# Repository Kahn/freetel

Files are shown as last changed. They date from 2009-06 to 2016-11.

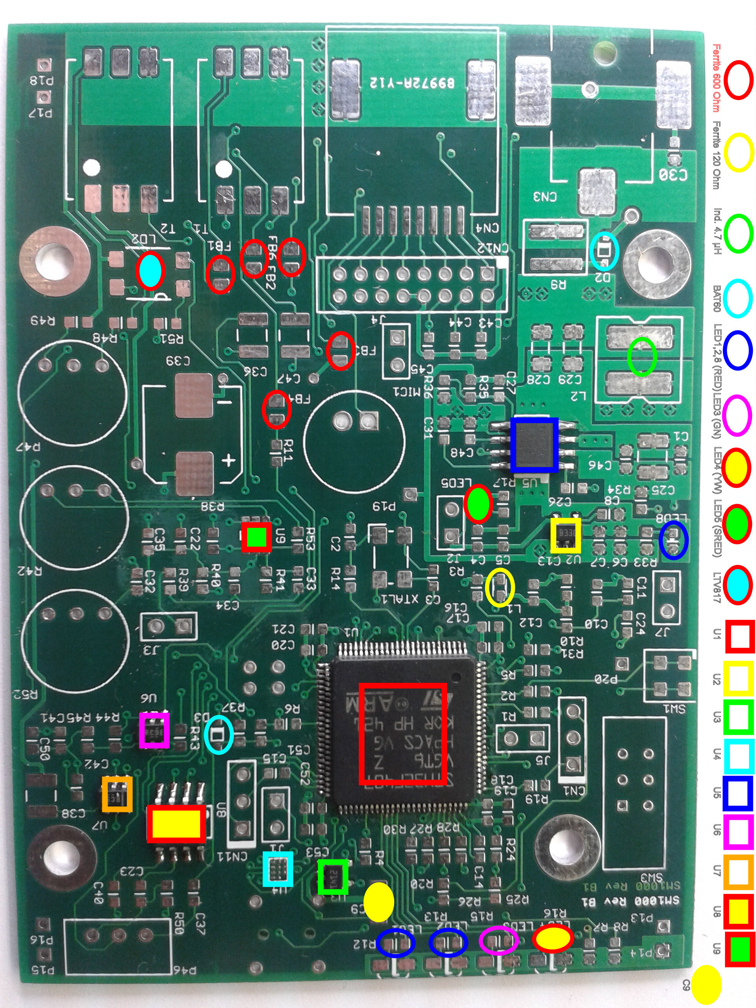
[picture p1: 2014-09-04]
smartmic/doc/other_Parts.jpg

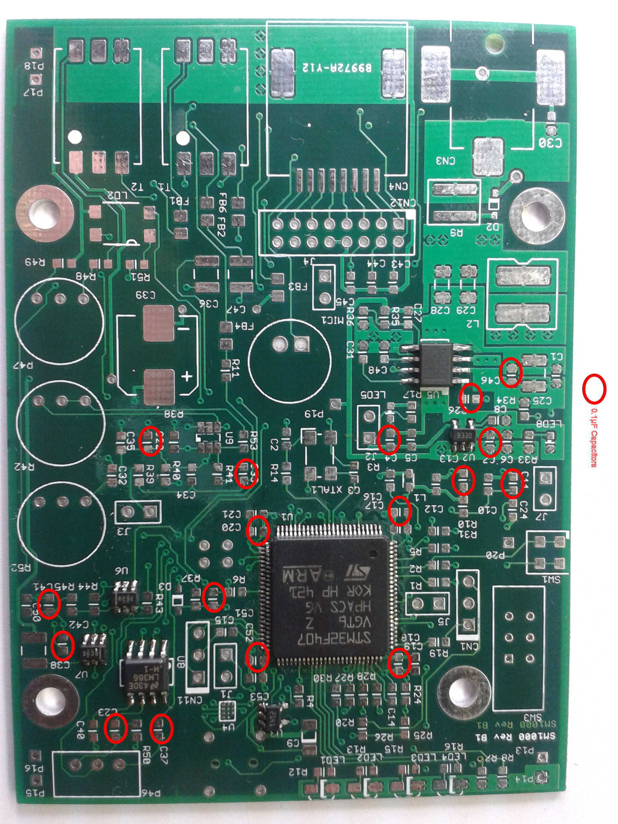
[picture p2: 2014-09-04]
sm2000/doc/Assembly_100nF.jpg

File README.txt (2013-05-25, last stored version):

README.txt for foxy
David Rowe
May 25 2013

Introduction
------------

Simple Google Maps application to plot Fox Hunt bearings.

* Screen shot: foxy_screenshot.png

* Based on Google maps V3 API.

* Light weight: On the server we have just a few CGIs and a text file
  database.  A browser cookie is used for storing configuration
  information.  The CGIs are a few lines of shell script, so can run
  on any machine.  Installation involves copying a few files and
  setting a few permissions.

Using Foxy
----------

1/ Point your browser at http://yourserver/foxy.html

2/ Enter the bearing in the text box and left click to add a bearing.

3/ Left click on a bearing to get information.  Right click to delete
a bearing.

Implementation Notes
--------------------

Foxy is implemented in Javascript (foxy.html).  A simple text database
file /var/www/foxy/bearings.txt is used to store bearing
information. Very simple 1 page CGIs written in shell script are used
to access the bearing database.

A browser cookie is used to store config information like the current
map centre.

All the CGI scripts assume a hard coded path of /var/www/bearings for
the bearings.txt database.

Files
-----

  foxy.html        - Javascript code for Foxy
  foxy.css         - style sheet

"cgi-bin" directory:

  addbearing.cgi   - adds a bearing to bearings.txt
  delbearing.cgi   - deletes a bearing from bearings.txt
  getbearings.cgi   - reads bearings.txt database
  cleardb.cgi      - clears database, removing all bearings

Software
--------

You need:

1/ A web server. Apache is assumed in the /usr/lib/cgi-bin path below.
   The paths may be different for other web servers.  Note the path
   to /var/www/foxy is hard coded in the CGI scripts so it's
   best not to change that.

Installation
------------

1/ Server PC

  $ svn co https://freetel.svn.sourceforge.net/svnroot/freetel/foxy
  $ cd foxy
  $ sudo mkdir /var/www/foxy
  $ sudo chmod 777 /var/www/foxy
  $ cp foxy.css foxy.html /var/www/foxy
  $ sudo cp cgi-bin/* /usr/lib/cgi-bin

Tests
-----

1/ Test reading and writing bearings.txt database with your browser:

   http://localhost/cgi-bin/addbearing.cgi?lat=123&lng=456&bearing=90

   $ cat /var/www/foxy/bearings.txt
   123,456,90

   http://localhost/cgi-bin/delbearing.cgi?lat=123&lng=456

   $ cat /var/www/foxy/bearings.txt
   (empty file)

Debugging
---------

1/ Monitor Apache log:

  $ tail -f /var/log/apache2/access.log

2/ Use Firebug on Firefox to single step, set breakpoints etc.

3/ Check bearings.txt database, each line is (lat, lng, IP):

  # cat /var/www/foxy/bearings.txt 

  -34.88548650005714,138.55225324630737,90
  -34.88006501016277,138.55394840240479,180
  -34.87893842193011,138.55278968811035,265
  -34.882511765792316,138.55210304260254,10

4/ The "foxy001" cookie stores our state. On Firefox 3.5 you
   can remove the foxy cookie using Edit-Preferences-Privacy, then
   click on "remove individual cookies".

5/ To manually reset to defaults:
   
   * move to another page (cookie is saved when we exit page)
   * rm -f /var/www/foxy/bearings.txt
   * Delete cookie using step (4) above

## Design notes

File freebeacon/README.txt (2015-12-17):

README.txt for FreeDV Beacon (FreeBeacon)
David Rowe, John Nunan, Richard Shaw
Dec 2015

Introduction
------------

FreeDV 1600 beacon.  Listens for FreeDV signals, then transmits a
reply. Places the received signal files on a web server. Requires a
Linux machine with a sound card and RS232-PTT interface to your radio.
Just one sound card is required.  Can run on machines as small as a
Raspberry Pi.

When a "trigger" string is detected in the rx FreeDV text message
(e.g. "hello beacon", or the beacon callsign), the beacon will
transmit a signal report back to you.

It requires a "txfilename" wave file to transmit, e.g. some one saying
"Hi, I am a FreeDV beacon blah blah".  The signal report is encoded
into the transmit text message.  Make the wave file long enough so
that the the signal report is repeated a few times, say 30
seconds. Transmit will stop when the "txfilename" wave file is played
once.

Freebeacon saves the received audio from the radio AND the decoded
audio as wavefiles.  Use "wavefilewritepath" to specify where they are
written.  The file name is a date and time stamp. The length is
limited to 60 seconds. If you set "wavefilewritepath" to a listable
webserver directory the files will be available for download on the
Web.  To avoid filling your file system write a cron job to clean
these files up once a day.

If your input audio device is stereo note we only listen to the left
channel.

If you have a RS232 serial port (specified with "-c") RTS and DTR is
raised on transmit to key your transmitter, and lowered for receive.

If you are using Raspberry Pi you can use one of the GPIOs for PTT
control of your transmitter using the "--rpigpio" option.  You need to
use the BCM GPIO number so "--rpigpio 11" uses pin 23 of the GPIO
connector.

A whole lot of code was lifted from freedv-dev for this program.

TODO
----

  [X] 48 to 8 kHz sample rate conversion
  [X] Port Audio list devices
  [X] command line processing framework
  [X] beacon state machine
  [X] install codec2
  [X] attempt debug sound dongle
      [X] modify for half duplex
      [X] sample rate option
      [X] prog sound dongle debug
  [X] RS232 PTT code
  [X] writing to wave files
  [X] test mode to tx straight away then end, to check levels, debug RS232
  [ ] FreeDV 700 support
  [ ] daemonise
      + change all fprintfs to use log file in daemon mode
  [X] test on laptop
  [X] test on RPi
  [ ] writing text string to a web page (cat, create if doesn't exist)
  [ ] samples from stdin option to work from sdr
  [ ] monitor rx and tx audio on another sound device
  [ ] option to not tx, just log info, for rx only stations
  [ ] Hamlib support for keying different radios
  [ ] basic SM1000 version
      + add mode, state machine
      + has audio interfaces, PTT, so neat solution

Building and Installation
-------------------------

1. sudo apt-get install subversion cmake sox libsamplerate0-dev portaudio19-dev libsndfile1-dev

2. Build and Install codec2-dev:

    svn co http://svn.code.sf.net/p/freetel/code/codec2-dev
    cd codec2-dev
    mkdir build_linux
    cd build_linux
    cmake ../
    make
    sudo make install

    Note: On my Ubuntu 14 and RPi I had to add an extra search path to the
    ld.conf.d directory to match the path the codec2 .so was installed
    in.

    Check it has found libcodec2.so using:

    ldconfig -v | grep codec2

3. Build FreeBeacon:

    svn co http://svn.code.sf.net/p/freetel/code/freebeacon
    cd freebeacon
    mkdir build_linux
    cd build_linux
    cmake ../
    make

4. Testing:

    Plug in your USB sound card and USB RS232 devices.  Use alsamixer
    to adjust levels on your sound card. F6 lets you select sound cards

    Usage:
      ./freebeacon -h

    List sound devices
      ./freebeacon -l

    Example usage:
      ./freebeacon -c /dev/ttyUSB1 --txfilename ~/codec2-dev/wav/vk5qi.wav --dev 4 -v --trigger hello

    Testing your PTT by making it jump straght into tx mode:
      ./freebeacon -c /dev/ttyUSB1 --txfilename ~/codec2-dev/wav/vk5qi.wav --dev 4 -v --trigger hello -t

    Testing sound cards on RPi:

      $ arecord -l

        **** List of CAPTURE Hardware Devices ****
        card 1: Audio [RIGblaster Advantage Audio], device 0: USB Audio [USB Audio]
        Subdevices: 1/1
        Subdevice #0: subdevice #0

      $ arecord -D hw:1,0 -f S16_LE -r 48000 test.wav
      $ aplay test.wav

    Testing:

      As a first step try playing freebeacon_test.wav from another PC
      into the freebeacon machine input, this file has the trigger
      string "hello" in the txt msg.

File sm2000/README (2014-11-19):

README for SM1000 Project
Rick Barnich KA8BMA and David Rowe VK5DGR 
Created 14 August 2014

Introduction
------------

The SM1000 is an embedded hardware product that allows you to run
FreeDV without a PC. Just plug it into your SSB or FM radio, and you
now have Digital Voice (DV). It’s based on a STM32F4 micro-controller,
has a built in microphone, speaker amplifier, and transformer isolated
interfaces to your radio. It’s about the size of a smart phone, and
can be held in you hand and used like a regular PTT microphone, or sit
near your radio in a small box. SmartMic is slated for production
production in 2014 and will retail for US$195.

The SM1000 is open hardware (TAPR license) and runs open software
(LGPL license).

Notes
------

The original name for the project was SmartMic.  However as this name
is tradmarked in the USA we are now calling the project "the
SM1000".

The SM1000 schematic and PCB are design using Eagle.

The firmware lives in codec-dev/stm32.

Directories
-----------

doc         Documentation, use cases, block diagram, prototype assembly images
SM1000-A    First pass design that was never manufactured but used to collect
            review comment
SM1000-B    Prototype SM1000, small qty of PCBs made and hand loaded
SM1000-C    pre-Beta SM1000. Changes to B to reflect testing / debug process.
            Just 2 made to check changes before Qty 100 beta run.
SM1000-D    Beta SM1000

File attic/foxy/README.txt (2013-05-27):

README.txt for foxy
David Rowe
May 25 2013

Introduction
------------

Simple Google Maps application to plot Fox Hunt bearings.  When run on
a phone it automatically detects position and compass bearing. Placing
Bearings can be placed with a mouse click on non-mobile devices. The
bearings are stored in a text file database so can be shared by anyone
who can reach the server.

* Screen shot: foxy_screenshot.png

* Based on Google maps V3 API.

* Light weight: On the server we have just a few CGIs and a text file
  database.  A browser cookie is used for storing configuration
  information.  The CGIs are a few lines of shell script, so can run
  on any machine.  Installation involves copying a few files and
  setting a few permissions.

* Foxy will stand alone without the server & CGIs, but bearing storage
  won't be persistent and bearings can't be shared.  Good for demos or
  when you can't reach the Internet.

BUGS
----

On mobile devices:
+ Click to add bearings places the bearing at a location offset from the tap location
+ Double click doesn't remove bearings on mobile devices.

Using Foxy
----------

1/ Point your browser at http://yourserver/foxy.html

2/ If running on your phone your bearing will be updated
automatically.  Click on add bearing to add a bearing from your
current position to the map.

3/ The "where Am I" button re-centers the map on your current
position.  This is useful when scroll and zooming moves your position.

4/ The "Click to Add Bearing" check box allow manual placement of
bearings with a mouse click.  Useful for demo and development on
non-mobile devices such as desktops and laptops. This should be
unchecked on mobile devices as pinching/scrolling often generates
spurious "click" events leading to unwanted bearings.

5/ Double click on a bearing to delete it.

Implementation Notes
--------------------

Foxy is implemented in Javascript (foxy.html).  A simple text database
file /var/www/foxy/bearings.txt is used to store bearing
information. Very simple 1 page CGIs written in shell script are used
to access the bearing database.

A browser cookie is used to store config information like the current
map centre.

All the CGI scripts assume a hard coded to a path of
/var/www/foxy/bearings.txt for the bearings.txt database.

Files
-----

  foxy.html        - Javascript & HTML code for Foxy
  foxy.css         - style sheet

"cgi-bin" directory:

  addbearing.cgi   - adds a bearing to bearings.txt
  delbearing.cgi   - deletes a bearing from bearings.txt
  getbearings.cgi  - reads bearings.txt database
  cleardb.cgi      - clears database, removing all bearings

Software
--------

You need:

1/ A web server. Apache is assumed in the /usr/lib/cgi-bin path below.
   The paths may be different for other web servers.  Note the path
   to /var/www/foxy is hard coded in the CGI scripts so it's
   best not to change that.

Installation
------------

1/ Server PC

  $ svn co https://freetel.svn.sourceforge.net/svnroot/freetel/foxy
  $ cd foxy
  $ sudo mkdir /var/www/foxy
  $ sudo chmod 777 /var/www/foxy
  $ cp foxy.css foxy.html /var/www/foxy
  $ sudo cp cgi-bin/* /usr/lib/cgi-bin

Tests
-----

1/ Test reading and writing bearings.txt database with your browser:

   http://localhost/cgi-bin/addbearing.cgi?lat=123&lng=456&bearing=90

   $ cat /var/www/foxy/bearings.txt
   123,456,90

   http://localhost/cgi-bin/delbearing.cgi?lat=123&lng=456

   $ cat /var/www/foxy/bearings.txt
   (empty file)

Debugging
---------

1/ Monitor Apache log:

  $ tail -f /var/log/apache2/access.log

2/ Use Firebug on Firefox to single step, set breakpoints etc.

3/ Check bearings.txt database, each line is (lat, lng, IP):

  # cat /var/www/foxy/bearings.txt 

  -34.88548650005714,138.55225324630737,90
  -34.88006501016277,138.55394840240479,180
  -34.87893842193011,138.55278968811035,265
  -34.882511765792316,138.55210304260254,10

4/ The "foxy001" cookie stores our state. On Firefox 3.5 you
   can remove the foxy cookie using Edit-Preferences-Privacy, then
   click on "remove individual cookies".

5/ To manually reset to defaults:
   
   * move to another page (cookie is saved when we exit page)
   * rm -f /var/www/foxy/bearings.txt
   * Delete cookie using step (4) above

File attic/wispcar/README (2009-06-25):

wispcar README
--------------

David Rowe 22 June 2009

stty is a WRT54GL OpenWRT  binary utility some one had compiled on the web, used
for setting serial port speeds

wispcar.asm is the original code as per the blog post: http://www.rowetel.com/blog/?p=68

wispcarb.asm has a mod to the watchdog timer to stay off, used for battery testing

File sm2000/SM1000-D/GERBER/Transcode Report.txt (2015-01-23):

   ---- Transcoding 'C:\Users\rbarnich\smartmic\SM1000-D\GERBER\SM1000-D.ast' ----   Fri Jan 23 12:14:49 2015

D10   --> D100
D11   --> D101
D12   --> D102
D13   --> D103
D14   --> D104
D15   --> D105
-----------------------------------------------------------------

   ---- Transcoding 'C:\Users\rbarnich\smartmic\SM1000-D\GERBER\SM1000-D.bps' ----   Fri Jan 23 12:14:49 2015

D10   --> D106
D11   --> D107
D12   --> D108
D13   --> D109
-----------------------------------------------------------------

   ---- Transcoding 'C:\Users\rbarnich\smartmic\SM1000-D\GERBER\SM1000-D.drt' ----   Fri Jan 23 12:14:56 2015

D10   --> D110
D11   --> D111
D12   --> D112
D13   --> D113
-----------------------------------------------------------------

   ---- Transcoding 'C:\Users\rbarnich\smartmic\SM1000-D\GERBER\SM1000-D.L1' ----   Fri Jan 23 12:14:56 2015

D10   --> D114
D11   --> D115
D12   --> D116
D13   --> D117
D14   --> D118
D15   --> D119
D16   --> D120
D17   --> D121
D18   --> D122
D19   --> D123
D20   --> D124
D21   --> D125
D22   --> D126
D23   --> D127
D24   --> D128
D25   --> D129
D26   --> D130
D27   --> D131
D28   --> D132
-----------------------------------------------------------------

   ---- Transcoding 'C:\Users\rbarnich\smartmic\SM1000-D\GERBER\SM1000-D.L2' ----   Fri Jan 23 12:14:56 2015

D10   --> D133
D11   --> D134
D12   --> D135
D13   --> D136
D14   --> D137
D15   --> D138
D16   --> D139
D17   --> D140
D18   --> D141
D19   --> D142
D20   --> D143
D21   --> D144
D22   --> D145
D23   --> D146
-----------------------------------------------------------------

   ---- Transcoding 'C:\Users\rbarnich\smartmic\SM1000-D\GERBER\SM1000-D.L3' ----   Fri Jan 23 12:14:56 2015

D10   --> D147
D11   --> D148
D12   --> D149
D13   --> D150
D14   --> D151
D15   --> D152
D16   --> D153
D17   --> D154
D18   --> D155
D19   --> D156
D20   --> D157
D21   --> D158
D22   --> D159
D23   --> D160
D24   --> D161
D25   --> D162
-----------------------------------------------------------------

   ---- Transcoding 'C:\Users\rbarnich\smartmic\SM1000-D\GERBER\SM1000-D.L4' ----   Fri Jan 23 12:14:56 2015

D10   --> D163
D11   --> D164
D12   --> D165
D13   --> D166
D14   --> D167
D15   --> D168
D16   --> D169
D17   --> D170
D18   --> D171
D19   --> D172
D20   --> D173
D21   --> D174
D22   --> D175
D23   --> D176
D24   --> D177
D25   --> D178
D26   --> D179
D27   --> D180
D28   --> D181
D29   --> D182
D30   --> D183
D31   --> D184
D32   --> D185
D33   --> D186
D34   --> D187
D35   --> D188
-----------------------------------------------------------------

   ---- Transcoding 'C:\Users\rbarnich\smartmic\SM1000-D\GERBER\SM1000-D.oln' ----   Fri Jan 23 12:14:56 2015

D10   --> D189
-----------------------------------------------------------------

   ---- Transcoding 'C:\Users\rbarnich\smartmic\SM1000-D\GERBER\SM1000-D.slk' ----   Fri Jan 23 12:14:56 2015

D10   --> D190
D11   --> D191
D12   --> D192
D13   --> D193
D14   --> D194
D15   --> D195
-----------------------------------------------------------------

   ---- Transcoding 'C:\Users\rbarnich\smartmic\SM1000-D\GERBER\SM1000-D.smb' ----   Fri Jan 23 12:14:56 2015

D10   --> D196
D11   --> D197
D12   --> D198
D13   --> D199
D14   --> D200
D15   --> D201
D16   --> D202
D17   --> D203
D18   --> D204
D19   --> D205
D20   --> D206
D21   --> D207
D22   --> D208
D23   --> D209
D24   --> D210
D25   --> D211
D26   --> D212
D27   --> D213
D28   --> D214
D29   --> D215
-----------------------------------------------------------------

   ---- Transcoding 'C:\Users\rbarnich\smartmic\SM1000-D\GERBER\SM1000-D.smt' ----   Fri Jan 23 12:14:56 2015

D10   --> D216
D11   --> D217
D12   --> D218
D13   --> D219
D14   --> D220
D15   --> D221
D16   --> D222
D17   --> D223
D18   --> D224
D19   --> D225
D20   --> D226
D21   --> D227
D22   --> D228
D23   --> D229
D24   --> D230
D25   --> D231
D26   --> D232
D27   --> D233
D28   --> D234
D29   --> D235
D30   --> D236
D31   --> D237
D32   --> D238
D33   --> D239
D34   --> D240
D35   --> D241
D36   --> D242
D37   --> D243
D38   --> D244
D39   --> D245
D40   --> D246
D41   --> D247
D42   --> D248
D43   --> D249
D44   --> D250
D45   --> D251
D46   --> D252
D47   --> D253
-----------------------------------------------------------------

   ---- Transcoding 'C:\Users\rbarnich\smartmic\SM1000-D\GERBER\SM1000-D.tps' ----   Fri Jan 23 12:14:56 2015

D10   --> D254
D11   --> D255
D12   --> D256
D13   --> D257
D14   --> D258
D15   --> D259
D16   --> D260
D17   --> D261
D18   --> D262
D19   --> D263
D20   --> D264
D21   --> D265
D22   --> D266
D23   --> D267
D24   --> D268
D25   --> D269
D26   --> D270
D27   --> D271
D28   --> D272
D29   --> D273
D30   --> D274
-----------------------------------------------------------------

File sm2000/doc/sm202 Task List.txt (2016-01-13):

Goals
=====

To demonstrate advanced VHF/UHF Digital Voice features on an open software and hardware platform.

[ ] feasibility of "$100" TDMA repeater
    + show our radio working as a TDMA repeater without a diplexor
    + temporary mount on hill top, city wide coverage
    + no split so saves spectrum, potentially low cost (to fill coverage gaps easily)
[ ] 10dB weak signal performance gain over analog FM and 1st gen DV
    + "smackdown" video of current state of the art against our solution
[ ] diversity to handle multipath
    + TDMA diversity, switch rx LO quickly
    + demo overcoming large fades
[ ] wideband audio
    + for example use 10dB gain to send 10 kbit/s Skype type audio over channel
[ ] high bit rate data
    + 10 - 100 kbit/s
[ ] low cost
    + several hundred $ sales price
    + approx $100 BOM

Project Workflow
================

Manhatten Prototype -> Sch Entry -> PCB Design -> Load and Test -> Demos
       /\                                               /\
       ||                                               ||
 Proto Modem SW                                      Modem SW
                                                     UI SW
                                                     Driver SW

Themes
======

+ Full SDR so we can define waveform
+ SSB up and down converters to allow full waveform control
+ no SoCs
+ Demos of advanced DV features is "enough".  We don't need
  sparkling performance in other areas such as all RF specs.

Task List
=========

[ ] Documentation
  [X] Block diagram
  [X] Uses cases in paragraph form
  [X] RF design spreadsheet
      [X] cascaded Gain 
      [X] cascaded NF
      [ ] cascaded IP3
  [ ] Power budget spreadsheet
      [ ] Current per active device
      [ ] Power dissipation per active device
      [ ] Resistor power dissiapation
          + RF bias currents can be high
          + don't want to smoke and SM parts
      [ ] Summary for each rail
  [ ] Specs
      + We don't care too much about IP3, Blocking, ACS, tx phase noise,
        power consumption, they can be modest, equivalent to middle of 
        range VHF radios.
      + We do care about the following.  Check off when demonstrated on
        prototype of Rev A
      [X] 12VDC operation
      [X] NF < 2dB
      [X] MDS (1200 bit/s 2FSK at BER < 0.03) of < -133dBm   
      [ ] MDS (1200 bit/s 2FSK at BER < 0.03) of < -130dBm  (3dB de-sensitisation)
          with -20dBm blocking signal outside of 144 - 148 MHz
          [ ] spot check at 88, 108, 150, 200 MHz
      [ ] 1W tx power with spurious emissions -45dBC

[ ] UI ideas:
    [ ] ESP8266 boards: $7 Wifi interface
        + Or Edwin's boards
    [ ] Twitter's open source 'Bootstrap'
    [ ] BTLE module from Adafruit
    [ ] Websocket
        + what does server look like?
    [ ] Hamlib back end?

[ ] Remaining Manhatten Prototype Tasks
    + Manhatten Style prototype used to build and test as much as possible
    [X] 1W PA
    [X] PIN diode TR switch
    [X] PA filter
    [X] Input (1st) BPF
    [ ] TDMA switching
        [ ] how to switch PS rails
        [ ] tx and rx meet specs

[ ] Parts Selection
    + cross off below when part selected and tested in prototype
    [ ] New audio amp chip
        + bit better, higher power than LM386
    [X] General purpose VHF transistors
    [X] General purpose IF transistors
    [X] 1st mixer: ADE-1 
    [X] RF switches
        + Brady has suggest AS17992LF
    [X] 1W PA transistor
    [ ] LCD
        + Could use cheap Nokia 5110, at least in first rev. Well documented and libraried.
    [ ] encoder
    [X] first LO: Si5351
        + also 2nd LO
        [X] optional Si570
            + low phase noise soldered in option, provide footprint
            + Si5351 still used as 2nd LO
    [X] Prototype parts list to Edwin for review
        + just major parts, semiconductors
        + make sure they are obtainable
        + look for low cost equivalents

[ ] Use Cases
    + need software/test procedure to support the following use cases
    [ ] test modes
        + useful for devevelopment and debugging
        [ ] rx BER
            + prints BER on LCD when continuous 2FSK/4FSK test frames sent
        [ ] tx BER
            + sends continuous test frames using 2FSK/4FSK
    [ ] VHF FM radio
    [ ] Open Source PTT VHF FreeDV radio
        + continuous or TDMA?  Can they be the same?
    [ ] TDMA Repeater
    [ ] Diversity rx
        + use 2nd output from 5351
    [ ] Setting frequency and mode
        + how to select frequency?  What combinations of buttons
          and encoder.
        + do we need a full 0-9 keyboard?
        + should we use a PC or remote device as primary input device
        + does position of buttons/encoders/style of buttons make it easy 
          to use, e.g. set a frequency
    [ ] Changing waveform

[ ] Software Modules
    + see sm201 Block Diagram page 2
    [ ] VHF Modem
        + cont mode first, we can adpat to burst/TDMA mode next
        [ ] ideal non-coherent 2FSK/4FSK BER versus Eb/No perf
        [ ] tracks +/- 500ppm sample clock offsets with no impl loss
        [ ] +/- 5kHz frequency offset acquisition in 1000ms on continuous signal
        [ ] C/Octave versions
        [ ] user defined symbol rate (nominal 1200, 2400), carrier freq, sample rate
            [ ] can it cope with say 3000 symb/s to allow time for TDMA guard times and sync?
                + e.g. a gd fit with integerat Fs/Rs ratios
                + might need TDMA design at same time to answer this question
        [ ] variable nin style demod C function call, approx 20ms packets
            [ ] DR to review function headers
        [ ] automated test script to copare C and Octave units results
            + to ensure identical implementation 
        [ ] command line ./mfsk_tx and ./mfsk_rx 
        [ ] demo OTA (1200/2400/2FSK/4FSK) using SSB radios or SDR
    [ ] VHF protocol
        + do we need two modes, cont & TDMA?
        + or is there a way to combine?  So one rx does both?  Autobaud?
        + can we optionally use FM friendly machester encoded waveform?
    [ ] TDMA framework around modem, burst modem
    [ ] rx TDMA diversity
    [ ] test frame tx/rx modes
    [ ] New Drivers
        [ ] LCD
        [ ] Encoder
        [ ] Si570
            [ ] TDMA clock switching
        [ ] Si5351
            [ ] TDMA clock switching              
    [ ] UI for setting a frequency
    [ ] USB console
    [ ] USB tx/rx signal streaming
    [ ] Code to support running Modes
        [ ] Analog FM
        [ ] TDMA repeater
        [ ] Diversity RX
        [ ] FreeDV PTT TDMA radio

[ ] Risks
    + check off when risk has been nailed, e.g. by experiment/test
    [X] Can we use ADE-1 bir-directional?
        + yes, use TIA and PIN diode switching
    [X] coupled res in shielded box or cots part?
        + make little shields out of blacnk PCB
        + just make box, doesnt need lids
    [X] how to switch mixer/xtal filter
        + tx modulator transistor is part of rx load
        + alo use of TIA
    [X] Is NE602/612 still easy to get?
    [X] ADC perf
        + SFDR etc, which is why we run it as 100kHz
        + if not good enough we'll need an external ADC
        + test against two tone, MDS and ACR
        + Result: met 135dBm spec on prototype so OK
    [X] Power dissipation of active devices and resistors
        + easy to exceed limits in SM resistors and transistors
        + RF drivers draw lots of current
        + mitigation: power spereadhseet in doc section
        + looks good, see also email to Rick 28/12/15 sub: "sm205 powr budget"
    [X] IF termination of 1st mixer
        + how to test if this is OK -> Sweep with R/L bridge
    [X] do we need a way to bypass the LNA?
        + or is it OK even with strong signals
        + mitigation: cascaded IP3 calculations in doc section
                      if this compares to current middle range radios then OK
        + decided to keep in cct, pending strong sig tests
    [ ] xtal filter power
        + what is the limit, how many dBm are we using at the moment?
    [X] prototype RX works 
        + 1200 bit/s 2FSK at < -133dBm with BER < 0.03
        + theory with NFis -134dBm at 0.02
    [ ] prototype TX works
        + 1200 bit/s 2FSK at 1W spurious -45dBC
        + demod by SDR at high SNR with 0 BER
    [ ] TDMA switching
        + demonstrate design supports tx/rx switching fast enough for TDMA
        [ ] tx/rx power supply rail swicthing
    [X] RF detector
        + pwr calibration, shutdown with no load
    [X] PA
        [X] 1W for 5 minutes
        [X] adjust PA from uC via Vgg
            + not tested from uC yet
    [ ] Dual freq TDMA
        + tx and rx?  We need a way to tx on two different freqs
        + use same clock for tx and rx?
    [X] 2ND LO dist and swicthing
        + 150pF to NE602?
        + attenuator?
        + selecting LOs?
    [ ] Spreadsheet with Z matches
    [ ] check power consumption on each rail matches regulator limits

[ ] Sch Entry
    [X] linear reg option for vadc ADC and vref
        + jumper select to test
    [ ] put extra 0805 or 1206 components in parallel for Z matching and DNL
        + e.g. on collectors and emitters of RF amps
        + between building blocks
    [ ] inductors
        [X] coil winding details if air core
        [X] tolerance
        [X] statement on Q so we know if we can subs SM or need Hi-Q air-core
        [X] alignment of coils WRT each other to prevent coupling
        [ ] location of shields if rqd
        [ ] how to adjust/if adjustment rqd
            + e.g. adjust filter by variation in coild spacing against filter spec
    [X] 4 by 0.1 inch pin headers in a square pattern to disconnect building blocks    
    [X] select Si570 with a jumper
    [ ] review of foot prints for discretes
        + ease of debug, e.g. if we need to add a LC filter
        + power handling
    [X] check package of each L
        + make sure enough room for hand wound air core versions
    [X] specify locations of 4 pin 50 ohm breaks
        + 0805 0 ohm, or break for isolation and testing
    [X] PS filter for PA
    [X] research TXCO for si5351 clock input
        + perhaps include as option
        + does it have to be 25MHz?
        + decided not to run with TXCO for prototype, as freq stab not critical
    [ ] how to connect SCA/SCL on clock chips to uC?
        + is there a separate enable?
    [ ] LEDs for control signals/rails
    [X] Add a Av=2 op-amp to take 3v3 DAC max from uC to 5V
        max for Vgg driving PA final Q14.  Will need to be powered by 5V rail.
        This is a preacuation in case we need > 3V for some FETs
    [ ] Vgg PWM filtering
        + we use PWM to genrate a bias for VGG
        + this needs to be filtered so we don't modulate the PA output
        + but we also need a faily fast respomse time, e.g. 1ms from
          0V to Vgg set point to modulate PA power for TDMA.
    [ ] consider shared clock for Si5351 and uC
   
[ ] Rev A PCB Layout
    [ ] footprints for all devices
    [ ] will air core inductors be thru hole parts?
        + nice big pads as some rework likely
    [ ] avoid vias for RF nets, all routing on top layer
        + gnd plane next layer down
    [ ] block diagram showing map of building blocks
        + separate analog and digital        
    [ ] shields
        [ ] where do we put sheilds
        [ ] how to fabricate?
            + try small pieces of black PCB
        [ ] foot prints
    [ ] probe points
        + VHF freindly with nearby grounds
        + something I can sit a CRO probe in, with short ground, like 2 thru hole donuts
        + 1k series resistor to 50 ohm points so we can probe with 50 ohm spec-an or scope
        + can we get a 50-ohm probe for cro or spec-an?  
          So mechanically it can sit on board?
    [ ] 50 ohm points for spec an?
    [ ] 4 pin 0.1 inch headers to disconnect building blocks so we can insert 
        tracking gen and spec an

[ ] Manufacture
    [ ] is it feasible to have 6 turn coils with one turn taps in production?
        + what are the alternatives
    [ ] can people wind toroids?
    [ ] How will we test and align?

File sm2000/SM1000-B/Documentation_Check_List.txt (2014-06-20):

PCB Documentation Check List

PCB:  ____________________     ASM: ____________________     VARIANT: ____________________

DATE: ____________________     By:  ____________________     Form: 06/20/14

1.  [ ]	Run ERC on schematic & fix any errors.
2.  [ ]	Run DRC on pcb & fix any errors.
3.  [ ]	Update revision level and  titles on schematic and PCB.
4.	[ ] Run BOM-AM-19 on schematic and check for undefined parts. 	
5.	[ ]	Generate BOM.csv  file. Use parts data base & update/add new parts.
6.  [ ]	Generate BOM.xls and BOM.pdf files and move to MFG folder.
7.	[ ]	Generate LOC.csv file.
8.  [ ]	Generate LOC.xls and LOC.pdf files and move to MFG folder
9.	[ ]	Generate  Schematic PDF file and move to MFG folder.
10.	[ ]	Run drillcfg (inches)
11.	[ ]	Run drilllegend.ulp and generate drill table(drill legend) on PCB.
12. [ ]	Generate DRL-TBL.pdf (DRILL TABLE) and copy to MGF folder.
13.	[ ]	Run CAM   job 4LPlus-Sunstone.cam on board.
14. [ ] Run CAM job Exellon.cam on board.
15.	[ ]	Move Gerber files to GERBER folder
16.	[ ]	Use Viewmate to check layout & produce .PDF file of all Gerber layers. Move pdf to MFG folder
17.	[ ]	Generate & move .PDF of BOM & LOC files to MFG folder
18. [ ]	Generate assembly drawing for top & bot layers. Move .pdf to MFG folder.
19.	[ ]	Update readme files(see other cards) for Gerber & MFG folders.
20. [ ]	Add dimensions to .brd. Generate .pdf file and move to MFG folder
21.	[ ]	Generate  .zip files on files in GERBER and MFG folders respectively.
22. [ ]	Move .sch, .brd, .lbr, MFG.zip & GERBER.zip to RELEASE Folder.

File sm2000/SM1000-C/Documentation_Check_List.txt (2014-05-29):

PCB Documentation Check List

PCB:  ____________________     ASM: ____________________     VARIANT: ____________________

DATE: ____________________     By:  ____________________

1.  [ ]	Run ERC on schematic & fix any errors.
2.  [ ]	Run DRC on pcb & fix any errors.
3.  [ ]	Update revision level and  titles on schematic and PCB.
4.	[ ] Run BOM-AM-19 on schematic and check for undefined parts. 	
5.	[ ]	Generate BOM.csv  file. Use parts data base & update/add new parts.
6.  [ ]	Generate BOM.xls and BOM.pdf files and move to MFG folder.
7.	[ ]	Generate LOC.csv file.
8.  [ ]	Generate LOC.xls and LOC.pdf files and move to MFG folder
9.	[ ]	Generate  Schematic PDF file and move to MFG folder.
10.	[ ]	Run drillcfg (inches)
11.	[ ]	Run drilllegend.ulp and generate drill table(drill legend) on PCB.
12. [ ]	Generate DRL-TBL.pdf (DRILL TABLE) and copy to MGF folder.
13.	[ ]	Run CAM  (board & excelon) jobs on board.
14.	[ ]	Move Gerber files to GERBER folder
15.	[ ]	Use Viewmate to check layout & produce .PDF file of all Gerber layers. Move pdf to MFG folder
16.	[ ]	Generate & move .PDF of BOM & LOC files to MFG folder
17. [ ]	Generate assembly drawing for top & bot layers. Move .pdf to MFG folder.
18.	[ ]	Update readme files(see other cards) for Gerber & MFG folders.
19. [ ]	Add dimensions to .brd. Generate .pdf file and move to MFG folder
20.	[ ]	Generate  .zip files on files in GERBER and MFG folders respectively.
21. [ ]	Move .sch, .brd, .lbr, MFG.zip & GERBER.zip to RELEASE Folder.

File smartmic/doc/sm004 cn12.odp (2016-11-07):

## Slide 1

PATCH PANEL

CN12

8

RJ45

8

CN4

SPKR GND

9

MIC GND

10

7

7

11

12

6

5

RIG SPKR

6

5

PTT GND

13

4

4

PTT

14

3

RIG PTT

RIG GND

3

MIC

15

2

2

SPKR

16

1

RIG MIC

RIG MIC

1

1

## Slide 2

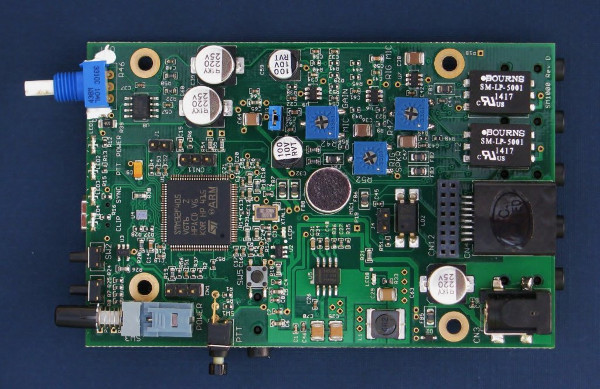
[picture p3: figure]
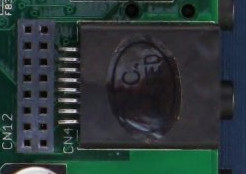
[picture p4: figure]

9

8

1

116

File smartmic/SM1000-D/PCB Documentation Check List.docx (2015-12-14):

PCB Documentation Check List

PCB: SM1000-D __________ ASM: ____________________

VARIANT: None________________

DATE: 01/23/15___________ By: RGB____________________

1. [ ] Update revision levels and titles on schematic and PCB.
2. [ ] Run ERC on schematic & fix any errors.
3. [ ] Run DRC on pcb & fix any errors.
4. [ ] Run drillcfg. Generates filename.drl
5. [ ] Run Tools/drill legend from menu and generate drill table(drill legend) on PCB.
6. [ ] Run BOM-AM-19 on schematic and check for undefined parts.
7. [ ] Generate BOM-filename.csv & BOM-filename.xls files. Use parts data base & update/add new parts.
8. [ ] Generate BOM-filename.pdf file and move to MFG folder.
9. [ ] Generate LOC-filename.csv & LOC-filename.xls files.
10. [ ] Generate LOC-filename.pdf file and move to MFG folder
11. [ ] From Print menu, generate Schematic SCH-filename.PDF file and move to MFG folder.
12. [ ] Generate DRT-filename.pdf (DRILL TABLE) and copy to MGF folder.
13. [ ] Run CAM (Exelon & board) jobs on board.
14. [ ] Move Gerber files to GERBER folder
15. [ ] Use Viewmate to check layout & produce GBR-filename.PDF file of all Gerber layers & move to MFG folder.
16. [ ] Generate assembly AST-filename.pdf and ASB-filename.pdf drawings and move to MFG folder.
17. [ ] Update readme.txt files(gerber & manufacturing) (see other cards) for Gerber & MFG folders.
18. [ ] Add dimensions to PCB, save as DIM-filename.pdf file and move to MFG folder
19. [ ] Generate GERBER-filename.zip and MFG-filename.zip in GERBER & MFG folders respectively.
20. [ ] Move .sch, .brd, .lbr, MFG.zip & GERBER.zip to RELEASE Folder.

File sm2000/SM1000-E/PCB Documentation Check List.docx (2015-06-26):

PCB Documentation Check List

PCB: SM1000-E __________ ASM: ____________________

VARIANT: None________________

DATE: 6/26/15___________ By: RGB___rgb_________________

1. [ X] Update revision levels and titles on schematic and PCB.
2. [ X] Run ERC on schematic & fix any errors.
3. [ X] Run DRC on pcb & fix any errors.
4. [ X] Run drillcfg. Generates filename.drl
5. [ X] Run Tools/drill legend from menu and generate drill table(drill legend) on PCB.
6. [ X] Run BOM-AM-19 on schematic and check for undefined parts.
7. [ X] Generate BOM-filename.csv & BOM-filename.xls files. Use parts data base & update/add new parts.
8. [ X] Generate BOM-filename.pdf file and move to MFG folder.
9. [ X] Generate LOC-filename.csv & LOC-filename.xls files.
10. [ X] Generate LOC-filename.pdf file and move to MFG folder
11. [ X] From Print menu, generate Schematic SCH-filename.PDF file and move to MFG folder.
12. [ X] Generate DRT-filename.pdf (DRILL TABLE) and copy to MGF folder.
13. [ X] Run CAM (Exelon & board) jobs on board.
14. [ X] Move Gerber files to GERBER folder
15. [ X] Use Viewmate to check layout & produce GBR-filename.PDF file of all Gerber layers & move to MFG folder.
16. [ X] Generate assembly AST-filename.pdf and ASB-filename.pdf drawings and move to MFG folder.
17. [ X] Update readme.txt files(gerber & manufacturing) (see other cards) for Gerber & MFG folders.
18. [ X] Add dimensions to PCB, save as DIM-filename.pdf file and move to MFG folder
19. [ X] Generate GERBER-filename.zip and MFG-filename.zip in GERBER & MFG folders respectively.
20. [ X] Move .sch, .brd, .lbr, MFG.zip & GERBER.zip to RELEASE Folder.

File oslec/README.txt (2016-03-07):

Open Source Line Echo Canceller (OSLEC)
=======================================

[[introduction]]
Introduction
------------

Oslec is an open source high performance line echo canceller.  When
used with Asterisk it works well on lines where the built-in Zaptel
echo canceller fails.  No tweaks like rxgain/txgain or fxotrain are
required.  Oslec is supplied as GPL licensed C source code and is free
as in speech.

Oslec partially complies with the G168 standard and runs in real time
on x86 and Blackfin platforms.  Patches exist to allow any Zaptel
compatible hardware to use Oslec.  It has been successfully tested on
hardware ranging from single port X100P FXO cards to dual E1 systems.
Hardware tested includes TDM400, X100P, Sangoma A104, Rhino E1 etc.
It also works well on the link:ip04.html[IP04 embedded Asterisk
platform].

There is also a project underway to use
http://peter.schlaile.de/mISDN/[OSLEC with mISDN].

Oslec is included in many distributions, including Debian, Gentoo,
Trixbox, Elastix, and Callweaver.

[[testimonials]]
Testimonials
------------

So how good is Oslec?  

+ The http://www.trixbox[Trixbox] community have been testing
Oslec, here is a
http://www.trixbox.org/forums/trixbox-forums/open-discussion/need-people-echo-problems[Trixbox
forum thread] that has feedback from many people.  Start about half
way down the page, or search on the string "night and day" :-)

+ The http://callweaver.org/wiki/Zaptel[CallWeaver] project use and recommend Oslec.

+ Here is some feedback from Oslec users:

[Gordon Henderson, posted in the  Asterisk-user mailing list July 21 2008]

________________________________________________________________________
I switched to OSLEC after testing HPEC on TDM400 boards, and found that it 
worked much better and wasn't limited to the restricted mechanism Digium 
uses for licensing (unlikely as it sounds, I have some clients who do not 
have a connection to the public Internet, and never will for their phone 
system)

It also passes the wife test which HPEC didn't.

It's also free (OS as in Open Source), which HPEC isn't, although that 
wasn't my primary reason for using it - ease of use and "workability" was.
_____________________________________________________________________

[Michael Gernoth, Author of the Zaptel MG2 echo canceller]

________________________________________________________________________
Thanks for OSLEC, it's so much better than my hacked KB1 which is called
MG2 :-)
_____________________________________________________________________

[David Gottschalk]

________________________________________________________________________
Once I managed to get OSLEC installed (it was a big job for me, because I was
missing many of the dependancies and knowledge), it immediately fixed the echo
problems I had been unable to get rid of to date despite lots and lots of
tweeks, tests and fiddling.  Even more suprisingly, it appears to converge
almost immediately from my initial test.

This code is the best since thing since, well, Asterisk !!!
_____________________________________________________________________

[Nic Bellamy, Head Of Engineering; Vadacom Ltd]

________________________________________________________________________
Short version: KB1 < MG2 < OSLEC < HPEC

In the open source line echo canceller category, OSLEC is so far the 
best I've seen.

It converges reasonably fast, and thanks to it's dual-path approach, 
will converge, albeit a bit slowly, on nasty echo paths where cancellers 
like KB1 and MG2 will fail entirely.

The nonlinear processor and comfort noise generator provide for a far 
more pleasant listening experience than KB1/MG2.

It's not quite up to the grade of ADT's G.168 canceller used in Digiums 
HPEC product in terms of convergence speed or tail coverage.
_____________________________________________________________________

[Pawel Pastuszak, Astfin.org]

________________________________________________________________________
Since I installed the first version of OSLEC I was hooked.... It's
been several months now since the alpha version was released; after
using OSLEC Mark and I agreed that we had to have OSLEC as the main
echo cancellation in the Astfin distribution.
________________________________________________________________________
                                                                             
[Pavel Selivano, Parabel Ltd]

________________________________________________________________________
I've been working with Oslec since March of 2007.  Oslec has had some
problems, but, thanks to David, they are solved.  Now, I can say Oslec
is time-tested.  The best, I can note - it is still under development
(with feed-back).  Thank you David for your good deed.

BTW: comparison to Intel IPP's echo canceler have shown, Oslec is very
good :-)
________________________________________________________________________

[[news]]
Oslec News
----------

+ Saturday, June 7, 2008: We have worked out how to use <<rhino,Oslec with
Rhino>> PRI cards.  Thanks Juan Manuel Coronado!

+ Friday, May 16, 2008: Oslec Road Map.  I have kicked off a
discussion of the
http://sourceforge.net/mailarchive/forum.php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[development
roadmap] for Oslec.  Is hardware echo cancellation headed for
extinction?

+ Friday, May 16, 2008: Oslec chosen as the **default**
http://sourceforge.net/mailarchive/forum.php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[echo
canceler for Debian].  Thanks Tzafrir for your work on packaging Oslec
for Debian!

+ Tuesday, May 13, 2008: link:/blog/?p=64[Oslec versus the SPA 3000]
ATA.  A blog post comparing the SPA 3000 echo cancellation to Oslec on
a problem FXO line.

+ Wednesday, February 11, 2008: Oslec mailing list created.  Due to
popular demand (well, Tzafrir mainly!) there is now an
https://lists.sourceforge.net/lists/listinfo/freetel-oslec[Oslec
mailing list].

+ Sunday, February 10, 2008: Zaptel 1.4.8 patch checked into SVN,
thanks Tzafrir.

[[install]]
Installing  OSLEC with Asterisk/Zaptel
--------------------------------------

Notes:

+ This process also installs a system for sampling echo signals that
  is helpful for developing oslec.

+ I assume Asterisk is already installed and tested.

+ I assume you are running Linux 2.6 and Zaptel 1.2.13 or a later
  1.2/1.4 version of Zaptel.

+ I assume you are using a Digium TDM400 line interface card.  Change
  the "insmod wctdm.ko" line below to match your line interface
  hardware (e.g. wcfxo for a X100P).

+ For Zaptel 1.4.x replace the 1.2.13 text below 1.4.x (tar ball and
  patch file).

+ For Linux 2.4 replace the "insmod moduleXYZ.ko" lines below with
  "insmod moduleXYZ.o".

1/ Download, build and install oslec:

  $ cd ~
  $ wget http://www.rowetel.com/ucasterisk/downloads/oslec-0.1.tar.gz
  $ tar xvzf oslec-0.1.tar.gz
  $ cd oslec-0.1
  $ make
  $ insmod kernel/oslec.ko 

Optional: If you want the latest and greatest, replace the "wget" step
with:

  $ svn co http://svn.astfin.org/software/oslec/trunk/ oslec

NOTE: There are patches for Zaptel 1.2.13, 1.2.18, 1.2.24, 1.4.1,
1.4.3, 1.4.4, 1.4.7.1, 1.4.8, 1.4.9.2 and 1.4.11.  It's quite easy to
port to other versions, please feel free to send me a new patch should
you get Oslec working with another Zaptel version.  If you can't see a
patch for your Zaptel version try
http://svn.astfin.org/software/oslec/trunk/kernel[Oslec SVN] for the
latest patches.

2/ Build, patch and install Zaptel.  First obtain zaptel-1.2.13.tar.gz and:

  $ tar xvzf zaptel-1.2.13.tar.gz
  $ cd zaptel-1.2.13
  $ ./configure
  $ patch < ../oslec-0.1/kernel/zaptel-1.2.13.patch    (see note 1 below)
  $ cp ../oslec-0.1/kernel/dir/Module.symvers .        (see note 2 below)
  $ make
  $ insmod zaptel.ko
  $ insmod wctdm.ko 
  $ ./ztcfg
  $ asterisk

NOTE: 1: Use -p1 option for zaptel-1.4.9.2 and above

NOTE: 2: The "cp Module.symvers" step above is optional on many systems;
it stops warnings like WARNING: "oslec_echo_can_create" [zaptel.ko]
undefined!". However on some Linux machines zaptel will not compile
without this step.

3/ These options in zapata.conf are important:

---------------------------------------------------------------------
    echocancel=yes
    echocancelwhenbridged=no
    ;echotraining=400
---------------------------------------------------------------------

The *echocancelwhenbridged=no* allows faxes to pass from FXS to FXO
ports without interference from the echo canceller.  This option is
important for fax signals.

Make sure *echotraining* is disabled when using Oslec - this is not
supported and if enabled will cause the channel to be silent (i.e. no
audio will pass through).

4/ The settings above have been shown to reliably cancel echo in 95%
of cases.  If you can still hear echo you may have one of the rare
cases where your echo is longer than 16ms.  To configure Oslec with a
32ms tail:

---------------------------------------------------------------------
    echocancel=256
    echocancelwhenbridged=no
    ;echotraining=400
---------------------------------------------------------------------

Then restart Asterisk.

[[pbxinaflash]]
PBX in a Flash Install
----------------------

Here are the
http://pbxinaflash.com/forum/showthread.php?t=100&page=3[Oslec install
procedure] for PBX in a Flash. Check the 7-24-08 post in this thread
by Alex728 for Zaptel-1.4.11 instructions.  Thanks JD Austin and Alex.

Matt Keys has suggested that the PBX in a Flash install procedure also
worked well for Ubuntu server.
 
[[rhino]]
Rhino PRI cards
---------------

The rhino-2.2.6 driver for Rhino PRI cards has software echo
cancellation disabled by default.  This means there is no echo
cancellation unless you opt for the Rhino hardware echo cancellation
module.  However the driver is easy to hack to enable software echo
cancellation, and hence Oslec.

In the rhino-2.2.6 driver, file r1t1_base.c, r1t1_receiveprep
function, around line 800:

---------------------------------------------------------------------
static void r1t1_receiveprep(struct r1t1 *rh, int nextbuf)
{
/*
    int x;

    for (x=0;x<rh->span.channels;x++) {
        zt_ec_chunk(&rh->chans[x], rh->chans[x].readchunk, rh->ec_chunk2[x]);
        memcpy(rh->ec_chunk2[x],rh->ec_chunk1[x],ZT_CHUNKSIZE);
        memcpy(rh->ec_chunk1[x],rh->chans[x].writechunk,ZT_CHUNKSIZE);
    }
*/
    zt_receive(&rh->span);
}
---------------------------------------------------------------------

**Solution 1:** Simply un-comment the code and rebuild the driver:

---------------------------------------------------------------------
static void r1t1_receiveprep(struct r1t1 *rh, int nextbuf)
{

    int x;

    for (x=0;x<rh->span.channels;x++) {
        zt_ec_chunk(&rh->chans[x], rh->chans[x].readchunk, rh->ec_chunk2[x]);
        memcpy(rh->ec_chunk2[x],rh->ec_chunk1[x],ZT_CHUNKSIZE);
        memcpy(rh->ec_chunk1[x],rh->chans[x].writechunk,ZT_CHUNKSIZE);
    }

    zt_receive(&rh->span);
}
---------------------------------------------------------------------

**Solution 2:** Bob Conklin from Rhino has suggested this fix that
they have in SVN trunk:

---------------------------------------------------------------------
static void r1t1_receiveprep(struct r1t1 *rh, int nextbuf)
{
    if (!rh->dsp_up)
        zt_ec_span(&rh->span);
    zt_receive(&rh->span);
}
---------------------------------------------------------------------

This version automatically falls back to software echo cancellation if
the DSP-based hardware echo cancellation is not present.  Thanks
Bob!

[[status]]
Status
------

Current status is considered *Stable*.  As of 3 January 2008:

+ Thousands of people (estimated) using Oslec on x86 platforms now.
Oslec is stable and works well.  Oslec has been included in many
distributions, including Debian, Gentoo, Trixbox, Elastix, and
Callweaver.

+ Oslec works well on many different types of hardware, from single
port $10 X100P cards to dual E1s.

+ Oslec has been partially optimised for the embedded Blackfin
DSP/RISC CPU and now runs in real time on the link:ip04.html[IP04 Open
Hardware IP-PBX].  Running on several hundred IP04s now.

+ Real time runs well on FXO/FXS lines where the other Zaptel echo
cancellers (including the latest MG2) struggle.  No tweaks like
levels, fxotrain, or even opermode required so far.  Hardware used for
tests was a TDM400 and X100P card.

+ The simulation code passes many but not all of the G168 tests.
Some problems with high level signals near 0dBm0 and some of the G168
echo models.  Passes maybe 90% of the tests attempted so far, however
not all of the tests and/or range of test conditions have been
attempted yet.  The fails are close calls (like a few dB off), not
complete breakdowns of the algorithm.

+ Oslec has been specifically developed to work with low cost line
interface hardware like the X100P.  The X100P has problems with 60Hz
hum and DC offset in the rx signal, which interfere with the echo
canceller algorithm.  However with the addition of some high pass
filters good results with X100P cards have been obtained using Oslec.
Line interfaces based on chips such as those from Silicon Labs
(e.g. the TDM400) have no DC offset or hum which is one reason they
tend to perform better.

+ Oslec has been optimised to deal with specific problems encountered
with soft phone clients.  Due to the high quality microphones and
sound blaster hardware used on PCs, more low frequency energy is
present compared to normal telephone signals.  When this low frequency
energy is sent to a hybrid it can force the hybrid into a non linear
mode.  Echo cancellers assume a linear hybrid so any non-linearities
make the echo canceller fall over.  The solution is to high pass
filter energy sent to the hybrid to ensure excessive low frequency
energy is removed.  This means inserting a HP filter in the tx path.

[[directories]]
Directories
-----------

The http://svn.astfin.org/software/oslec/trunk/[Oslec SVN repository]
combines several projects (mainly spandsp) used to develop, test, and
run oslec.

spandsp : A subset of spandsp to support testing and development of
	  Oslec.  The echo canceller and G168 test suite source code
	  live in here.

user....: User mode apps, e.g. sampling of echo signals and a unit
          test for measuring the execution speed of Oslec.

kernel..: Builds Oslec into a kernel module.  Also contains patches for
	  Zaptel to allow the use of Oslec.

[[diagnostics]]
Run Time Information
--------------------

Set up a call that uses an analog port, then check out /proc/oslec for
real-time stats:

  [root@homework kernel]# cat /proc/oslec/info
  channels....: 1
  mode........: [13] |ADAPTION|NLP|CNG|
  Ltx.........: 0
  Lrx.........: 211
  Lclean......: 211
  Lclean_bg...: 211
  shift.......: 0
  Double Talk.: 1
  MIPs (last)....: 1
  MIPs (worst)...: 7
  MIPs (avergage): 1

You can turn the various mode switches off and on, for example:

   echo 9 > /proc/oslec/mode

turns off comfort noise, but keeps ADAPT and NLP on.  The mode
switches are listed in the
http://svn.astfin.org/software/oslec/trunk/spandsp-0.0.3/src/spandsp/echo.h[echo.h]
header file (#define ECHO_CAN_USE_*).  The /proc interface only
monitors the first Zaptel call you bring up, see
http://svn.astfin.org/software/oslec/trunk/kernel/oslec_wrap.c[oslec_wrap.c]
for more information.
   
There is a GUI for run-time control of Oslec, called the Oslec Control
Panel.  For example you can Enable and Disable the echo canceller in
real time, as you are speaking.  If you Reset the echo canceller you
can hear how long it takes to converge again.

NOTE: The command line tool *dialog* must be installed on your system
to use the Oslec Control Panel.

  $ cd kernel
  $ ./oslec-ctrl-panel.sh 

image::/images/echo/oslec_control_panel.png[Oslec Control Panel]

[[speed]]
Execution Speed and Optimisation
--------------------------------

In the user directory there is a
http://svn.astfin.org/software/oslec/trunk/user/speedtest.c[speedtest.c]
program that measures how many MIPs the echo canceller consumes and
estimates how many cancellers can run in real time.  The current x86
code is vanilla C and could be greatly improved with MMX or SSE
optimisations, some of which are already coded in spandsp.  There is
also much that can be done to improve execution speed on the Blackfin.

Steve's spandsp code includes some support for MMX and SSE2
optimisation.  Define USE_MMX or USE_SSE2 in the Makefile to use this
option.  At this stage only the fir.h filter code is optimised, oslec
would run much faster if lms_adapt_bg() in echo.c was also ported to
MMX/SSE2.  With USE_MMX defined, the speedtest.c program dropped from
33 MIPs to 20 MIPs per channel for 256 taps/32ms.  If using MMX in the
kernel (e.g. with zaptel) make sure you compile zaptel with
CONFIG_ZAPTEL_MMX to ensure the FPU state is saved in the right
places.  

To enable MMX/SSE modify this line of oslec/kernel/Makefile:

----------------------------------------------

all::
        $(MAKE) -C $(KDIR) EXTRA_CFLAGS='$(KINCLUDE) \
        -DUSE_MMX -DUSE_SSE2 -DEXPORT_SYMTAB -O6' \
        SUBDIRS=$(PWD) modules

----------------------------------------------

Thanks Nic Bellamy for help in testing MMX and Ming-Ching Tiew for
providing the correct command line for compiling with MMX/SSE.

Some notes on further optimisation:

1/ How do lots of MIPs in ISR affect total system performance?  For
example if we are using 25% of MIP in ISR does * still run OK?  Find the
CPU load knee different for user versus kernel mode cycles
consumption.

2/ Estimated Oslec MIPs are 5(N)(Fs), N is the filter size (number of
taps), Fs=8000 is the sampling rate.  Factor of 5 is comprised of 1
for each FIR filter (forgeround and background), 2 for LMS, 1 for overhead.
This suggests that when optimised around 10 MIPs for a 32ms tail.

3/ There are some more notes on optimisation for the Blackfin in
http://svn.astfin.org/software/oslec/trunk/spandsp-0.0.3/src/echo.c[echo.c].

[[credits]]
Background and Credits
----------------------

Oslec started life as a prototype echo canceller and G168 test
framework from Steve Underwood's http://www.soft-switch.org/[Spandsp]
library.  Steve wrote much of the DSP code used in Asterisk, and the
Zaptel echo cancellation code is heavily based on his work.

Using the Spandsp G168 test framework, a high performance echo
canceller has been developed and carefully tested.  Working together
with alpha testers the performance was brought to a beta state in June
2005.  <<links,More>>.  Since then many thousands of people have
installed Oslec.

Thanks to Steve Underwood, Jean-Marc Valin, and Ramakrishnan
Muthukrishnan for their suggestions and email discussions.  Thanks
also to those people who collected echo samples for me such as Mark,
Pawel, and Pavel.  Thanks Nic Bellamy for help with testing,
explanation of long path issues, and MMX support.  Thanks Tzafrir for
testing and patches/enhancements and Dmitry for help with
multithreaded and locking issues.

Thanks Vieri for finding a circuit with a tail > 32ms, and Patrick for
submitting a Zaptel 1.2.18 patch.  Thanks Dave Fullerton and Carlton
O'Riley for Zaptel 1.4.3/1.4.4 patches.  Thanks Bill Salibrici for
finding a memory leak. Thanks Michael E. Kromer for submitting a
Zaptel 1.4.7.1 patch, and Tzafrir for the Zaptel 1.4.8 patch.  Thanks
Russ Price for the Zaptel 1.2.24 patch.  Thanks Chris Notley for the
1.4.11 patch.

Thanks to Peter Schlaile for porting Oslec to mISDN.  Thanks also to
Kristijan Vrban for sending me some ISDN hardware so I can help with
the ISDN/Oslec testing!

Thanks to Tzafrir and Faidon for helping debug the muted audio
problems on 64 bit systems.

Thanks Rudolf E. Steiner for testing Oslec on SMP and multiple E1
systems.

[[sample]]
Sampling Zaptel Echo
--------------------

Introduction
~~~~~~~~~~~~

I have developed a system for sampling echo on running Zaptel/Asterisk
systems.  If you do experience any echo with Oslec, please use this
system to sample the echo, then email the sample files to me.  

See the http://www.rowetel.com/blog/?p=18[Part 1 blog post] for more
information on sampling echo.

The nice thing about is that it doesn't interfere with your running
Asterisk system.  If you hear echo at any time you can fire up a
console and run "sample" to capture real-time data from the Zaptel
port.

There are other ways to capture audio from a running Asterisk system,
for example using the built in Asterisk play and record applications.
However this system is designed to capture *exactly* the signals being
fed to & from the echo canceller - preserving the exact timing of the
signals and with no intermediate buffering.  This is very important
for echo cancellation work - the algorithms depend on an exact timing
relationship between the transmit and receive signals.

The system simultaneously captures the receive signal both before
*and* after the echo canceller - something that is difficult to do
with the built in Asterisk functions due to the location of the echo
canceller deep in the Zaptel driver.

If you would like to help further develop Oslec, please
mailto:david_at_rowetel_dot_com[send me] your echo samples! I would
welcome any samples of your echo signals, for example where the echo
canceller isn't working well, and also cases where it does work
well. By comparing the two cases we can learn a lot about the
strengths and weaknesses of the algorithm.

Installing
~~~~~~~~~~

1/ Install Oslec ("HowTo - Run OSLEC with Asterisk/Zaptel" section above).

2/ If you would like to use zaptap without oslec change the selected
   echo canceller in zconfig.c and rebuild/install zaptel.

3/ Compile sample.c:

     # cd user
     # make

4/ Create a device node.  I used major number 33 as it was
   free on my PC:

     # mknod -m 666 /dev/sample c 33 0

   If 33 is not free choose a free major number and change the
   #define SAMPLE_MAJOR in zaptel.c and recompile.

Note it is important to "insmod zaptel.o" from inside the zaptel
directory and don't forget the ".o" (.ko for Linux 2.6).  Otherwise
insmod will use the previously installed version of zaptel and
"sample" won't work.

5/ Make the call to the Zaptel port you wish to sample.  Run
   sample while talking:

     # ./sample test 1 5

this will create test_tx.raw, test_rx.raw & test_ec.raw. There
will be a few messages on the console as the driver does it's
thing, you can check these with dmesg.

6/ You can check your samples by playing them back through your
   sound card, for example:

     # play -f s -r 8000 -s w test_ec.raw

7/ To convert the raw files to wave files (this is more convenient for playing
   and processing with the Oslec simulation):

     # sox -t raw -r 8000 -s -w -c 1 test_ec.raw test_ec.wav
     # play test_ec.wav

8/ There is an Octave script pl.m to help plot the samples:
    
     # cp /your/test/samples ~/oslec/user
     # cd ~/oslec/user
     # octave
     octave:1> pl("test")

Configuration
~~~~~~~~~~~~~

+ Zaptel/Asterisk 1.2.13, 1.4.0 or 1.4.1.  However other versions should work
  OK.
+ Linux 2.4 or 2.6 Kernel
+ Digium TDM400 hardware
+ My zapata.conf for the FXO port under test is something like:

---------------------------------------------------------------------
    signalling=fxs_ks
    echocancel=yes
    ;echocancelwhenbridged=yes
    ;echotraining=400
    group=2;
    conext=incoming
    channel =>4
---------------------------------------------------------------------
 
Note echo training is switched off, although this didn't make much
difference to the FXO Port when using the built-in Zaptel echo
cancellers. (helped the the FXS port though).  Oslec does not support
echo training.

[[support]]
Support
-------

https://lists.sourceforge.net/lists/listinfo/freetel-oslec[Oslec
mailing list].

[[further]]
Further Work
------------

Here are some ideas for further work.

1/ Make info screen on control panel update each second automatically.

2/ When e/c is reset during a call it converges faster than at start of
   calls.  This suggests e/c is wandering off into dumb states before
   the call is connected.  Perhaps disabling adaption until the call
   is connected would help with faster convergence

3/ Preserving the state of the e/c between calls is also a very good
   idea, current zaptel design destroys the e/c at the end of a call.

4/ Switch on and test SSE and MMX filter code for x86.  Code LMS
   update for x86 in SSE or MMX.
   
5/ Add a feature to /proc/oslec to extract the current estimated
   impulse response.  Use gnuplot or Octave to plot it in real time.

6/ Attempt to speed convergence.

7/ Set up test scripts for greater coverage of G168 tests.

8/ If necessary develop a sparse approach to handle 128ms tails.

[[Simulation]]
HowTo - OSLEC G168 Simulation
-----------------------------

The simulation form of Oslec is useful for Oslec development.  It is
much easier to develop using a non-real time, user mode program than
saying 'Hello,...1,...2,....3" down a telephone line.  The simulation
dumps internal states while it is running, which can be plotted and
analysed using Octave.

1. Read spandsp-0.0.3/README and make sure you have installed the
dependencies like libtiff-devel, libaudiofile-devel, fftw-devel.

2. Make, build, run a test:

  $ cd spandsp-0.0.3; 
  $ ./configure --enable-tests
  $ make
  $ cd tests
  $ ./echo_tests 2a

3. You can change the echo path model with -m [1..7] (default 1)

4. You can change the ERL with -erl [0..whatever] (default 10.0)

5. You can plot the internal states using Octave:

  $ cd spandsp-0.0.3/echo_tests
  $ octave
  octave:1> echo_dump

  The st= and en= statements at the top of echo_dump.m control which
  part of the waveform is plotted.

6. There are some sequences of tests set up in the script files:

  $ ./g168_quick.sh (useful for a quick sanity test)
  $ ./g168_tests.sh (more comprehensive set of tests)

7. For more options:

  $ ./echo_tests -h

8. Counting passes (say if u want to see how many tests pass after making
   a change):

  $ ./g168_tests.sh > lms16bit.txt
  $ cat lms16bit.txt | grep PASS | wc -l

[[links]]
Further Reading
---------------

+ http://svn.astfin.org/software/oslec/trunk/spandsp-0.0.3/src/echo.c[echo.c]
is the heart of the Oslec echo canceller.

There are several blog posts documenting the development of Oslec:

+ http://www.rowetel.com/blog/?p=18[Part 1 - Introduction] discusses the myth
of hardware echo cancellation and the concept of an echo canceller
developed using echo samples collected by a community.

+ http://www.rowetel.com/blog/?p=21[Part 2 - How Echo Cancellers Work]
is an easy to read introduction to echo cancellation for C programmers.

+ http://www.rowetel.com/blog/?p=22[Part 3 - Two Prototypes] discusses
two algorithms that were developed as candidates for Oslec.  This is a
fairly "hard core" DSP post - some familiarity with echo cancellers is
assumed.

+ http://www.rowetel.com/blog/?p=23[Part 4 - First Phone calls] talks
about the very first real-world phone calls made using Oslec.

+ http://www.rowetel.com/blog/?p=33[Part 5 - Ready for Beta Testing].
Walks through some of the alpha testing bugs and how they were fixed,
discusses open development methods and the need for 128ms tails.

Some useful links:

+ Ochiai, Areseki, and Ogihara, "Echo Canceller with Two Echo Path
Models", IEEE Transactions on communications, COM-25, No. 6, June 1977. 
http://www.rowetel.com/images/echo/dual_path_paper.pdf[download].

+ The classic, very useful paper that tells you how to actually build
a real world echo canceller: Messerschmitt, Hedberg, Cole, Haoui,
Winship, "Digital Voice Echo Canceller with a
TMS320020. http://www.rowetel.com/images/echo/spra129.pdf[download].

+ A nice
http://en.wikipedia.org/wiki/Least_mean_squares_filter[introduction to
LMS filters].

+ Good introduction to http://www.cisco.com/univercd/cc/td/doc/cisintwk/intsolns/voipsol/ea_isd.htm[echo on VOIP calls] from Cisco.

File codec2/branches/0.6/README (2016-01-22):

Codec 2 README
--------------

Codec 2 is an open source (LGPL licensed) speech codec for 3200 bit/s
and below.  For more information please see:

    http://rowetel.com/codec2.html

Also included is a FDMDV modem (README_fdmdv.txt), a coherent PSK
modem and an API for embedding FreeDV in other programs (see example
below).  For more information on building Codec 2 see README.cmake

SVN Repository
--------------

Check out the latest (development branch) code using:

  $ svn co https://svn.code.sf.net/p/freetel/code/codec2-dev codec2-dev

There are 3rd party GIT mirrors of Codec2 and FreeDV. Use Git at your
own risk.

  GIT IS NOT SUPPORTED!!!

All patches, support questions etc, need to be against the SVN
repository above.

Please do not email me (David), or the codec2-dev mailing list
suggesting we change to Git.  I get these emails every week.  Really,
I understand the arguments, but am content with SVN for now.

Quickstart
----------

Refer to INSTALL for more general building and installing instructions.

NOTE: You may not have the necessary speex libraries installed. Some
      distributions may have packages available 
      i.e. sudo apt-get install speex-*
      alternatively, visit http://www.speex.org and follow the instructions

1/ Listen to Codec 2:

   $ cd codec2-dev
   $ mkdir build_linux
   $ cd build_linux
   $ cmake ..
   $ make
   $ ./src/c2demo ../raw/hts1a.raw hts1a_c2.raw
   $ play -t raw -r 8000 -e signed-integer -b 16 ../raw/hts1a.raw
   $ play -t raw -r 8000 -e signed-integer -b 16 ./hts1a_c2.raw

2/ Compress, Decompress and then play a file:

   using 2400 bps bit rate encoding

   $ ./src/c2enc 2400 ../raw/hts1a.raw hts1a_c2.bit
   $ ./src/c2dec 2400 hts1a_c2.bit hts1a_c2_2400.raw 

   which can be played with

   $ play -t raw -r 8000 -e signed-integer -b 16 ./hts1a_c2_2400.raw

   using 700 bps bit rate encoding

   $ ./src/c2enc 700 ../raw/hts1a.raw hts1a_c2.bit
   $ ./src/c2dec 700 hts1a_c2.bit hts1a_c2_700.raw

   which can be played with

   $ play -t raw -r 8000 -e signed-integer -b 16 ./hts1a_c2_700.raw

3/ Same thing with pipes:

   $ ./src/c2enc 1300 ../raw/hts1a.raw - | ./src/c2dec 1300 - - | play -t raw -r 8000 -s -2 -

Embedded FreeDV API
-------------------

See freedv_api.h and freedv_api.c, and the demo programs freedv_tx &
freedv_rx.  Quickstart:

  $ ./freedv_tx 1600 ../../raw/hts1.raw - | ./freedv_rx 1600 - - | play -t raw -r 8000 -s -2 -q -
  $ cat freedv_rx_log.txt

Programs
--------
 
1/ c2demo encodes a file of speech samples, then decodes them and
saves the result.

2/ c2enc encodes a file of speech samples to a compressed file of
encoded bits.

3/ c2dec decodes a compressed file of bits to a file of speech
samples.

4/ c2sim is a simulation/development version of Codec 2.  It allows
selective use of the various Codec 2 algorithms.  For example
switching phase modelling or LSP quantisation on and off.

Debugging
---------

1/ To compile with debug symbols for using gdb:

  $ cd ~/codec2
  $ rm -Rf build_linux && mkdir build_linux
  $ cd build_linux
  $ CFLAGS=-g cmake ..
  $ make

2/ For dump file support:

  $ cd ~/codec2
  $ rm -Rf build_linux && mkdir build_linux
  $ cd build_linux
  $ CFLAGS=-DDUMP cmake ..
  $ make

Building Unit Tests
-------------------

The unittests are no longer built by default.  To build them:

  $ cd ~/codec2
  $ rm -Rf build_linux && mkdir build_linux
  $ cd build_linux
  $ cmake -DCMAKE_BUILD_TYPE=Debug ..
  $ make

Directories
-----------

  asterisk &  - unmaintained Asterisk support
  asterisk-11 
  cmake       - cmake support files
  octave      - Octave scripts used to support development
  script      - shell scripts for playing and converting raw files
  src         - C source code for Codec 2, FDMDV modem, COHPSK modem, FreeDV API
  raw         - speech files in raw format (16 bits signed linear 8 kHz)
  stm32       - Support for the STM32F4 microcontroller and SM1000 FreeDV Adaptor
  unittest    - unit test source code
  wav         - speech files in wave file format

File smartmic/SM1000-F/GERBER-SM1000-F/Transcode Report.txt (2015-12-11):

   ---- Transcoding 'C:\Users\rbarnich\smartmic\SM1000-F\GERBER-SM1000-F\SM1000-F.ast' ----   Fri Dec 11 11:02:59 2015

D10   --> D100
D11   --> D101
D12   --> D102
D13   --> D103
D15   --> D104
D16   --> D105
D17   --> D106
-----------------------------------------------------------------

   ---- Transcoding 'C:\Users\rbarnich\smartmic\SM1000-F\GERBER-SM1000-F\SM1000-F.bps' ----   Fri Dec 11 11:02:59 2015

D10   --> D107
D11   --> D108
D12   --> D109
D13   --> D110
D14   --> D111
D15   --> D112
D16   --> D113
-----------------------------------------------------------------

   ---- Transcoding 'C:\Users\rbarnich\smartmic\SM1000-F\GERBER-SM1000-F\SM1000-F.drt' ----   Fri Dec 11 11:02:59 2015

D10   --> D114
D11   --> D115
D12   --> D116
D13   --> D117
D14   --> D118
-----------------------------------------------------------------

   ---- Transcoding 'C:\Users\rbarnich\smartmic\SM1000-F\GERBER-SM1000-F\SM1000-F.L1' ----   Fri Dec 11 11:02:59 2015

D10   --> D119
D11   --> D120
D12   --> D121
D13   --> D122
D14   --> D123
D15   --> D124
D16   --> D125
D17   --> D126
D18   --> D127
D19   --> D128
D20   --> D129
D21   --> D130
D22   --> D131
D23   --> D132
D24   --> D133
D25   --> D134
D26   --> D135
D27   --> D136
D28   --> D137
-----------------------------------------------------------------

   ---- Transcoding 'C:\Users\rbarnich\smartmic\SM1000-F\GERBER-SM1000-F\SM1000-F.L2' ----   Fri Dec 11 11:02:59 2015

D10   --> D138
D11   --> D139
D12   --> D140
D13   --> D141
D14   --> D142
D15   --> D143
D16   --> D144
D17   --> D145
D18   --> D146
D19   --> D147
D20   --> D148
D21   --> D149
D22   --> D150
D23   --> D151
-----------------------------------------------------------------

   ---- Transcoding 'C:\Users\rbarnich\smartmic\SM1000-F\GERBER-SM1000-F\SM1000-F.L3' ----   Fri Dec 11 11:02:59 2015

D10   --> D152
D11   --> D153
D12   --> D154
D13   --> D155
D14   --> D156
D15   --> D157
D16   --> D158
D17   --> D159
D18   --> D160
D19   --> D161
D20   --> D162
D21   --> D163
D22   --> D164
D23   --> D165
D24   --> D166
D25   --> D167
D26   --> D168
D27   --> D169
-----------------------------------------------------------------

   ---- Transcoding 'C:\Users\rbarnich\smartmic\SM1000-F\GERBER-SM1000-F\SM1000-F.L4' ----   Fri Dec 11 11:02:59 2015

D10   --> D170
D11   --> D171
D12   --> D172
D13   --> D173
D14   --> D174
D15   --> D175
D16   --> D176
D17   --> D177
D18   --> D178
D19   --> D179
D20   --> D180
D21   --> D181
D22   --> D182
D23   --> D183
D24   --> D184
D25   --> D185
D26   --> D186
D27   --> D187
D29   --> D188
D30   --> D189
D31   --> D190
D32   --> D191
D33   --> D192
D34   --> D193
D35   --> D194
D36   --> D195
D37   --> D196
D38   --> D197
D39   --> D198
D40   --> D199
D41   --> D200
-----------------------------------------------------------------

   ---- Transcoding 'C:\Users\rbarnich\smartmic\SM1000-F\GERBER-SM1000-F\SM1000-F.oln' ----   Fri Dec 11 11:02:59 2015

D10   --> D201
D11   --> D202
-----------------------------------------------------------------

   ---- Transcoding 'C:\Users\rbarnich\smartmic\SM1000-F\GERBER-SM1000-F\SM1000-F.slk' ----   Fri Dec 11 11:02:59 2015

D10   --> D203
D11   --> D204
D12   --> D205
D13   --> D206
D15   --> D207
D16   --> D208
D17   --> D209
-----------------------------------------------------------------

   ---- Transcoding 'C:\Users\rbarnich\smartmic\SM1000-F\GERBER-SM1000-F\SM1000-F.smb' ----   Fri Dec 11 11:02:59 2015

D10   --> D210
D11   --> D211
D12   --> D212
D13   --> D213
D14   --> D214
D15   --> D215
D16   --> D216
D17   --> D217
D18   --> D218
D19   --> D219
D20   --> D220
D21   --> D221
D22   --> D222
D23   --> D223
D24   --> D224
D25   --> D225
D26   --> D226
D27   --> D227
D28   --> D228
D29   --> D229
D30   --> D230
D31   --> D231
D32   --> D232
D33   --> D233
-----------------------------------------------------------------

   ---- Transcoding 'C:\Users\rbarnich\smartmic\SM1000-F\GERBER-SM1000-F\SM1000-F.smt' ----   Fri Dec 11 11:02:59 2015

D10   --> D234
D11   --> D235
D12   --> D236
D13   --> D237
D14   --> D238
D15   --> D239
D16   --> D240
D17   --> D241
D18   --> D242
D19   --> D243
D20   --> D244
D21   --> D245
D22   --> D246
D23   --> D247
D24   --> D248
D25   --> D249
D26   --> D250
D27   --> D251
D28   --> D252
D29   --> D253
D30   --> D254
D31   --> D255
D32   --> D256
D33   --> D257
D34   --> D258
D35   --> D259
D36   --> D260
D37   --> D261
D38   --> D262
D39   --> D263
D40   --> D264
D41   --> D265
D42   --> D266
D43   --> D267
D44   --> D268
D45   --> D269
D46   --> D270
D47   --> D271
D48   --> D272
D49   --> D273
-----------------------------------------------------------------

   ---- Transcoding 'C:\Users\rbarnich\smartmic\SM1000-F\GERBER-SM1000-F\SM1000-F.tps' ----   Fri Dec 11 11:02:59 2015

D10   --> D274
D11   --> D275
D12   --> D276
D13   --> D277
D14   --> D278
D15   --> D279
D16   --> D280
D17   --> D281
D18   --> D282
D19   --> D283
D20   --> D284
D21   --> D285
D22   --> D286
D23   --> D287
D24   --> D288
D25   --> D289
D26   --> D290
D27   --> D291
D28   --> D292
D29   --> D293
D30   --> D294
D31   --> D295
-----------------------------------------------------------------

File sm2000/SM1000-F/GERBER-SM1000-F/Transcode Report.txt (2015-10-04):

   ---- Transcoding 'C:\Users\rbarnich\smartmic\SM1000-F\GERBER\SM1000-F.ast' ----   Sun Oct 04 14:20:22 2015

D10   --> D100
D11   --> D101
D12   --> D102
D13   --> D103
D15   --> D104
D16   --> D105
D17   --> D106
-----------------------------------------------------------------

   ---- Transcoding 'C:\Users\rbarnich\smartmic\SM1000-F\GERBER\SM1000-F.bps' ----   Sun Oct 04 14:20:22 2015

D10   --> D107
D11   --> D108
D12   --> D109
D13   --> D110
D14   --> D111
D15   --> D112
D16   --> D113
-----------------------------------------------------------------

   ---- Transcoding 'C:\Users\rbarnich\smartmic\SM1000-F\GERBER\SM1000-F.drt' ----   Sun Oct 04 14:20:25 2015

D10   --> D114
D11   --> D115
D12   --> D116
D14   --> D117
-----------------------------------------------------------------

   ---- Transcoding 'C:\Users\rbarnich\smartmic\SM1000-F\GERBER\SM1000-F.L1' ----   Sun Oct 04 14:20:25 2015

D10   --> D118
D11   --> D119
D12   --> D120
D13   --> D121
D14   --> D122
D15   --> D123
D16   --> D124
D17   --> D125
D18   --> D126
D19   --> D127
D20   --> D128
D21   --> D129
D22   --> D130
D23   --> D131
D24   --> D132
D25   --> D133
D26   --> D134
D27   --> D135
D28   --> D136
-----------------------------------------------------------------

   ---- Transcoding 'C:\Users\rbarnich\smartmic\SM1000-F\GERBER\SM1000-F.L2' ----   Sun Oct 04 14:20:25 2015

D10   --> D137
D11   --> D138
D12   --> D139
D13   --> D140
D14   --> D141
D15   --> D142
D16   --> D143
D17   --> D144
D18   --> D145
D19   --> D146
D20   --> D147
D21   --> D148
D22   --> D149
D23   --> D150
-----------------------------------------------------------------

   ---- Transcoding 'C:\Users\rbarnich\smartmic\SM1000-F\GERBER\SM1000-F.L3' ----   Sun Oct 04 14:20:25 2015

D10   --> D151
D11   --> D152
D12   --> D153
D13   --> D154
D14   --> D155
D15   --> D156
D16   --> D157
D17   --> D158
D18   --> D159
D19   --> D160
D20   --> D161
D21   --> D162
D22   --> D163
D23   --> D164
D24   --> D165
D25   --> D166
D26   --> D167
D27   --> D168
-----------------------------------------------------------------

   ---- Transcoding 'C:\Users\rbarnich\smartmic\SM1000-F\GERBER\SM1000-F.L4' ----   Sun Oct 04 14:20:25 2015

D10   --> D169
D11   --> D170
D12   --> D171
D13   --> D172
D14   --> D173
D15   --> D174
D16   --> D175
D17   --> D176
D18   --> D177
D19   --> D178
D20   --> D179
D21   --> D180
D22   --> D181
D23   --> D182
D24   --> D183
D25   --> D184
D26   --> D185
D27   --> D186
D29   --> D187
D30   --> D188
D31   --> D189
D32   --> D190
D33   --> D191
D34   --> D192
D35   --> D193
D36   --> D194
D37   --> D195
D38   --> D196
D39   --> D197
D40   --> D198
D41   --> D199
-----------------------------------------------------------------

   ---- Transcoding 'C:\Users\rbarnich\smartmic\SM1000-F\GERBER\SM1000-F.oln' ----   Sun Oct 04 14:20:25 2015

D10   --> D200
D11   --> D201
-----------------------------------------------------------------

   ---- Transcoding 'C:\Users\rbarnich\smartmic\SM1000-F\GERBER\SM1000-F.slk' ----   Sun Oct 04 14:20:25 2015

D10   --> D202
D11   --> D203
D12   --> D204
D13   --> D205
D15   --> D206
D16   --> D207
D17   --> D208
-----------------------------------------------------------------

   ---- Transcoding 'C:\Users\rbarnich\smartmic\SM1000-F\GERBER\SM1000-F.smb' ----   Sun Oct 04 14:20:25 2015

D10   --> D209
D11   --> D210
D12   --> D211
D13   --> D212
D14   --> D213
D15   --> D214
D16   --> D215
D17   --> D216
D18   --> D217
D19   --> D218
D20   --> D219
D21   --> D220
D22   --> D221
D23   --> D222
D24   --> D223
D25   --> D224
D26   --> D225
D27   --> D226
D28   --> D227
D29   --> D228
D30   --> D229
D31   --> D230
D32   --> D231
D33   --> D232
-----------------------------------------------------------------

   ---- Transcoding 'C:\Users\rbarnich\smartmic\SM1000-F\GERBER\SM1000-F.smt' ----   Sun Oct 04 14:20:25 2015

D10   --> D233
D11   --> D234
D12   --> D235
D13   --> D236
D14   --> D237
D15   --> D238
D16   --> D239
D17   --> D240
D18   --> D241
D19   --> D242
D20   --> D243
D21   --> D244
D22   --> D245
D23   --> D246
D24   --> D247
D25   --> D248
D26   --> D249
D27   --> D250
D28   --> D251
D29   --> D252
D30   --> D253
D31   --> D254
D32   --> D255
D33   --> D256
D34   --> D257
D35   --> D258
D36   --> D259
D37   --> D260
D38   --> D261
D39   --> D262
D40   --> D263
D41   --> D264
D42   --> D265
D43   --> D266
D44   --> D267
D45   --> D268
D46   --> D269
D47   --> D270
D48   --> D271
D49   --> D272
-----------------------------------------------------------------

   ---- Transcoding 'C:\Users\rbarnich\smartmic\SM1000-F\GERBER\SM1000-F.tps' ----   Sun Oct 04 14:20:25 2015

D10   --> D273
D11   --> D274
D12   --> D275
D13   --> D276
D14   --> D277
D15   --> D278
D16   --> D279
D17   --> D280
D18   --> D281
D19   --> D282
D20   --> D283
D21   --> D284
D22   --> D285
D23   --> D286
D24   --> D287
D25   --> D288
D26   --> D289
D27   --> D290
D28   --> D291
D29   --> D292
D30   --> D293
D31   --> D294
-----------------------------------------------------------------

   ---- Transcoding 'C:\Users\rbarnich\smartmic\SM1000-F\GERBER\SM1000-F.ast' ----   Sun Oct 04 14:22:42 2015

D10   --> D100
D11   --> D101
D12   --> D102
D13   --> D103
D15   --> D104
D16   --> D105
D17   --> D106
-----------------------------------------------------------------

   ---- Transcoding 'C:\Users\rbarnich\smartmic\SM1000-F\GERBER\SM1000-F.bps' ----   Sun Oct 04 14:22:42 2015

D10   --> D107
D11   --> D108
D12   --> D109
D13   --> D110
D14   --> D111
D15   --> D112
D16   --> D113
-----------------------------------------------------------------

   ---- Transcoding 'C:\Users\rbarnich\smartmic\SM1000-F\GERBER\SM1000-F.drt' ----   Sun Oct 04 14:22:45 2015

D10   --> D114
D11   --> D115
D12   --> D116
D14   --> D117
-----------------------------------------------------------------

   ---- Transcoding 'C:\Users\rbarnich\smartmic\SM1000-F\GERBER\SM1000-F.L1' ----   Sun Oct 04 14:22:45 2015

D10   --> D118
D11   --> D119
D12   --> D120
D13   --> D121
D14   --> D122
D15   --> D123
D16   --> D124
D17   --> D125
D18   --> D126
D19   --> D127
D20   --> D128
D21   --> D129
D22   --> D130
D23   --> D131
D24   --> D132
D25   --> D133
D26   --> D134
D27   --> D135
D28   --> D136
-----------------------------------------------------------------

   ---- Transcoding 'C:\Users\rbarnich\smartmic\SM1000-F\GERBER\SM1000-F.L2' ----   Sun Oct 04 14:22:45 2015

D10   --> D137
D11   --> D138
D12   --> D139
D13   --> D140
D14   --> D141
D15   --> D142
D16   --> D143
D17   --> D144
D18   --> D145
D19   --> D146
D20   --> D147
D21   --> D148
D22   --> D149
D23   --> D150
-----------------------------------------------------------------

   ---- Transcoding 'C:\Users\rbarnich\smartmic\SM1000-F\GERBER\SM1000-F.L3' ----   Sun Oct 04 14:22:45 2015

D10   --> D151
D11   --> D152
D12   --> D153
D13   --> D154
D14   --> D155
D15   --> D156
D16   --> D157
D17   --> D158
D18   --> D159
D19   --> D160
D20   --> D161
D21   --> D162
D22   --> D163
D23   --> D164
D24   --> D165
D25   --> D166
D26   --> D167
D27   --> D168
-----------------------------------------------------------------

   ---- Transcoding 'C:\Users\rbarnich\smartmic\SM1000-F\GERBER\SM1000-F.L4' ----   Sun Oct 04 14:22:45 2015

D10   --> D169
D11   --> D170
D12   --> D171
D13   --> D172
D14   --> D173
D15   --> D174
D16   --> D175
D17   --> D176
D18   --> D177
D19   --> D178
D20   --> D179
D21   --> D180
D22   --> D181
D23   --> D182
D24   --> D183
D25   --> D184
D26   --> D185
D27   --> D186
D29   --> D187
D30   --> D188
D31   --> D189
D32   --> D190
D33   --> D191
D34   --> D192
D35   --> D193
D36   --> D194
D37   --> D195
D38   --> D196
D39   --> D197
D40   --> D198
D41   --> D199
-----------------------------------------------------------------

   ---- Transcoding 'C:\Users\rbarnich\smartmic\SM1000-F\GERBER\SM1000-F.oln' ----   Sun Oct 04 14:22:45 2015

D10   --> D200
D11   --> D201
-----------------------------------------------------------------

   ---- Transcoding 'C:\Users\rbarnich\smartmic\SM1000-F\GERBER\SM1000-F.slk' ----   Sun Oct 04 14:22:45 2015

D10   --> D202
D11   --> D203
D12   --> D204
D13   --> D205
D15   --> D206
D16   --> D207
D17   --> D208
-----------------------------------------------------------------

   ---- Transcoding 'C:\Users\rbarnich\smartmic\SM1000-F\GERBER\SM1000-F.smb' ----   Sun Oct 04 14:22:45 2015

D10   --> D209
D11   --> D210
D12   --> D211
D13   --> D212
D14   --> D213
D15   --> D214
D16   --> D215
D17   --> D216
D18   --> D217
D19   --> D218
D20   --> D219
D21   --> D220
D22   --> D221
D23   --> D222
D24   --> D223
D25   --> D224
D26   --> D225
D27   --> D226
D28   --> D227
D29   --> D228
D30   --> D229
D31   --> D230
D32   --> D231
D33   --> D232
-----------------------------------------------------------------

   ---- Transcoding 'C:\Users\rbarnich\smartmic\SM1000-F\GERBER\SM1000-F.smt' ----   Sun Oct 04 14:22:45 2015

D10   --> D233
D11   --> D234
D12   --> D235
D13   --> D236
D14   --> D237
D15   --> D238
D16   --> D239
D17   --> D240
D18   --> D241
D19   --> D242
D20   --> D243
D21   --> D244
D22   --> D245
D23   --> D246
D24   --> D247
D25   --> D248
D26   --> D249
D27   --> D250
D28   --> D251
D29   --> D252
D30   --> D253
D31   --> D254
D32   --> D255
D33   --> D256
D34   --> D257
D35   --> D258
D36   --> D259
D37   --> D260
D38   --> D261
D39   --> D262
D40   --> D263
D41   --> D264
D42   --> D265
D43   --> D266
D44   --> D267
D45   --> D268
D46   --> D269
D47   --> D270
D48   --> D271
D49   --> D272
-----------------------------------------------------------------

   ---- Transcoding 'C:\Users\rbarnich\smartmic\SM1000-F\GERBER\SM1000-F.tps' ----   Sun Oct 04 14:22:45 2015

D10   --> D273
D11   --> D274
D12   --> D275
D13   --> D276
D14   --> D277
D15   --> D278
D16   --> D279
D17   --> D280
D18   --> D281
D19   --> D282
D20   --> D283
D21   --> D284
D22   --> D285
D23   --> D286
D24   --> D287
D25   --> D288
D26   --> D289
D27   --> D290
D28   --> D291
D29   --> D292
D30   --> D293
D31   --> D294
-----------------------------------------------------------------

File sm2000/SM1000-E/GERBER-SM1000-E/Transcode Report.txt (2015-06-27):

   ---- Transcoding 'C:\Users\rbarnich\smartmic\SM1000-E\GERBER-SM1000-E\SM1000-E.ast' ----   Sat Jun 27 14:32:16 2015

D10   --> D100
D11   --> D101
D12   --> D102
D13   --> D103
D14   --> D104
D15   --> D105
D16   --> D106
-----------------------------------------------------------------

   ---- Transcoding 'C:\Users\rbarnich\smartmic\SM1000-E\GERBER-SM1000-E\SM1000-E.bps' ----   Sat Jun 27 14:32:16 2015

D10   --> D107
D11   --> D108
D12   --> D109
D13   --> D110
D14   --> D111
-----------------------------------------------------------------

   ---- Transcoding 'C:\Users\rbarnich\smartmic\SM1000-E\GERBER-SM1000-E\SM1000-E.drt' ----   Sat Jun 27 14:32:20 2015

D10   --> D112
D11   --> D113
D12   --> D114
D13   --> D115
-----------------------------------------------------------------

   ---- Transcoding 'C:\Users\rbarnich\smartmic\SM1000-E\GERBER-SM1000-E\SM1000-E.L1' ----   Sat Jun 27 14:32:20 2015

D10   --> D116
D11   --> D117
D12   --> D118
D13   --> D119
D14   --> D120
D15   --> D121
D16   --> D122
D18   --> D123
D19   --> D124
D20   --> D125
D21   --> D126
D22   --> D127
D23   --> D128
D24   --> D129
D25   --> D130
D26   --> D131
D27   --> D132
D28   --> D133
D29   --> D134
-----------------------------------------------------------------

   ---- Transcoding 'C:\Users\rbarnich\smartmic\SM1000-E\GERBER-SM1000-E\SM1000-E.L2' ----   Sat Jun 27 14:32:20 2015

D10   --> D135
D11   --> D136
D12   --> D137
D13   --> D138
D14   --> D139
D15   --> D140
D16   --> D141
D17   --> D142
D18   --> D143
D19   --> D144
D20   --> D145
D21   --> D146
D22   --> D147
D23   --> D148
D24   --> D149
-----------------------------------------------------------------

   ---- Transcoding 'C:\Users\rbarnich\smartmic\SM1000-E\GERBER-SM1000-E\SM1000-E.L3' ----   Sat Jun 27 14:32:20 2015

D10   --> D150
D11   --> D151
D12   --> D152
D13   --> D153
D14   --> D154
D15   --> D155
D16   --> D156
D17   --> D157
D18   --> D158
D19   --> D159
D20   --> D160
D21   --> D161
D22   --> D162
D23   --> D163
D24   --> D164
D25   --> D165
D26   --> D166
D27   --> D167
-----------------------------------------------------------------

   ---- Transcoding 'C:\Users\rbarnich\smartmic\SM1000-E\GERBER-SM1000-E\SM1000-E.L4' ----   Sat Jun 27 14:32:20 2015

D10   --> D168
D11   --> D169
D12   --> D170
D13   --> D171
D14   --> D172
D15   --> D173
D16   --> D174
D17   --> D175
D18   --> D176
D19   --> D177
D20   --> D178
D21   --> D179
D22   --> D180
D23   --> D181
D24   --> D182
D25   --> D183
D26   --> D184
D27   --> D185
D28   --> D186
D30   --> D187
D31   --> D188
D32   --> D189
D33   --> D190
D34   --> D191
D36   --> D192
D37   --> D193
D38   --> D194
D39   --> D195
D40   --> D196
D41   --> D197
D42   --> D198
D43   --> D199
-----------------------------------------------------------------

   ---- Transcoding 'C:\Users\rbarnich\smartmic\SM1000-E\GERBER-SM1000-E\SM1000-E.oln' ----   Sat Jun 27 14:32:20 2015

D10   --> D200
-----------------------------------------------------------------

   ---- Transcoding 'C:\Users\rbarnich\smartmic\SM1000-E\GERBER-SM1000-E\SM1000-E.slk' ----   Sat Jun 27 14:32:20 2015

D10   --> D201
D11   --> D202
D12   --> D203
D13   --> D204
D14   --> D205
D15   --> D206
D16   --> D207
-----------------------------------------------------------------

   ---- Transcoding 'C:\Users\rbarnich\smartmic\SM1000-E\GERBER-SM1000-E\SM1000-E.smb' ----   Sat Jun 27 14:32:20 2015

D10   --> D208
D11   --> D209
D12   --> D210
D13   --> D211
D14   --> D212
D15   --> D213
D16   --> D214
D17   --> D215
D18   --> D216
D19   --> D217
D20   --> D218
D21   --> D219
D22   --> D220
D23   --> D221
D24   --> D222
D25   --> D223
D26   --> D224
D27   --> D225
D28   --> D226
D29   --> D227
D30   --> D228
D31   --> D229
D32   --> D230
D33   --> D231
-----------------------------------------------------------------

   ---- Transcoding 'C:\Users\rbarnich\smartmic\SM1000-E\GERBER-SM1000-E\SM1000-E.smt' ----   Sat Jun 27 14:32:20 2015

D10   --> D232
D11   --> D233
D12   --> D234
D13   --> D235
D14   --> D236
D15   --> D237
D16   --> D238
D17   --> D239
D18   --> D240
D19   --> D241
D20   --> D242
D21   --> D243
D22   --> D244
D23   --> D245
D24   --> D246
D25   --> D247
D26   --> D248
D27   --> D249
D28   --> D250
D29   --> D251
D30   --> D252
D31   --> D253
D32   --> D254
D33   --> D255
D34   --> D256
D35   --> D257
D36   --> D258
D37   --> D259
D38   --> D260
D39   --> D261
D40   --> D262
D41   --> D263
D42   --> D264
D43   --> D265
D44   --> D266
D45   --> D267
D46   --> D268
D47   --> D269
D48   --> D270
D49   --> D271
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
-----------------------------------------------------------------

   ---- Transcoding 'C:\Users\rbarnich\smartmic\SM1000-E\GERBER-SM1000-E\SM1000-E.tps' ----   Sat Jun 27 14:32:20 2015

D10   --> D273
D11   --> D274
D12   --> D275
D13   --> D276
D14   --> D277
D15   --> D278
D17   --> D279
D18   --> D280
D19   --> D281
D20   --> D282
D21   --> D283
D22   --> D284
D23   --> D285
D24   --> D286
D25   --> D287
D26   --> D288
D27   --> D289
D28   --> D290
D29   --> D291
D30   --> D292
-----------------------------------------------------------------

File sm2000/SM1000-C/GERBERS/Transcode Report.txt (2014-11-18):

   ---- Transcoding 'C:\Users\rbarnich\smartmic\SM1000-C\GERBERS\SM1000-C.ast' ----   Tue Nov 18 13:33:32 2014

D11   --> D100
D12   --> D101
D13   --> D102
D14   --> D103
D16   --> D104
-----------------------------------------------------------------

   ---- Transcoding 'C:\Users\rbarnich\smartmic\SM1000-C\GERBERS\SM1000-C.bps' ----   Tue Nov 18 13:33:32 2014

D10   --> D105
D11   --> D106
D12   --> D107
-----------------------------------------------------------------

   ---- Transcoding 'C:\Users\rbarnich\smartmic\SM1000-C\GERBERS\SM1000-C.bsk' ----   Tue Nov 18 13:33:32 2014

D10   --> D108
D11   --> D109
D12   --> D110
D13   --> D111
D14   --> D112
D15   --> D113
-----------------------------------------------------------------

   ---- Transcoding 'C:\Users\rbarnich\smartmic\SM1000-C\GERBERS\SM1000-C.drt' ----   Tue Nov 18 13:33:37 2014

D12   --> D114
D13   --> D115
-----------------------------------------------------------------

   ---- Transcoding 'C:\Users\rbarnich\smartmic\SM1000-C\GERBERS\SM1000-C.L1' ----   Tue Nov 18 13:33:37 2014

D10   --> D116
D11   --> D117
D12   --> D118
D13   --> D119
D14   --> D120
D15   --> D121
D16   --> D122
D17   --> D123
D18   --> D124
D20   --> D125
D21   --> D126
D22   --> D127
D23   --> D128
D24   --> D129
D25   --> D130
D26   --> D131
D27   --> D132
D28   --> D133
D29   --> D134
D30   --> D135
D31   --> D136
D32   --> D137
D33   --> D138
D34   --> D139
D35   --> D140
D36   --> D141
D37   --> D142
D38   --> D143
D39   --> D144
D40   --> D145
D41   --> D146
D42   --> D147
D43   --> D148
D44   --> D149
D45   --> D150
-----------------------------------------------------------------

   ---- Transcoding 'C:\Users\rbarnich\smartmic\SM1000-C\GERBERS\SM1000-C.L2' ----   Tue Nov 18 13:33:37 2014

D10   --> D151
D11   --> D152
D12   --> D153
D13   --> D154
D14   --> D155
D15   --> D156
D16   --> D157
D17   --> D158
D18   --> D159
D19   --> D160
D20   --> D161
D21   --> D162
-----------------------------------------------------------------

   ---- Transcoding 'C:\Users\rbarnich\smartmic\SM1000-C\GERBERS\SM1000-C.L3' ----   Tue Nov 18 13:33:37 2014

D10   --> D163
D11   --> D164
D12   --> D165
D13   --> D166
D14   --> D167
D15   --> D168
D16   --> D169
D17   --> D170
D18   --> D171
D19   --> D172
D20   --> D173
D21   --> D174
D22   --> D175
D23   --> D176
-----------------------------------------------------------------

   ---- Transcoding 'C:\Users\rbarnich\smartmic\SM1000-C\GERBERS\SM1000-C.L4' ----   Tue Nov 18 13:33:37 2014

D10   --> D177
D11   --> D178
D12   --> D179
D13   --> D180
D14   --> D181
D15   --> D182
D16   --> D183
D17   --> D184
D18   --> D185
D19   --> D186
D20   --> D187
D21   --> D188
D22   --> D189
D23   --> D190
D24   --> D191
D25   --> D192
D26   --> D193
D27   --> D194
D28   --> D195
D29   --> D196
D30   --> D197
D31   --> D198
D32   --> D199
D33   --> D200
D34   --> D201
-----------------------------------------------------------------

   ---- Transcoding 'C:\Users\rbarnich\smartmic\SM1000-C\GERBERS\SM1000-C.slk' ----   Tue Nov 18 13:33:37 2014

D10   --> D202
D11   --> D203
D12   --> D204
D13   --> D205
D14   --> D206
D15   --> D207
D16   --> D208
D17   --> D209
D18   --> D210
D19   --> D211
D20   --> D212
D21   --> D213
D22   --> D214
D23   --> D215
D24   --> D216
D25   --> D217
D26   --> D218
D27   --> D219
D28   --> D220
-----------------------------------------------------------------

   ---- Transcoding 'C:\Users\rbarnich\smartmic\SM1000-C\GERBERS\SM1000-C.smb' ----   Tue Nov 18 13:33:37 2014

D10   --> D221
D11   --> D222
D12   --> D223
D13   --> D224
D14   --> D225
D15   --> D226
D16   --> D227
D17   --> D228
D18   --> D229
D19   --> D230
D20   --> D231
D21   --> D232
D22   --> D233
D23   --> D234
D24   --> D235
D25   --> D236
D26   --> D237
D27   --> D238
D28   --> D239
-----------------------------------------------------------------

   ---- Transcoding 'C:\Users\rbarnich\smartmic\SM1000-C\GERBERS\SM1000-C.smt' ----   Tue Nov 18 13:33:37 2014

D10   --> D240
D11   --> D241
D12   --> D242
D13   --> D243
D14   --> D244
D15   --> D245
D16   --> D246
D17   --> D247
D18   --> D248
D19   --> D249
D20   --> D250
D21   --> D251
D22   --> D252
D23   --> D253
D24   --> D254
D25   --> D255
D26   --> D256
D27   --> D257
D28   --> D258
D29   --> D259
D30   --> D260
D31   --> D261
D32   --> D262
D33   --> D263
D34   --> D264
D35   --> D265
D36   --> D266
D37   --> D267
D38   --> D268
D39   --> D269
D40   --> D270
D41   --> D271
D42   --> D272
D43   --> D273
D44   --> D274
D45   --> D275
D46   --> D276
-----------------------------------------------------------------

   ---- Transcoding 'C:\Users\rbarnich\smartmic\SM1000-C\GERBERS\SM1000-C.tps' ----   Tue Nov 18 13:33:37 2014

D10   --> D277
D11   --> D278
D12   --> D279
D13   --> D280
D14   --> D281
D15   --> D282
D16   --> D283
D17   --> D284
D18   --> D285
D19   --> D286
D20   --> D287
D21   --> D288
D22   --> D289
D23   --> D290
D24   --> D291
D25   --> D292
D26   --> D293
D27   --> D294
D28   --> D295
D29   --> D296
D30   --> D297
-----------------------------------------------------------------

   ---- Transcoding 'C:\Users\rbarnich\smartmic\SM1000-C\GERBERS\SM1000-C.ast' ----   Tue Nov 18 13:40:52 2014

D11   --> D100
D12   --> D101
D13   --> D102
D14   --> D103
D16   --> D104
-----------------------------------------------------------------

   ---- Transcoding 'C:\Users\rbarnich\smartmic\SM1000-C\GERBERS\SM1000-C.bps' ----   Tue Nov 18 13:40:52 2014

D10   --> D105
D11   --> D106
D12   --> D107
-----------------------------------------------------------------

   ---- Transcoding 'C:\Users\rbarnich\smartmic\SM1000-C\GERBERS\SM1000-C.bsk' ----   Tue Nov 18 13:40:52 2014

D10   --> D108
D11   --> D109
D12   --> D110
D13   --> D111
D14   --> D112
D15   --> D113
-----------------------------------------------------------------

   ---- Transcoding 'C:\Users\rbarnich\smartmic\SM1000-C\GERBERS\SM1000-C.drt' ----   Tue Nov 18 13:40:55 2014

D12   --> D114
D13   --> D115
-----------------------------------------------------------------

   ---- Transcoding 'C:\Users\rbarnich\smartmic\SM1000-C\GERBERS\SM1000-C.L1' ----   Tue Nov 18 13:40:55 2014

D10   --> D116
D11   --> D117
D12   --> D118
D13   --> D119
D14   --> D120
D15   --> D121
D16   --> D122
D17   --> D123
D18   --> D124
D20   --> D125
D21   --> D126
D22   --> D127
D23   --> D128
D24   --> D129
D25   --> D130
D26   --> D131
D27   --> D132
D28   --> D133
D29   --> D134
D30   --> D135
D31   --> D136
D32   --> D137
D33   --> D138
D34   --> D139
D35   --> D140
D36   --> D141
D37   --> D142
D38   --> D143
D39   --> D144
D40   --> D145
D41   --> D146
D42   --> D147
D43   --> D148
D44   --> D149
D45   --> D150
-----------------------------------------------------------------

   ---- Transcoding 'C:\Users\rbarnich\smartmic\SM1000-C\GERBERS\SM1000-C.L2' ----   Tue Nov 18 13:40:55 2014

D10   --> D151
D11   --> D152
D12   --> D153
D13   --> D154
D14   --> D155
D15   --> D156
D16   --> D157
D17   --> D158
D18   --> D159
D19   --> D160
D20   --> D161
D21   --> D162
-----------------------------------------------------------------

   ---- Transcoding 'C:\Users\rbarnich\smartmic\SM1000-C\GERBERS\SM1000-C.L3' ----   Tue Nov 18 13:40:55 2014

D10   --> D163
D11   --> D164
D12   --> D165
D13   --> D166
D14   --> D167
D15   --> D168
D16   --> D169
D17   --> D170
D18   --> D171
D19   --> D172
D20   --> D173
D21   --> D174
D22   --> D175
D23   --> D176
-----------------------------------------------------------------

   ---- Transcoding 'C:\Users\rbarnich\smartmic\SM1000-C\GERBERS\SM1000-C.L4' ----   Tue Nov 18 13:40:55 2014

D10   --> D177
D11   --> D178
D12   --> D179
D13   --> D180
D14   --> D181
D15   --> D182
D16   --> D183
D17   --> D184
D18   --> D185
D19   --> D186
D20   --> D187
D21   --> D188
D22   --> D189
D23   --> D190
D24   --> D191
D25   --> D192
D26   --> D193
D27   --> D194
D28   --> D195
D29   --> D196
D30   --> D197
D31   --> D198
D32   --> D199
D33   --> D200
D34   --> D201
-----------------------------------------------------------------

   ---- Transcoding 'C:\Users\rbarnich\smartmic\SM1000-C\GERBERS\SM1000-C.slk' ----   Tue Nov 18 13:40:55 2014

D10   --> D202
D11   --> D203
D12   --> D204
D13   --> D205
D14   --> D206
D15   --> D207
D16   --> D208
D17   --> D209
D18   --> D210
D19   --> D211
D20   --> D212
D21   --> D213
D22   --> D214
D23   --> D215
D24   --> D216
D25   --> D217
D26   --> D218
D27   --> D219
D28   --> D220
-----------------------------------------------------------------

   ---- Transcoding 'C:\Users\rbarnich\smartmic\SM1000-C\GERBERS\SM1000-C.smb' ----   Tue Nov 18 13:40:55 2014

D10   --> D221
D11   --> D222
D12   --> D223
D13   --> D224
D14   --> D225
D15   --> D226
D16   --> D227
D17   --> D228
D18   --> D229
D19   --> D230
D20   --> D231
D21   --> D232
D22   --> D233
D23   --> D234
D24   --> D235
D25   --> D236
D26   --> D237
D27   --> D238
D28   --> D239
-----------------------------------------------------------------

   ---- Transcoding 'C:\Users\rbarnich\smartmic\SM1000-C\GERBERS\SM1000-C.smt' ----   Tue Nov 18 13:40:55 2014

D10   --> D240
D11   --> D241
D12   --> D242
D13   --> D243
D14   --> D244
D15   --> D245
D16   --> D246
D17   --> D247
D18   --> D248
D19   --> D249
D20   --> D250
D21   --> D251
D22   --> D252
D23   --> D253
D24   --> D254
D25   --> D255
D26   --> D256
D27   --> D257
D28   --> D258
D29   --> D259
D30   --> D260
D31   --> D261
D32   --> D262
D33   --> D263
D34   --> D264
D35   --> D265
D36   --> D266
D37   --> D267
D38   --> D268
D39   --> D269
D40   --> D270
D41   --> D271
D42   --> D272
D43   --> D273
D44   --> D274
D45   --> D275
D46   --> D276
-----------------------------------------------------------------

   ---- Transcoding 'C:\Users\rbarnich\smartmic\SM1000-C\GERBERS\SM1000-C.tps' ----   Tue Nov 18 13:40:55 2014

D10   --> D277
D11   --> D278
D12   --> D279
D13   --> D280
D14   --> D281
D15   --> D282
D16   --> D283
D17   --> D284
D18   --> D285
D19   --> D286
D20   --> D287
D21   --> D288
D22   --> D289
D23   --> D290
D24   --> D291
D25   --> D292
D26   --> D293
D27   --> D294
D28   --> D295
D29   --> D296
D30   --> D297
-----------------------------------------------------------------

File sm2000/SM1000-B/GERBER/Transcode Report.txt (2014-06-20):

   ---- Transcoding 'C:\Users\rbarnich\smartmic\SM1000-REV-B\GERBER\SM1000-REV-B1.ast' ----   Wed Jun 18 11:47:53 2014

D10   --> D100
D11   --> D101
D12   --> D102
D13   --> D103
D14   --> D104
D15   --> D105
D16   --> D106
-----------------------------------------------------------------

   ---- Transcoding 'C:\Users\rbarnich\smartmic\SM1000-REV-B\GERBER\SM1000-REV-B1.bps' ----   Wed Jun 18 11:47:53 2014

D10   --> D107
D11   --> D108
D12   --> D109
D13   --> D110
D14   --> D111
-----------------------------------------------------------------

   ---- Transcoding 'C:\Users\rbarnich\smartmic\SM1000-REV-B\GERBER\SM1000-REV-B1.drt' ----   Wed Jun 18 11:47:56 2014

D10   --> D112
D11   --> D113
D12   --> D114
D13   --> D115
-----------------------------------------------------------------

   ---- Transcoding 'C:\Users\rbarnich\smartmic\SM1000-REV-B\GERBER\SM1000-REV-B1.L1' ----   Wed Jun 18 11:47:58 2014

D10   --> D116
D11   --> D117
D12   --> D118
D13   --> D119
D14   --> D120
D15   --> D121
D16   --> D122
D17   --> D123
D18   --> D124
D19   --> D125
D20   --> D126
D21   --> D127
D22   --> D128
D23   --> D129
D24   --> D130
D25   --> D131
D26   --> D132
D27   --> D133
D28   --> D134
D29   --> D135
D30   --> D136
D31   --> D137
D32   --> D138
D33   --> D139
D34   --> D140
D35   --> D141
-----------------------------------------------------------------

   ---- Transcoding 'C:\Users\rbarnich\smartmic\SM1000-REV-B\GERBER\SM1000-REV-B1.L2' ----   Wed Jun 18 11:47:58 2014

D10   --> D142
D11   --> D143
D12   --> D144
D13   --> D145
D14   --> D146
D15   --> D147
D16   --> D148
D17   --> D149
D18   --> D150
D19   --> D151
-----------------------------------------------------------------

   ---- Transcoding 'C:\Users\rbarnich\smartmic\SM1000-REV-B\GERBER\SM1000-REV-B1.L3' ----   Wed Jun 18 11:47:58 2014

D10   --> D152
D11   --> D153
D12   --> D154
D13   --> D155
D14   --> D156
D15   --> D157
D16   --> D158
D17   --> D159
D18   --> D160
D19   --> D161
D20   --> D162
D21   --> D163
-----------------------------------------------------------------

   ---- Transcoding 'C:\Users\rbarnich\smartmic\SM1000-REV-B\GERBER\SM1000-REV-B1.L4' ----   Wed Jun 18 11:47:58 2014

D10   --> D164
D11   --> D165
D12   --> D166
D13   --> D167
D14   --> D168
D15   --> D169
D16   --> D170
D17   --> D171
D18   --> D172
D19   --> D173
D20   --> D174
D21   --> D175
D22   --> D176
D23   --> D177
D24   --> D178
D25   --> D179
D26   --> D180
D27   --> D181
D28   --> D182
D29   --> D183
D30   --> D184
D31   --> D185
D32   --> D186
D33   --> D187
D34   --> D188
-----------------------------------------------------------------

   ---- Transcoding 'C:\Users\rbarnich\smartmic\SM1000-REV-B\GERBER\SM1000-REV-B1.oln' ----   Wed Jun 18 11:47:58 2014

D10   --> D189
-----------------------------------------------------------------

   ---- Transcoding 'C:\Users\rbarnich\smartmic\SM1000-REV-B\GERBER\SM1000-REV-B1.slk' ----   Wed Jun 18 11:47:58 2014

D10   --> D190
D11   --> D191
D12   --> D192
D13   --> D193
D14   --> D194
D15   --> D195
D16   --> D196
D17   --> D197
D18   --> D198
D19   --> D199
D20   --> D200
D21   --> D201
D22   --> D202
D23   --> D203
D24   --> D204
D25   --> D205
D26   --> D206
-----------------------------------------------------------------
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

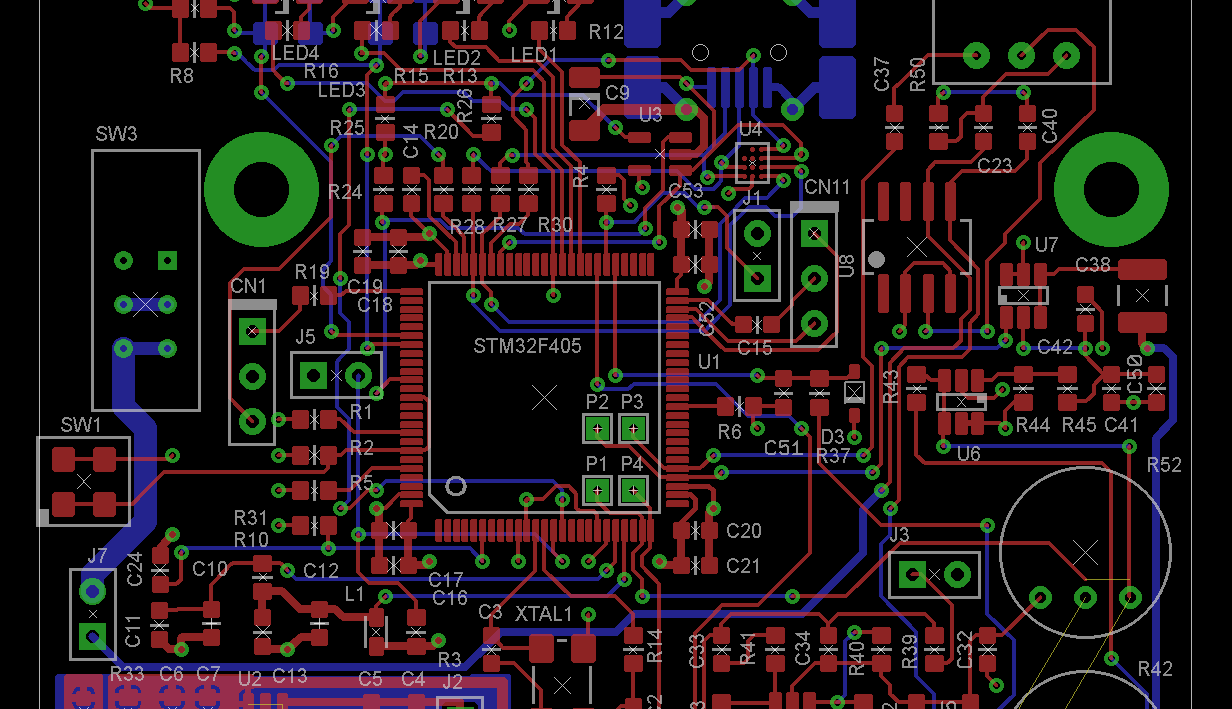
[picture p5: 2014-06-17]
sm2000/SM1000-B/IMAGES/TP-SM1000-REV-B.png

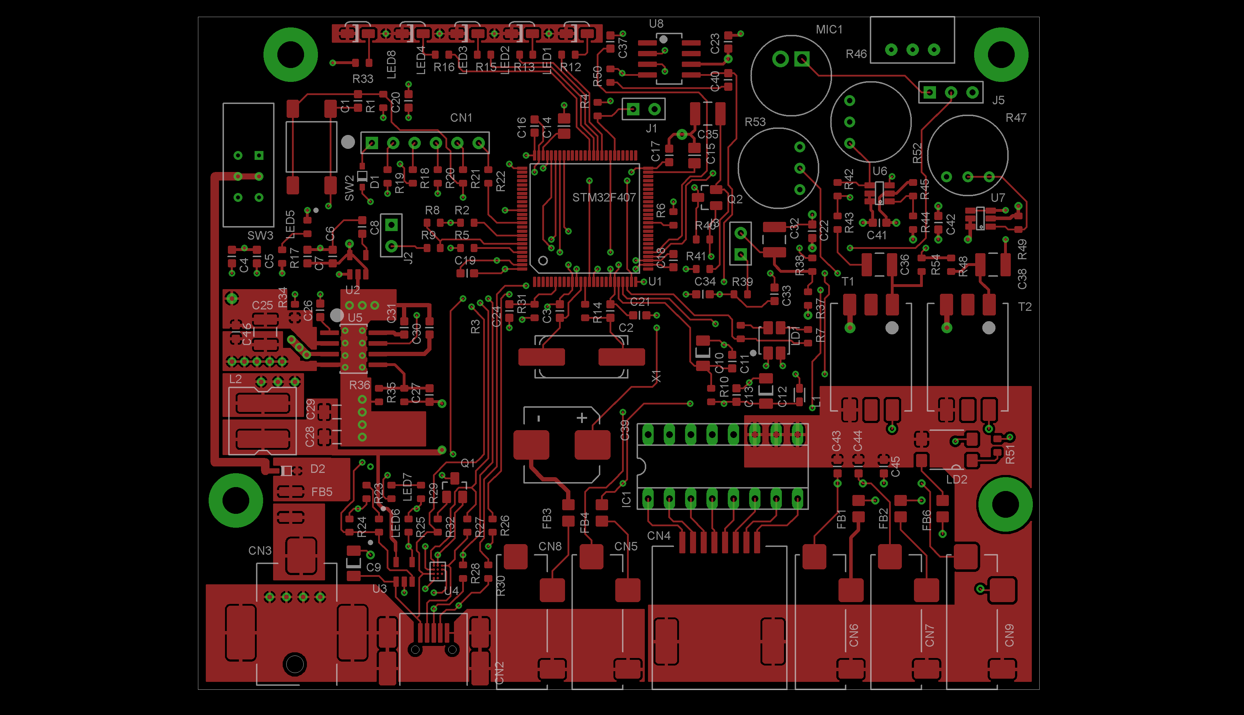
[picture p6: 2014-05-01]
sm2000/SM1000-A/Images/PCB-SM1000.png

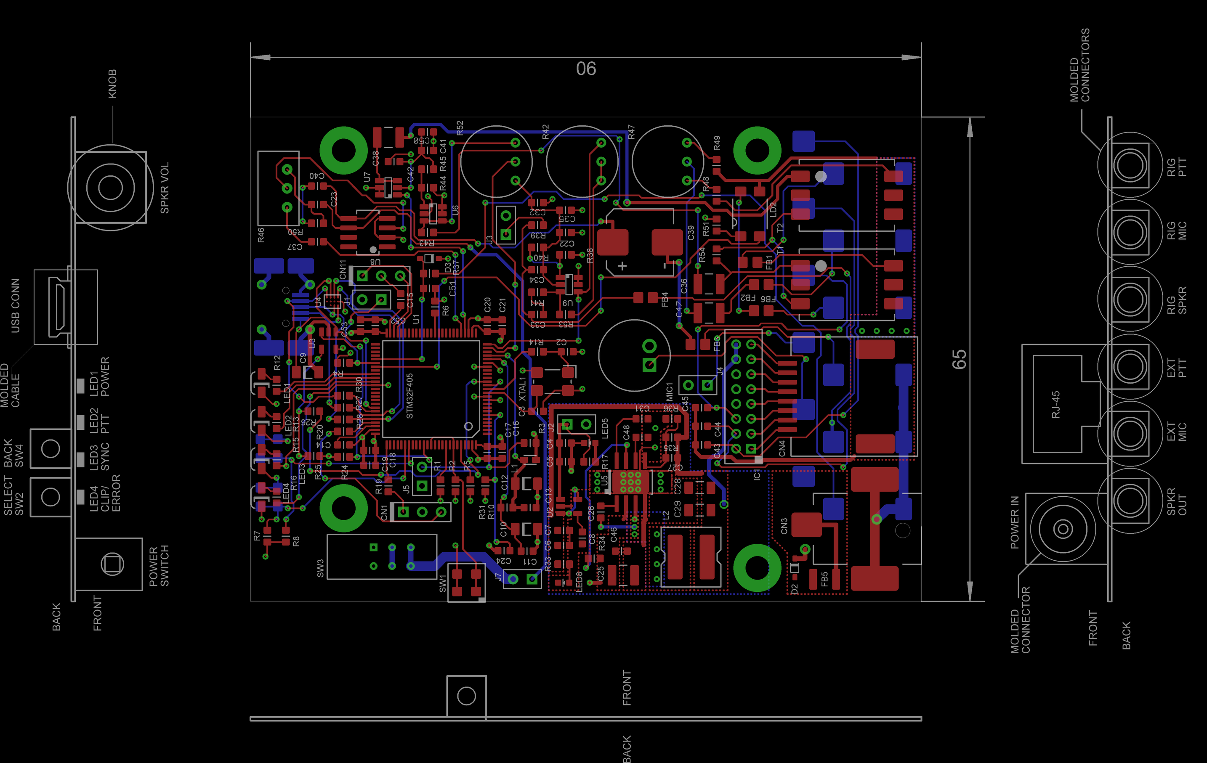
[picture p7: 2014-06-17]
smartmic/SM1000-B/IMAGES/rsz_1pkg-sm1000-rev-b.png

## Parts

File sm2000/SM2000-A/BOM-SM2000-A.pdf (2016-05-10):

Bill of Materials from SM2000-A.sch, 455 parts, grouped by values, as of 5/5/2016 9:42:22 AM

Part | Qty DEFINITION | MANUFACTURER | MFG_NUMBER | DISTRIBUTOR | DIST_NUMBER | GENERIC | ROHS | COST100 EXT COST
C1, C3, C4, C8, C11, C12, C14, C20, C24, C30, C33, C35, C37, C41, C45, C48, C49, C56, C57, C58, C59,
C60, C61, C63, C65, C68, C70, C71, C84, C90, C94, C104, C108, C111, C113, C114, C117, C118, C119,
C120, C121, C125, C127, C133, C134, C137, C138, C144 | 48 | CAP CER 0.1UF 25V X7R 0805 | MURATA | GRM21BR71E104KA01L | DIGIKEY | 490-1673-1-ND | Y | Y | 0.020 | 0.960
C2, C5, C9, C15, C25 | 5 | CAP CER 10000PF 25V X7R 0805 | MURATA | GRM216R71E103KA01D | DIGIKEY | 490-12748-1-ND | Y | Y | 0.032 | 0.160
C6, C7, C16, C77 | 4 | CAP CER 1UF 25V X7R 0805 | MURATA | GRM21BR71E105KA99K | DIGIKEY | 490-6483-1-ND | Y | Y | 0.053 | 0.213
C10, C27, C40, C72, C73, C74, C75, C76, C78, C81, C91, C96, C97, C98, C100, C102, C103, C106, C131,
C132, C135 | 21 | CAP CER 1000PF 25V X7R | MURATA | GRM216R71E102KA01D | DIGIKEY | 490-11555-1-ND | Y | Y | 0.029 | 0.609
C13, C139, C140, C141, C142, C143 | 6 | PART VALUE TO BE DETERMINED | | | | | Y | Y | 0.000 | 0.000
C17, C18, C38 | 3 | CAP CER 2.2UF 25V X7R 0805 | MURATA | GRM21BR71E225KA73L | DIGIKEY | 490-3331-1-ND | Y | Y | 0.265 | 0.795
C19, C21, C51 | 3 | CAP CER 20PF 50V NP0 0805 | MURATA | GQM2195C1H200JB01D | DIGIKEY | 490-3607-1-ND | Y | Y | 0.364 | 1.092
C22 | 1 | CAP CER 4.7UF 25V X7R 0805 | MURATA | GRM21BR71E475KA73L | DIGIKEY | 490-9962-1-ND | Y | Y | 0.210 | 0.210
C23 | 1 | CAP CER 0.33UF 25V X7R 0805 | MURATA | GRM21BR71E334KA01L | DIGIKEY | 490-1677-1-ND | Y | Y | 0.109 | 0.109
C26, C29, C36, C42, C43, C44, C54 | 7 | CAP CER 22UF 25V X7R 20% 1812 | TDK | C4532X7R1E226M | DIGIKEY | 445-1607-1-ND | YES | YES | 1.950 | 13.650
C28 | 1 | CAP CER 0.22UF 25V X7R 0805 | MURATA | GRM219R71E224KA01D | DIGIKEY | 490-1675-1-ND | Y | Y | 0.084 | 0.084
C31, C32 | 2 | CAP ALUM 100UF 6.3V 20% SMD | NICHICON | UWX0J101MCL1GB | DIGIKEY | 493-2088-1-ND | Y | Y | 0.114 | 0.228
C34, C52, C55 | 3 | CAP ALUM 220UF 25V 20% SMD | UNITED CHEMI-CON EMVY250ADA221MHA0G | DIGIKEY | 565-2463-1-ND | N | Y | 0.412 | 1.236
C39 | 1 | CAP CER 100PF 50V NP0 0805 | MURATA | GRM2165C1H101JA01D | DIGIKEY | 490-1615-1-ND | Y | Y | 0.039 | 0.039
C46 | 1 | CAP CER 0.47UF 25V X7R 0805 | MURATA | GRM21BR71E474KA01L | DIGIKEY | 490-9753-1-ND | Y | Y | 0.154 | 0.154
C47, C88, C116 | 3 | CAP CER 8200PF 25V X7R 0805 | AVX | 08053C822KAT4A | DIGIKEY | 08053C822KAT4A-ND | Y | Y | 0.000 | 0.000
C50 | 1 | CAP CER 3900PF 25V X7R 0805 | AVX | 08053C392MAT2A | DIGIKEY | 08053C392MAT2A-ND | Y | Y | 0.000 | 0.000
C53 | 1 | CAP CER 0.047UF 25V X7R | MURATA | GRM219R71E473KA01D | DIGIKEY | 490-11583-1-ND | Y | Y | 0.054 | 0.054
C62, C69, C80, C89 | 4 | CAP CER 3.3PF 25V NP0 0805 | AVX | 08053A3R3JAT2A | DIGIKEY | 08053A3R3JAT2A-ND | Y | Y | 0.000 | 0.000
C64, C67, C82, C86 | 4 | CAP CER 12PF 25V NP0 0805 | AVX | 08053A120KAT2A | DIGIKEY | 08053A120KAT2A-ND | Y | Y | 0.000 | 0.000
C66, C85 | 2 | CAP CER 0.50PF 25V NP0 0805 | AVX | 08053A0R5CAT4A | DIGIKEY | 08053A0R5CAT4A-ND | Y | Y | 0.000 | 0.000
C79, C92, C93, C95 | 4 | CAP CER 22PF 50V 5% NPO 0805 | YAGEO | CC0805JRNPO9BN220 | DIGIKEY | 311-1103-1-ND | Y | Y | 0.047 | 0.187
C83 | 1 | CAP TRIM 2-10PF 250V THRU HOLE | VISHAY BC | BFC280851109 | DIGIKEY | BFC280851109-ND | N | Y | 2.270 | 2.270
C87, C115 | 2 | CAP CER 5.6PF 50V NP0 0805 | MURATA | GRM2165C1H5R6CD01D | DIGIKEY | GRM2165C1H5R6CD01D-ND | Y | Y | 0.000 | 0.000
C99 | 1 | CAP CER 1000PF 25V X7R | | | | | | | 0.000 | 0.000
C101 | 1 | CAP CER 1PF 50V NP0 0805 | SAMSUNG | CL21C010BBANNNC | DIGIKEY | 1276-1766-1-ND | Y | Y | 0.011 | 0.011
C105, C110 | 2 | CAP CER 33PF 50V NP0 0805 | SAMSUNG | CL21C330JBANNNC | DIGIKEY | 1276-1105-1-ND | Y | Y | 0.022 | 0.044
C107 | 1 | CAP CER 47PF 50V NP0 0805 | SAMSUNG | CL21C470JBANNNC | DIGIKEY | 1276-1156-1-ND | Y | Y | 0.022 | 0.022
C109 | 1 | CAP ALUM 100UF 20% 25V SMD | UNITED CHEMI-CON EMVA250ADA101MF80G | DIGIKEY | 565-2105-1-ND | N | Y | 0.250 | 0.250
C112 | 1 | CAP CER 39PF 50V NP0 0805 | SAMSUNG | CL21C390JBANNNC | DIGIKEY | 1276-1769-1-ND | Y | Y | 0.027 | 0.027
C122, C126, C129, C130, C136 | 5 | CAP ALUM 10UF 20% 25V SMD | NICHICON | UWJ1E100MCL1GB | DIGIKEY | 493-9791-1-ND | N | Y | 0.118 | 0.590
C123 | 1 | CAP CER 27PF 50V NP0 0805 | SAMSUNG | CL21C270JBANNNC | DIGIKEY | 1276-1285-1-ND | Y | Y | 0.027 | 0.027
C124, C128 | 2 | CAP CER 150PF 50V NP0 0805 | SAMSUNG | CL21C151JBANNNC | DIGIKEY | 1276-1828-1-ND | Y | Y | 0.025 | 0.050
CN1, CN3 | 2 | CONN HEADER 3POS .100 VERT GOLD | MOLEX | 22-10-2031 | DIGIKEY | WM2723-ND | N | Y | 0.495 | 0.990
CN2, CN6, CN7 | 3 | 3.5mm STEREO, SWITCHED SMT CONN. | JISEN | ST-3509 | JISEN | ST-3509 | N | Y | 0.200 | 0.600
CN4 | 1 | MINIB USB CONN, SMT | JISEN | JS-MU3-002 | JISEN | JS-MU3-002 | N | Y | 0.500 | 0.500
CN5 | 1 | DC POWER CONN, FOR 2.1 X 5.5MM | YQLXDZ | DS-0518 | YQLXDZ | DS-0518 | N | Y | 0.300 | 0.300
D1, D2 | 2 | DO NOT LOAD | NA | NA | NA | NA | NA | NA | 0.000 | 0.000
D3 | 1 | PTVS20VP1UP | NXP | PTVS20VP1UP,115 | DIGIKEY | 568-5319-1-ND | Y | Y | 0.321 | 0.321
D4 | 1 | DIODE SCHOTTKY 30V 3A SMB | DIODES INC. | B330B-13-F | DIGIKEY | B330B-FDICT-ND | Y | Y | 0.318 | 0.318
D5 | 1 | DO NOT LOAD | NA | NA | NA | NA | NA | NA | 0.000 | 0.000
D6, D7, D8, D9 | 4 | DIODE RF PIN 150V 100MA SC79 | INFINEON | BAR 64-02V H6327 | DIGIKEY | BAR 64-02V H6327CT-ND | Y | Y | 0.187 | 0.748
D10 | 1 | DIODE ARRAY GP 35V 100MA SOT23 | INFINEON | BAT 18-04 E6327 | DIGIKEY | BAT 18-04 E6327CT-ND | Y | Y | 0.265 | 0.265
FB1, FB2, FB3, FB4, FB5, FB6, FB7, FB8, FB9, FB10, FB11, FB12, FB13, FB14, FB15, FB16, FB17, FB18,
FB19, FB20 | 20 | FERRITE 500MA 600 OHM 0805 SMD | lAIRD | HZ0805E601R-10 | DIGIKEY | 240-2399-1-ND | N | Y | 0.038 | 0.762
J1, J3, J5 | 3 | CONN HEADER 2POS .100 VERT GOLD | MOLEX | 22-28-4023 | DIGIKEY | WM6502-ND | Y | Y | 0.190 | 0.570
J2 | 1 | CONN HEADER 7POS .100 VERT GOLD | MOLEX | 22284073 | DIGIKEY | WM50016-07-ND | Y | Y | 0.425 | 0.425
J4 | 1 | CONN HEADER XH TOP 2POS 2.5MM | JST | B2B-XH-AM | DIGIKEY | 455-2273-ND | Y | Y | 0.092 | 0.092
J6, J7, J8, J9, J10, J11, J12, J13, J14 | 9 | CONN HEADER 4POS .100 STR 30AU | FCI | 67996-104HLF | DIGIKEY | 609-3201-ND | Y | Y | 0.178 | 1.602
L1 | 1 | INDUCTOR POWER 4.2UH 2.5A SMD | BOURNS | SRR5028-4R2Y | DIGIKEY | SRR5028-4R2YCT-ND | N | N | 0.456 | 0.456
L2, L3, L5, L8 | 4 | 68nH | ROWETEL | | | | | | 0.000 | 0.000
L4, L14, L16 | 3 | 57nH | ROWETEL | | | | | | 0.000 | 0.000
L6 | 1 | 168nH | ROWETEL | | | | | | 0.000 | 0.000
L9 | 1 | 54nH | ROWETEL | | | | | | 0.000 | 0.000
L10 | 1 | 53nH | ROWETEL | | | | | | 0.000 | 0.000
L11 | 1 | 220nH | ROWETEL | | | | | | 0.000 | 0.000
L12, L13, L15 | 3 | RF CHOKE | TBD | | TBD | | | Y | 0.000 | 0.000
L17 | 1 | FIXED IND 5.6UH 15MA 600 MOHM | TDK | 445-1056-1-ND | DIGIKEY | 445-1056-1-ND | N | Y | 0.129 | 0.129
L18 | 1 | FIXED IND 10UH 10MA 1.7 OHM SMD | TDK | MLF1608E100KTD00 | DIGIKEY | 445-1025-1-ND | N | Y | 0.119 | 0.119
L19 | 1 | FIXED IND 5.6UH 15MA 600 MOHM | TDK | MLF2012E5R6KT000 | DIGIKEY | 445-1056-1-ND | N | Y | 0.129 | 0.129
L20 | 1 | FIXED IND 15UH 250MA 950 MOHM | TDK | MLZ2012M150WT000 | DIGIKEY | 445-6397-1-ND | N | Y | 0.088 | 0.088
LED1, LED3, LED7 | 3 | LED GREEN CLEAR RT ANG 0805 | LITE-ON | LTST-S220KGKT | DIGIKEY | 160-1468-1-ND | N | Y | 0.135 | 0.405

LED2, LED4 | 2 | LED SUPR RED CLR RT ANG 0805 | LITE-ON | LTST-S220KRKT | DIGIKEY | 160-1469-1-ND | N | Y | 0.145 | 0.290
LED5, LED6, LED8, LED10 | 4 | LED GREEN DIFFUSED 0603 SMD | LUMEX | SML-LX0603GW-TR | DIGIKEY | 67-1549-1-ND | N | Y | 0.169 | 0.676
LED9 | 1 | LED RED DIFFUSED 0603 SMD | LUMEX | SML-LX0603SRW-TR | DIGIKEY | 67-1551-1-ND | N | Y | 0.169 | 0.169
LED11 | 1 | LED YELLOW DIFFUSED 0603 SMD | LUMEX | SML-LX0603YW-TR | DIGIKEY | 67-1550-1-ND | N | Y | 0.162 | 0.162
MIC1 | 1 | MIC COND ANALOG OMNI -44DB | CUI | CMA-4544PF-W | DIGIKEY | 102-1721-ND | N | Y | 0.569 | 0.569
P6, P7, P8, P9 | 4 | TEST PAD, .050 | NA | NA | NA | NA | NA | NA | 0.000 | 0.000
PAD1, PAD2, PAD3, PAD4, PAD5, PAD6, PAD7 | 7 | NOT A PART | | | | | | | 0.000 | 0.000
PCB1 | 1 | SM2000-A PCB | PCB UNIVERSE | SM2000-A | NA | NA | N | Y | 11.320 | 11.320
Q1, Q3, Q5, Q6, Q7, Q8, Q9, Q10, Q14, Q15, Q16 | 11 | TRANSISTOR GP NPN AMP SOT-23 | FAIRCHILD SEMI | MMBT3904 | DIGIKEY | MMBT3904FSCT-ND | YES | YES | 0.043 | 0.473
Q2, Q4 | 2 | MOSFET P-CH 30V 2A SOT-23 | STM | STR2P3LLH6 | DIGIKEY | 497-15520-1-ND | Y | Y | 0.216 | 0.432
Q11 | 1 | TRANSISTOR RF NPN 15V SOT-23 | INFINEON | BFR 92P E6327 | DIGIKEY | BFR92PE6327INCT-ND | Y | Y | 0.212 | 0.212
Q12 | 1 | TRANSISTOR RF NPN 15V SOT-89 | INFINEON | BFQ 19S E6327 | DIGIKEY | BFQ 19S E6327CT-ND | Y | Y | 0.409 | 0.409
Q13 | 1 | RD01MUS2 RoHS Compliance, Silicon MOSFET Power Transistor 520MHz, 1W, MITSUBISHI | RD01MUS2 | RF PARTS | RD01MUS2 | N | Y | 0.800 | 0.800
Q17 | 1 | TRANSISTOR GP PNP AMP SOT-23 | FAIRCHILD | MMBT3906 | DIGIKEY | MMBT3906FSCT-ND | Y | Y | 0.100 | 0.100
R1, R2, R3, R4, R55, R63, R74 | 7 | RES SMD 680 OHM 1% 1/8W 0805 | VISHAY DALE | CRCW0805680RFKEA | DIGIKEY | 541-680CCT-ND | Y | Y | 0.028 | 0.196
R5, R6, R21, R24 | 4 | RES SMD 22 OHM 1% 1/8W 0805 | VISHAY DALE | CRCW080522R0FKEA | DIGIKEY | 541-22.0CCT-ND | Y | Y | 0.028 | 0.112
R7, R8, R9, R10, R28, R29, R89 | 7 | RES SMD 4.7K OHM 1% 1/8W 0805 | VISHAY DALE | CRCW08054K70FKEA | DIGIKEY | 541-4.70KCCT-ND | Y | Y | 0.028 | 0.196
R11, R50, R57, R87, R99, R100, R106, R107, R113 | 9 | RES 1.00K OHM 1/8W 1% 0805 SMD | VISHAY/DALE | CRCW08051K00FKEA | DIGIKEY | 541-1.00KCCT-ND | Y | Y | 0.033 | 0.297
R12, R62, R75 | 3 | RES SMD 47 OHM 1% 1/8W 0805 | VISHAY DALE | CRCW080547R0FKEA | DIGIKEY | 541-47.0CCT-ND | Y | Y | 0.028 | 0.084
R13, R14, R16, R26, R41, R96, R97, R98 | 8 | RES 0.0 OHM 1/8W 0805 SMD | VISHAY/DALE | CRCW08050000Z0EA | DIGIKEY | 541-0.0ACT-ND | Y | Y | 0.030 | 0.240
R15 | 1 | RES SMD 220 OHM 1% 1/8W 0805 | VISHAY DALE | CRCW0805220RFKEA | DIGIKEY | 541-220CCT-ND | Y | Y | 0.028 | 0.028
R17, R18, R20, R22, R27, R43, R46, R54, R59, R76, R80, R81, R83, R95, R121, R122 | 16 | RES 10.0K OHM 1/8W 1% 0805 SMD | VISHAY/DALE | CRCW080510K0FKEA | DIGIKEY | 541-10.0KCCT-ND | Y | Y | 0.028 | 0.448
R19, R64, R73 | 3 | RES SMD 470 OHM 1% 1/8W 0805 | VISHAY DALE | CRCW0805470RFKEA | DIGIKEY | 541-470CCT-ND | Y | Y | 0.028 | 0.084
R23, R33, R35, R36, R37, R38, R47, R56, R60, R67, R70, R77, R90, R112 | 14 | RES 2.20K OHM 1/8W 1% 0805 SMD | PANASONIC | ERJ-6ENF2201V | DIGIKEY | P2.20KCCT-ND | Y | Y | 0.021 | 0.294
R25 | 1 | RES SMD 47K OHM 1% 1/8W 0805 | VISHAY DALE | CRCW080547K0FKEA | DIGIKEY | 541-47.0KCCT-ND | Y | Y | 0.028 | 0.028
R30, R42 | 2 | RES SMD 1.5K OHM 1% 1/8W 0805 | VISHAY DALE | CRCW08051K50FKEA | DIGIKEY | 541-1.50KCCT-ND | Y | Y | 0.028 | 0.056
R31, R32, R114, R119 | 4 | RES 100 OHM 1/8W 1% 0805 SMD | VISHAY/DALE | CRCW0805100RFKEA | DIGIKEY | 541-100CCT-ND | Y | Y | 0.033 | 0.132
R34, R40, R44, R65, R71, R93 | 6 | RES SMD 330 OHM 1% 1/8W 0805 | VISHAY DALE | CRCW0805330RFKEA | DIGIKEY | 541-330CCT-ND | Y | Y | 0.028 | 0.168
R39 | 1 | TRIMMER 500K OHM 0.5W SMD | BOURNS | 3361P-1-504GLF | DIGIKEY | 3361P-1-504GLFCT-ND | Y | Y | 0.969 | 0.969
R45, R52 | 2 | RES SMD 22.1K OHM 1% 1/8W 0805 | VISHAY DALE | CRCW080522K1FKEA | DIGIKEY | 541-22.1KCCT-ND | Y | Y | 0.028 | 0.056
R48 | 1 | POT 100K OHM 9MM SQ RTANG PLAST | BOURNS | 3310C-001-104L | DIGIKEY | 3310C-001-104L-ND | N | Y | 1.920 | 1.920
R49 | 1 | RES SMD 4.7 OHM 5% 1/2W 1206 | VISHAY DALE | CRCW12064R70JNEAHP | DIGIKEY | 541-4.7UACT-ND | Y | Y | 0.128 | 0.128
R51 | 1 | RES SMD 124K OHM 1% 1/8W 0805 | VISHAY DALE | CRCW0805124KFKEA | DIGIKEY | 541-124KCCT-ND | Y | Y | 0.028 | 0.028
R53, R58, R61, R85, R91, R108, R115, R120 | 8 | RES SMD 10 OHM 1% 1/8W 0805 | VISHAY DALE | CRCW080510R0FKEA | DIGIKEY | 541-10.0CCT-ND | Y | Y | 0.028 | 0.224
R66, R72 | 2 | RES SMD 180 OHM 1% 1/8W 0805 | VISHAY DALE | CRCW0805180RFKEA | DIGIKEY | 541-180CCT-ND | Y | Y | 0.028 | 0.056
R68, R69 | 2 | RES SMD 15 OHM 1% 1/8W 0805 | VISHAY DALE | CRCW080515R0FKEA | DIGIKEY | 541-15.0CCT-ND | Y | Y | 0.028 | 0.056
R78, R79, R111 | 3 | RES SMD 18K OHM 1% 1/8W 0805 | VISHAY DALE | CRCW080518K0FKEA | DIGIKEY | 541-18.0KCCT-ND | Y | Y | 0.028 | 0.084
R82, R86, R105 | 3 | RES SMD 3K OHM 1% 1/8W 0805 | VISHAY DALE | CRCW08053K00FKEA | DIGIKEY | 541-3.00KCCT-ND | Y | Y | 0.028 | 0.084
R84, R101, R102, R116 | 4 | RES SMD 150 OHM 1% 1/8W 0805 | VISHAY DALE | CRCW0805150RFKEA | DIGIKEY | 541-150CCT-ND | Y | Y | 0.028 | 0.112
R88, R109 | 2 | RES SMD 49.9 OHM 1% 1/8W 0805 | VISHAY/DALE | CRCW080549R9FKEA | DIGIKEY | 541-49.9CCT-ND | YES | YES | 0.028 | 0.056
R92 | 1 | RES SMD 47 OHM 1% 1/8W 0805 | VISHAY DALE | CRCW080547R0FKEA | DIGIKEY | 541-47.0CCT-ND | Y | Y | 0.028 | 0.028
R94 | 1 | RES SMD 68K OHM 1% 1/8W 0805 | VISHAY DALE | CRCW080568K0FKEA | DIGIKEY | 541-68.0KCCT-ND | Y | Y | 0.028 | 0.028
R103 | 1 | RES SMD 33K OHM 1% 1/8W 0805 | VISHAY DALE | CRCW080533K0FKEA | DIGIKEY | 541-33.0KCCT-ND | Y | Y | 0.028 | 0.028
R104 | 1 | RES SMD 15K OHM 1% 1/8W 0805 | VISHAY DALE | CRCW080515K0FKEA | DIGIKEY | 541-15.0KCCT-ND | Y | Y | 0.028 | 0.028
R110 | 1 | RES SMD 39K OHM 1% 1/8W 0805 | VISHAY DALE | CRCW080539K0FKEA | DIGIKEY | 541-39.0KCCT-ND | Y | Y | 0.028 | 0.028
R117, R118 | 2 | RES SMD 3.3K OHM 1% 1/8W 0805 | VISHAY DALE | CRCW08053K30FKEA | DIGIKEY | 541-3.30KCCT-ND | Y | Y | 0.028 | 0.056
R123, R124, R125, R126, R127 | 5 | PART TO BE DETERMINED | | | | | Y | Y | 0.000 | 0.000
S1, S2, S3, S4, S5, S6, S8, S9, S10, S11, S12, S14, S15, S16, S17, S18, S20, S21, S22, S23, S24, S25, S26,
S27, S28, S29, S30, S31, S35, S36, S37, S38, S39, S40, S43 | 35 | NOT A PART | | | | | | | 0.000 | 0.000
SH1, SH2, SH3 | 3 | SHUNT LP 2 POS SN | TYCO AMP | 1-382811-6 | DIGIKEY | A26231-ND | Y | Y | 0.210 | 0.630
SP1, SP2, SP3, SP4, SP5, SP6, SP7, SP8, SP9 | 9 | SCOPE TEST PAD | NA | NA | NA | NA | NA | NA | 0.000 | 0.000
SW1 | 1 | 4.5X4.5mm TACT SWITCH SMT | YQLXDZ | TS-02B | YQLXDZ.COM | TS-02B | N | Y | 0.050 | 0.050
SW2 | 1 | SWITCH PUSH DPDT 0.3A 30V | E-SWITCH | LC2259OANP | DIGIKEY | LC2259OANP-ND | Y | Y | 0.620 | 0.620
SW3, SW4 | 2 | 4.5X4.5mm TACTILE SWIRCH RA TH | YQLXDZ | TS-026 | YQLXDZ | TS-026 | N | Y | 0.050 | 0.100
SW5 | 1 | SWITCH PUSH DPDT 0.3A 30V | E-SWITCH | LC2259EENP | DIGIKEY | LC2259EENP-ND | Y | Y | 0.620 | 0.620
U1 | 1 | IC MCU 32BIT 1MB FLASH 100LQFP | STM | STM32F405VGT6 | DIGIKEY | 497-11910-ND | N | Y | 9.364 | 9.364
U2 | 1 | IC PWR SWITCH 1CH 500MA SOT23-5 | STM | STMPS2141STR | DIGIKEY | 497-6933-1-ND | N | Y | 0.480 | 0.480
U3 | 1 | I C EMI FILTR/ESD PROT 11FLIPCHIP | STM | EMIF02-USB03F2 | DIGIKEY | 497-13521-1-ND | N | Y | 0.525 | 0.525
U4 | 1 | DO NOT LOAD | NA | NA | NA | NA | NA | NA | 0.000 | 0.000
U5 | 1 | IC REG LDO 9V 0.5A DPAK | STM | L78M09CDT-TR | DIGIKEY | 497-1208-1-ND | Y | Y | 0.347 | 0.347
U6, U8 | 2 | IC REG LDO 3.3V 1A SOT223 | STM | LD1117AS33TR | DIGIKEY | 497-1228-1-ND | Y | Y | 0.445 | 0.890
U7, U13 | 2 | IC OPAMP GP 1MHZ RRO SOT23- | TI | LMV341IDBVR | DIGIKEY | 296-17843-1-ND | N | Y | 0.556 | 1.112
U9 | 1 | IC REG BUCK SYNC ADJ 3A 8SOPWR | TI | TPS54329EDDAR | DIGIKEY | 296-29856-1-ND | N | Y | 1.650 | 1.650
U10 | 1 | IC AMP AUDIO PWR .325W AB 8SOIC | TI | LM386MX-1/NOPB | DIGIKEY | LM386MX-1/NOPBCT-ND | N | Y | 0.687 | 0.687
U11 | 1 | SURFACE MOUNT FREQUENCY MIXER ADE-1 | MINI-CIRCUITS | | MINI-CIRCUITS | | N | Y | 0.000 | 0.000
U12 | 1 | ULTRA LINEAR LOW NOISE AMPLIFIER | MINI-CIRCUITS | | MINI-CIRCUITS | | N | Y | 0.000 | 0.000
U14 | 1 | IC CLK GENERATOR 200MHZ 10MSOP | SILICON LABS | SI5351A-B-GT | DIGIKEY | 336-2399-5-ND | N | Y | 0.848 | 0.848
U15 | 1 | OSC XO 10MHZ-1.4175GHZ LVPECL | SILICON LABS | 570AAC000118DG | DIGIKEY | 570AAC000118DG-ND | N | Y | 10.167 | 10.167

U16
1 | IC MIXER 500MHZ UP CONVRT 8SO | NXP | SA612AD/01,112 | DIGIKEY | 568-1204-5-ND

Y

Y | 1.640 | 1.640
X1
1 | CONN SOCKET SMA R/A DIE CAST PCB | TE Connectivity | 5-1814400-1 | DIGIKEY | A97593-ND

Y

Y | 2.660 | 2.660
XTAL1
1 | 8MHz ±30ppm Crystal 18pF 80 Ohm | CTS | 405I35D08M00000 | DIGIKEY | 405I35D08M00000-ND

Y

Y | 0.800 | 0.800
XTAL2
1 | 25MHz ±30ppm Crystal 13pF 50 Ohm | CTS | 405C35B25M00000 | DIGIKEY | CTX652CT-ND

Y

Y | 0.780 | 0.780
XTAL3, XTAL4
2 | MONO CRYST FILTER 25KHZ 4P 2PC | ECS | ECS-10.7-15B | DIGIKEY | X704-ND

N

Y | 3.900 | 7.800
TOTAL COST USD | 95.604

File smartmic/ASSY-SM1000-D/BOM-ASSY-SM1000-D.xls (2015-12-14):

Bill of Materials from ASSY-SM1000-D.sch, 16 parts, grouped by values, as of 1/21/2015 1:51:09 PM
Part | Value | Qty | DEFINITION | DISTRIBUTOR | DIST_NUMBER | GENERIC | COST100 | EXT COST | LINK
ASSY1 | ASSY-SM1000-D | 1 | TBD |  |  |  | 0.000 | 0.000
CABLE1 | CABLE,SPKR 50mm + CONNECTOR | 1 | TBD |  |  |  | 0.000 | 0.000
CABLE2 | CABLE, USB-A/F TO MICRO USB-A/M | 1 | Cable, Micro USB M to USB A F |  |  | y | 1.550 | 1.550 | http://www.tmart.com/Micro-USB-Male-to-USB-Female-Data-Cable-White_p191310.html
ENCL1 | ENCL-SM1000-B-BOTTOM | 1 | TBD |  |  |  | 0.000 | 0.000
ENCL2 | ENCL-SM1000-B-TOP | 1 | TBD |  |  |  | 0.000 | 0.000
ENCL3 | ENCL-SM1000-B-SIDE PLATE | 1 | TBD |  |  |  | 0.000 | 0.000
HDWE1 | SCREW,2-56 X 1/4 | 4 | TBD |  |  |  | 0.000 | 0.000
HDWE2 | WASHER, 2-56 | 4 | TBD |  |  |  | 0.000 | 0.000
HDWE3 | NUT, 2-56 | 4 | TBD |  |  |  | 0.000 | 0.000
HDWE4 | SCREW, SELF TAPPING, 2.2mm x 6.5mm | 4 | Fastenal, 2.2mm x 6.5mm Self Tapping Screw | Fastenal | 11511158 | Y | 0.195 | 0.780 | http://www.fastenal.com/
HDWE5 | JUMPER, 50mm X 4 | 4 | TBD |  |  | Y | 0.000 | 0.000
KNOB1 | KNOB, 3.5mm SHAFT, FOR R46 | 1 | Knob for Bourns 3310C-001 POT, 3.5mm |  |  | Y | 0.000 | 0.000
PCB1 | SM1000-D | 1 | Rowetel SM1000-D | Rowetel | SM1000-D | N | 0.000 | 0.000 | www.rowetel.com
PS1 | POWER SUPPLY, 12VDC,500ma | 1 | TBD | TBD | TBD | y | 0.000 | 0.000
SPKR1 | SPKR-HY4004M-001 | 1 | SPKR, 40mm,8Ohm | SHENZHEN HY ELECTRON | HY4004M-001 |  | 0.500 | 0.500
 |  |  |  |  | TOTAL |  |  | 2.830

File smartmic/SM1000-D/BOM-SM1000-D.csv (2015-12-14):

Bill of Materials from SM1000-D.sch, 196 parts, grouped by values, as of 3/20/2015 12:47:04 PM
Part | Qty | DEFINITION | MANUFACTURER | MFG_NUMBER | DISTRIBUTOR | DIST_NUMBER | GENERIC | ROHS | COST100
C1, C34, C55, C56 | 4 | CAP CER 1000PF 50V 10% X7R 0402 | MURATA | GRM155R71H102KA01D | DIGIKEY | 490-1303-1-ND | Y | Y | 0.006
C2, C3, C27 | 3 | CAP CER 20PF 50V 5% NP0 0402 | SAMSUNG | CL05C200JB5NNNC | DIGIKEY | 1276-1661-1-ND | Y | Y | 0.005
C4, C7, C11, C13, C16, C18, C20, C22, C23, C26, C37, C41, C42, C46, C49, C51, C52, C58, C61, C62, C66 | 21 | CAP CER 0.1UF 25V Y5V 0402 | MURATA | GRM155F51E104ZA01D | DIGIKEY | 1276-1661-1-ND | Y | Y | 0.003
C5, C6, C10, C12, C24, C65 | 6 | CAP CER 1UF 16V 10% X5R 0603 | YAEGO | CC0603KRX5R7BB105 | DIGIKEY | 311-1444-1-ND | Y | Y | 0.033
C8, C17, C19, C21, C30, C53 | 6 | CAP CER 10000PF 25V 20% X7R 0402 | SAMSUNG | CL05B103MA5NNNC | DIGIKEY | 1276-1503-1-ND | Y | Y | 0.004
C9 | 1 | CAP TANT 4.7UF 16V 10% 1206 | AVX | TAJA475K016RNJ | DIGIKEY | 478-3868-1-ND | Y | Y | 0.260
C14, C15, C35, C50 | 4 | CAP CER 2.2UF 16V 10% X5R 0603 | TDK | C1608X5R1C225K080AB | DIGIKEY | 445-5157-1-ND | Y | Y | 0.0643
C25, C29, C64, C70 | 4 | CAP CER 22UF 25V 10% X5R 1210 | MURATA | GRM32ER61E226KE15L | DIGIKEY | 490-3889-1-ND | N | Y | 0.540
C31 | 1 | CAP CER 8200PF 50V 10% X7R 0603 | SAMSUNG | CL10B822KB8NNNC | DIGIKEY | 1276-2119-1-ND | Y | Y | 0.005
C32, C59 | 2 | CAP ALUM 100UF 6.3V 20% SMD | NICHICON | UWX0J101MCL1GB | DIGIKEY | 493-2088-1-ND | Y | Y | 0.114
C33 | 1 | CAP CER 0.22UF 25V 10% X5R 0402 | TDK | C1005X5R1E224K050BC | DIGIKEY | 445-5944-1-ND | Y | Y | 0.0475
C36, C38, C47 | 3 | CAP CER 100UF 10V 20% X5R 1210 | SAMSUNG | CL32A107MPVNNNE | DIGIKEY | 1276-3364-1-ND | Y | Y | 0.735
C39, C60, C63 | 3 | CAP ALUM 220UF 25V 20% SMD | UNITED CHEMI-CON | EMVY250ADA221MHA0G | DIGIKEY | 565-2463-1-ND | N | Y | 0.412
C40 | 1 | CAP CER 0.047UF 25V 10% X7R 0402 | TDK | 445-4941-1-ND | DIGIKEY | 445-4941-1-ND | Y | Y | 0.015
C43, C44, C45, C54 | 4 | CAP CER 100PF 50V 10% NP0 0402 | SAMSUNG | CL05C101KB5NNNC | DIGIKEY | 1276-1633-1-ND | Y | Y | 0.005
C48 | 1 | CAP CER 0.47UF 25V 10% X5R 0603 | TDK | C1608X5R1E474K080AC | DIGIKEY | 445-5144-1-ND | Y | Y | 0.047
C57 | 1 | CAP CER 3900PF 50V 10% X7R 0402 | MURATA | GRM155R71H392KA01D | DIGIKEY | 490-1307-1-ND | Y | Y | 0.011
CN1, CN11 | 2 | CONN HEADER 3POS .100 VERT GOLD | MOLEX | 22-10-2031 | DIGIKEY | WM2723-ND | N | Y | .495
CN2 | 1 | MINIB USB CONN, SMT | JISEN | JS-MU3-002 | JISEN | JS-MU3-002 | N | Y | 0.50
CN3 | 1 | DC POWER CONN, FOR 2.1 X 5.5MM | YQLXDZ | DS-0518 | YQLXDZ | DS-0518 | N | Y | 0.30
CN4 | 1 | CONN MOD JACK R/A 8P8C | MOLEX | 0441440003 | DIGIKEY | WM4595CT-ND | N | Y | 1.387
CN5, CN6, CN7, CN8, CN9, CN10 | 6 | 3.5mm STEREO, SWITCHED SMT CONN. | JISEN | ST-3509 | JISEN | ST-3509 | N | Y | 0.20
CN12 | 1 | CONN RECEPT 16POS 2MM GOLD DIP | HIROSE | A3C-16DA-2DSA(71) | DIGIKEY | H10897-ND | Y | Y | 1.638
D2 | 1 | DIODE SCHOTTKY 10V 3A SOD323 | STM | BAT60JFILM | DIGIKEY | 497-3707-1-ND | Y | Y | 0.240
FB1, FB2, FB3, FB4, FB5, FB6, FB7, FB8 | 8 | FERRITE 500MA 600 OHM 0805 SMD | lAIRD | HZ0805E601R-10 | DIGIKEY | 240-2399-1-ND | N | Y | 0.0381
J1, J3, J4 | 3 | CONN HEADER 2POS .100 VERT GOLD | MOLEX | 22-28-4023 | DIJIKEY | WM6502-ND | Y | Y | 0.190
L1 | 1 | INDUCTOR POWER 4.2UH 2.5A SMD | BOURNS | SRR5028-4R2Y | DIGIKEY | SRR5028-4R2YCT-ND | N | N | 0.456
LD2 | 1 | OPTOISOLATR 5KV TRANSISTOR 4-SMD | LITE-ON | LTV-817S-TA1 | DIGIKEY | 160-1893-1-ND | N | Y | 0.217
LED1, LED2 | 2 | LED SUPR RED CLR RT ANG 0805 | LITE-ON | LTST-S220KRKT | DIGIKEY | 160-1469-1-ND | Y | Y | 0.1151
LED3 | 1 | LED GREEN CLEAR RT ANG 0805 | LITE-ON | LTST-S220KGKT | DIGIKEY | 160-1468-1-ND | N | Y | 0.135
LED4 | 1 | LED YELLOW CLEAR RT ANG 0805 | LITE-ON | LTST-S220KSKT | DIGIKEY | 160-1470-1-ND | N | Y | 0.143
LED5, LED8 | 2 | LED 660NM SUPER RED DIFF 0603SMD | LUMEX | SML-LX0603SRW-TR | DIGIKEY | 67-1551-1-ND | Y | Y
MIC1 | 1 | MIC COND ANALOG OMNI -44DB | CUI | CMA-4544PF-W | DIGIKEY | 102-1721-ND | N | Y | 0.569
P1, P2, P3, P4, P5, P6, P7, P8, P9, P10, P11, P12, P13, P14, P16, P18, P19, P20 | 18 | TEST PAD, .050 | NA | NA | NA | NA | NA | NA | 0.0
PCB1 | 1
R1, R7, R8, R25, R34, R37, R43, R44, R45, R48 | 10 | RES 10.0K OHM 1/16W 1% 0402 SMD | VISHAY-DALE | CRCW040210K0FKED | DIGIKEY | 541-10.0KLCT-ND | Y | Y | 0.017
R2, R3, R4, R5 | 4 | RES 4.70K OHM 1/16W 1% 0402 SMD | VISHAY-DALE | CRCW04024K70FKED | DIGIKEY | 541-4.70KLCT-ND | Y | Y | 0.026
R6, R17 | 2 | RES 1.00K OHM 1/16W 1% 0402 SMD | VISHAY-DALE | CRCW04021K00FKED | DIGIKEY | 541-1.00KLCT-ND | Y | Y | 0.026
R9, R29 | 2 | RES 1.50K OHM 1/16W 1% 0402 SMD | VISHAY-DALE | CRCW04021K50FKED | DIGIKEY | 541-1.50KLCT-ND | Y | Y | 0.026
R10 | 1 | RES 47.0 OHM 1/10W 1% 0603 SMD | VISHAY-DALE | CRCW060347R0FKEA | DIGIKEY | 541-47.0HCT-ND | Y | Y | 0.025
R11, R32 | 2 | RES 100 OHM 1/10W 1% 0603 SMD | VISHAY | CRCW0603100RFKEA | DIGIKEY | 541-100HCT-ND | Y | Y | 0.030
R12, R13, R15, R16 | 4 | RES 680 OHM 1/16W 1% 0402 SMD | VISHAY-DALE | CRCW0402680RFKED | DIGIKEY | 541-680LCT-ND | Y | Y | 0.026
R14 | 1 | RES 220 OHM 1/16W 1% 0402 SMD | VISHAY-DALE | CRCW0402220RFKED | DIGIKEY | 541-220LCT-ND | Y | Y | 0.026
R18, R21, R26, R30, R31, R54, R55 | 7 | RES 0.0 OHM 1/10W JUMP 0603 SMD | VISHAY-DALE | CRCW06030000Z0EA | DIGIKEY | 541-0.0GCT-ND | Y | Y | 0.025
R19, R20 | 2 | RES 22.0 OHM 1/10W 1% 0603 SMD | VISHAY-DALE | CRCW060322R0FKEA | DIGIKEY | 541-22.0HCT-ND | Y | Y | 0.025
R22 | 1 | RES 22.1K OHM 1/10W 1% 0603 SMD | VISHAY-DALE | CRCW060322K1FKEA | DIGIKEY | 541-22.1KHCT-ND | Y | Y | 0.025
R23, R24 | 2 | RES 47.0K OHM 1/16W 1% 0402 SMD | VISHAY-DALE | CRCW040247K0FKED | DIGIKEY | 541-47.0KLCT-ND | Y | Y | 0.026
R27, R28 | 2 | RES 22.0 OHM 1/16W 1% 0402 SMD | VISHAY-DALE | CRCW040222R0FKED | DIGIKEY | 541-22.0LCT-ND | Y | Y | 0.026
R33, R38, R40, R41, R53, R56, R58 | 7 | RES 2.20K OHM 1/16W 1% 0402 SMD | VISHAY-DALE | CRCW04022K20FKED | DIGIKEY | 541-2.20KLCT-ND | Y | Y | 0.017
R35 | 1 | RES 124K OHM 1/16W 1% 0402 SMD | VISHAY-DALE | CRCW0402124KFKED | DIGIKEY | 541-124KLCT-ND | Y | Y | 0.044
R36 | 1 | RES 22.1K OHM 1/16W 1% 0402 SMD | VISHAY-DALE | 541-22.1KLCT-ND | DIGIKEY | 541-22.1KLCT-ND | Y | Y | 0.026
R39 | 1 | RES 4.70 OHM .5W 1% 1206 SMD | VISHAY DALE | CRCW12064R70FKEAHP | DIGIKEY | 541-4.70UCT-ND | Y | Y | 0.225
R42 | 1 | TRIMMER 500K OHM 0.5W SMD | BOURNS | 3361P-1-504GLF | DIGIKEY | 3361P-1-504GLFCT-ND | Y | Y | 0.969
R46 | 1 | POT 100K OHM 9MM SQ RTANG PLAST | BOURNS | 3310C-001-104L | DIGIKEY | 3310C-001-104L-ND | N | Y | 1.920
R47 | 1 | TRIMMER 500 OHM 0.5W SMD | BOURNS | 3361P-1-501GLF | DIGIKEY | 3361P-501GLFCT-ND | Y | Y | 0.969
R49 | 1 | RES 4.7 OHM 1/16W 5% 0402 SMD | VISHAY-DALE | 541-4.7JCT-ND | DIGIKEY | 541-4.7JCT-ND | Y | Y | 0.023
R50 | 1 | RES 10.0 OHM 1/10W 1% 0603 SMD | VISHAY-DALE | CRCW060310R0FKEA | DIGIKEY | 541-10.0HCT-ND | Y | Y | 0.025
R51 | 1 | RES 390 OHM 1/16W 1% 0402 SMD | VISHAY-DALE | CRCW0402390RFKED | DIGIKEY | 541-390LCT-ND | Y | Y | 0.044
R52 | 1 | TRIMMER 1K OHM 0.5W SMD | BOURNS | 3361P-1-102GLF | DIGIKEY | 3361P-102GLFCT-ND | Y | Y | 0.969
R57 | 1 | RES 470 OHM 1/16W 1% 0402 SMD | VISHAY-DALE | CRCW0402470RFKED | DIGIKEY | 541-470LCT-ND | Y | Y | 0.044
SH1, SH3 | 2 | SHUNT LP 2 POS SN | TYCO AMP | 1-382811-6 | DIGIKEY | A26231-ND | Y | Y | 0.210
SPKR1 | 1 | SPKR, 40mm,8Ohm | SHENZHEN HY ELECTRON | HY4004M-001 | SHENZHEN HY ELECTRON | HY4004M-001 | N | Y | 0.50
SW1 | 1 | SW, SPDT OFF-MOM PCB, SEALED | MULTICOMP | 8US8WR2C2M7RES | ELEMENT 14 | 8US8WR2C2M7RES | N | Y
SW2, SW4 | 2 | 4.5X4.5mm TACTILE SWIRCH RA TH | YQLXDZ | TS-026 | YQLXDZ | TS-026 | N | Y | 0.05
SW3 | 1 | SWITCH PUSH DPDT 0.1A 30V | E-SWITCH | PBH2UEENAGX | DIGIKEY | EG2655-ND | N | Y | 1.332
SW5 | 1 | 4.5X4.5mm TACT SWITCH SMT | YQLXDZ | TS-02B | YQLXDZ.COM | TS-02B | N | Y | 0.05
T1, T2 | 2 | TRANSF LINE MATCHING SMD | BOURNS | SM-LP-5001E | DIGIKEY | SM-LP-5001ECT-ND | N | Y | 1.506
U1 | 1 | IC MCU 32BIT 1MB FLASH 100LQFP | STM | STM32F405VGT6 | DIGIKEY | 497-11910-ND | N | Y | 9.364
U2 | 1 | IC REG LDO 3.3V 0.15A SOT23-5 | STM | LD3985M33R | DIGIKEY | 497-3504-1-ND | N | Y | 0.466
U3 | 1 | IC PWR SWITCH 1CH 500MA SOT23-5 | STM | STMPS2141STR | DIGIKEY | 497-6933-1-ND | N | Y | 0.480
U4 | 1 | I C EMI FILTR/ESD PROT 11FLIPCHIP | STM | EMIF02-USB03F2 | DIGIKEY | 497-13521-1-ND | N | Y | 0.525
U5 | 1 | IC REG BUCK SYNC ADJ 3A 8SOPWR | TI | TPS54329EDDAR | DIGIKEY | 296-29856-1-ND | N | Y | 1.650
U6, U7, U9 | 3 | IC OPAMP GP 1MHZ RRO SOT23- | TI | LMV341IDBVR | DIGIKEY | 296-17843-1-ND | N | Y | 0.556
U8 | 1 | IC AMP AUDIO PWR .325W AB 8SOIC | TI | LM386MX-1/NOPB | DIGIKEY | LM386MX-1/NOPBCT-ND | N | Y | 0.687
XTAL1 | 1 | CRYSTAL 8MHZ 20PF SMD | CTS | 405C35E08M00000 | DIGIKEY | 405C35E08M00000-ND | Y | Y | 0.550

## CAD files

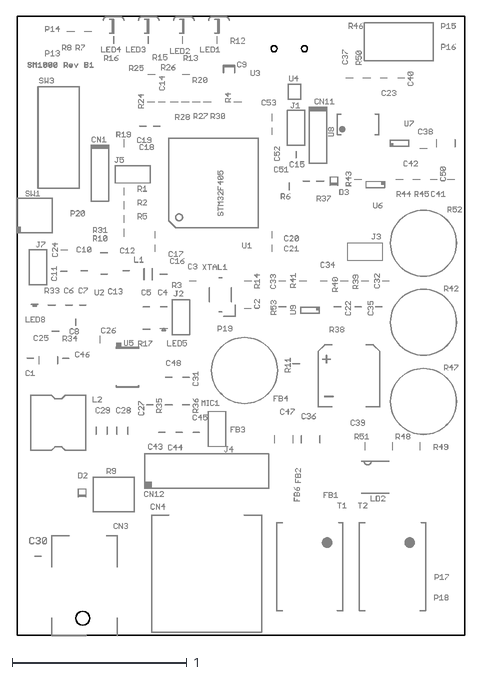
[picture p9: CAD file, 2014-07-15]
sm2000/SM1000-B/SM1000-REV-B1.dxf
2.57 x 3.55

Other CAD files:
sm2000/ENCL-SM1000-A/BOTTOM-ENCL-SM1000-A.DWG
sm2000/ENCL-SM1000-B/ENCL-SM1000-B-SIDE-PLATE.DWG
sm2000/ENCL-SM1000-C/ENCL-SM1000-C-SILKSCREEN.DWG
sm2000/ENCL-SM1000-C1/ENCL-SM1000-C1-BOTTOM.DWG
smartmic/ENCL-SM1000-A/TOP-ENCL-SM1000-A.DWG
smartmic/ENCL-SM1000-B/ENCL-SM1000-B-BOTTOM.DWG
smartmic/ENCL-SM1000-C/ENCL-SM1000-C-SILKSCREEN.DWG
smartmic/ENCL-SM1000-C1/ENCL-SM1000-C1-TOP.DWG
sm2000/ENCL-SM1000-A/SILKSCREN-ENCL-SM1000-A.DWG
sm2000/ENCL-SM1000-B/ENCL-SM1000-B-BOTTOM.DWG
sm2000/ENCL-SM1000-C/ENCL-SM1000-C-BOTTOM.DWG
sm2000/ENCL-SM1000-C1/ENCL-SM1000-C1-SILKSCREEN.DWG
smartmic/ENCL-SM1000-A/SILKSCREN-ENCL-SM1000-A.DWG
smartmic/ENCL-SM1000-B/ENCL-SM1000-B-SIDE-PLATE.DWG
smartmic/ENCL-SM1000-C/ENCL-SM1000-C-SIDE-PLATE.DWG
smartmic/ENCL-SM1000-C1/ENCL-SM1000-C1-SIDE-PLATE.DWG
sm2000/ENCL-SM1000-A/TOP-ENCL-SM1000-A.DWG
sm2000/ENCL-SM1000-B/ENCL-SM1000-B-SILKSCREEN.DWG
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

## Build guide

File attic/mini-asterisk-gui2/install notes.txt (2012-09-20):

IP04 GUI2 Install notes
Ian Roberts 
Sept 2012

0. Connect ip04 to network. Power up.

1. Telnet 192.168.1.30

2. Create a file

   vi install_gui2.sh

3. Copy script from
   http://freetel.svn.sourceforge.net/viewvc/freetel/mini-asterisk-gui2/install_gui2.sh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
   
   Paste into vi session (right click will do it)
   Save file
   
4. Make the script executable

   chmod a+x install_gui2.sh

5. Run the script

   sh install_gui2.sh

6. Check gui2 

   192.168.1.30/gui2/phones.html

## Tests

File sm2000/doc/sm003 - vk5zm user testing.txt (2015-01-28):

Testing SM1000 OTA at Matt's House 28 Jan 2015
----------------------------------------------

  + First SM1000 OTA SM1000 QSO between VK5AKH (Andy) and VK5ZM (Matt) at 
    Matt's QTH.  Matt connected the SM1000 to his IC706. 2130 SA time

  0. Connected up patch panel, used rig mic, ptt, rig spkr through RJ45.
     spkr and ptt had common ground which required and extra grnd jumper.
     Matt " for fat fingers rather fiddly".  Would be good to doucment this
     for common radios.
  1. While monitoring with FT817 found similar slope on spectrum/scatter 
     diagram to IC7200
      + HF modem tones around 2000 Hz attenutaed by several dB
      + get to the bottom of tx slope, say with test signal
  2.  Andy sounded a bit distorted on rx
      + Backed off his mic level and was better
  3. Matt lugged in a Heil headset, had to reduce mic gain, clipping led
     was very useful.  No noise issues.  Mic gain trimmer was a little too
     sensitive.  Suggest multiturn trimmer.
  4. Analog mode works OK once mic gain adjusted.  Tip: do mic level adj
     in analog mode, then dig should be OK.  
  5. Switching an to dig worked OK, levels OK.
  6. AF gain of IC720 was slaved to the AF out in RJ45.  So trap is turning
     down AF gain stopped FreeDV, turning up led to clipping.
  7. Secondary use is analog processing.  Move sliders to adf filters, 
     look at audio spectra with white noise or chirp, monitor on 2nd radio.

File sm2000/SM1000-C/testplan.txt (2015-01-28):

Test Plan for Rev C SM1000
David Rowe 15/12/14

[X] 5V and 3V3 rails OK
[X] 1.24V across C14 and C15
    + on chip regulator working
[X] Goes into USB DFU mode when PTT held down on power on/reset
    + STM32F4 BOOTLOADER device appears on Host PC USB port
    + note plug USB Cable in after power up, otherwise Host PC will
      supply power and prevent power cycle.
[X] Flash dac_ut.bin using USB on Linux:
    $ sudo apt-get install dfu-util
    $ sudo dfu-util -d 0483:df11 -c 1 -i 0 -a 0 -s 0x08000000 -D dac_ut.bin
    + if this works it will run for about 6 seconds then stop, you don't
      get a sucess message   
    + power cycle/reset 
[X] dac_ut works
    [X] several volts PP audio freq sine wave on test points P2/P3
    [X] loud sine wave from speaker or headphones

[X] 2.74V across MIC1
[X] speak into mic, or tap board, sould be a few Vpp
    + mic gain R42 roughly in the middle of travel

Useful Command Lines
--------------------

Receiving freedv waveform from SM1000 via mic input on laptop and decode to wave file:

$ cd codec2-dev/build/src
$ rec -r 8000 -s -2 -c 1 -t raw - trim 0 10 | ./freedv_rx - - | sox -t raw -r 8000 -s -2 - ~/Desktop/sm1000_beta_dv.wav

TODO
----

[ ] adcdac_ut works
    + plays sine wave until S2 pressed
    + then mic signal echoes to speaker (wtahcout for howling feedback)

TODO:
(need more detail, pass/fail conditions)

[ ] set up procedure to get levels right/minimise distortion on TX
[ ] unit test for buttons and leds
[ ] test device in analog mode OTA
    + two radios
[ ] test device in DV mode from modem files on a PC
[ ] test device in digital mode OTA
[ ] test patch panel 
[ ] test each connector can be reached by cables
[ ] Test PTT control of radio works
[ ] noise tests
[ ] test external mic
[ ] test external speaker/headphones
[ ] Get another experienced Ham to try it
    + watch them and refine install procedure
[ ] Speaker volume in a moving car

Software TODO

[ ] Switch sign changed
[ ] Way to insert callsign, like USB serial "monitor"
[ ] way to relate firmware to SVN rev

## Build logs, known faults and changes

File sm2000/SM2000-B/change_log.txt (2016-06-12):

[ ] DR Place C7 much closer to U1. Similar distance to C6 p22.  Maybe
    move C6 and C7 closer if possible. Reduce total area of loop
    through which power supply currents must flow.

[ ] DR swap postions of C1 and C2, C3 and C5, C8 and C9. 10n closer to
    U1 than 100n as smaller cap deals with higher freq currents.  C14
    & C15 OK.

[ ] DR C22 4.7uF footprint small for the tant I hand loaded.  Pls make
    larger.

[ ] DR C114 overlay rotate 180 deg

[ ] DR Indication on overlay on pin 1 of XTAL1 and XTAL2. Two of the
    pins on xtals are connected together (ground pins), I worked out
    orientation using a multimeter.

[ ] DR hole size on all (3 pin, 4 pin, etc) 0.1 inch headers too
    small.  Had to solder headers on top.

[ ] DR On schematic only suggest move R28 and R29 to SCL3/SDA3 nodes
    near U1.  This is not a netlist change, just move on schematic to
    highlight these parts are pullups for entire I2C bus and not just
    U4 which is unlikely to be used.  TBH U4 can be removed.  We have
    internal non volatile storage in U1 and drivers to use it.

[ ] DR XTAL1 and XTAL2 footprints too small, OK for machine assembly
    but too small for hand assembly.  Larger pads please that extend
    beyond the perimiter of the the xtal.

[ ] DR - question to Neil re USB D+ D- differential pair routing
    across PCB, e.g. do they need to be the same length, how close
    together.  Distance from USB connector on SM2000 is several
    inches.  Much closer on SM1000.

[ ] DR - should +12VTXENB/+12VRXENB have pull down R's so that on
    reset they are not floating and +12V rx/tx supply lines are
    disabled?

[ ] DR - change notes above and below L2/L3.  Currently refer to
    L8/L9, should be L2/L3.

[ ] DR - connect p3 of J6 to ground

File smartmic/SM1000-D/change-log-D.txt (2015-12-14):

1. Change labels on top overlay near trimmers
   
[X] SPKR IN -> RIG SPKR
   
[X] EXT MIC -> MIC GAIN
   
[X] Remove INT MIC label (it's not associated with a trimmer)
		
INT MIC  Identifies internal microphone. Will move to remove confusion. RGB 12/30/14

2.  [X] Change LED8 to LTST-S2200K. Will correct wrong footprint proble.

3.  [X] Investigate moving USB connector forward so that it extends trhu the rear panel. 
        If it extends thru pane, we can change panel cutout back to smaller opening and not block LEDs.

4.  [X] TS-26 switch footprint is mirrored front to back. Fix footprint.
		Footprint corrected, PCB will be updated for D REV. RGB 12/30/14

5. 	[X] Edwin accidentally loaded D1 (optional DNL zener) which caused 5V switcher to develop just 3.84V.
		DNL Inform Edwin, Change BOM
6. 	[X] Change U1 to STM32F405
		Use 407's purchased, use 405's after that. Inform Edwin.
		
7. 	[X] Can't fit PCB into enclosure bottom with R46 volume control fitted.
		Edwin didn't use Bourns POTs. Order Bourns & inform Edwin.
		
8. 	[X] Not sure about tactile feel/quality of trim pots.  They seem to have varying tension/stifness and I can't seat a screwdriver properly in R52.  I can rotate mic gain pot all the way around.
        + Action change to Bourns 3361 trimport
        [X] BOM changed
        [X] Edwin informed (maybe via new BOM)

9. 	[ ] Why are parts designators on overlay missing?  Rubbed off with cleaning?
		Handle offline with Edwin.

10. [X] Assembly instruction: J3 needs to be loaded and jumper inserted
		Schematics changed to show jumper positions.

11. [X] Microphone pins are swapped, ie rotate by 180 degrees.
		Footprint changed to correct problem. Implemented in REV D PCB.
		
12. [O] Should R46 be log?  Last half of travel makes very little difference to subjective volume.
		Defer decision til later.
		
13. [O]	With bud type headphones, a low volume leve is reqd.  At these
		levels some low freq noises at the frame rate and HF hiss can be
		heard.  As these noises are still heard with zero volume its
		probably noise from U8.  Might need soem HP/LP filtering.  Thru
		loudspeaker fine.  Amount of noise varies with headphones used. As
		volume is hard to regulate perhaps another option si a series
		resistor with the headphone jack.
		Defer until more testing done.

14. [O] Decide if power supply and USB programming cable should be included in BOM.
		Defer decision.
		
15. [O] Artwork (i.e. a coloured sleeve) for the box?  Price?  Who can design artwork?
        + add good looking images of board
		Defer action.

16. [X] Change C33 from 100nF to 220nF, to bring HPF corner frequency down.
		Implemented REV D.
		
17. [X] Change Mic1 to Digikey part rather than generic subsitute
    + Generic part resulted in "tinny" audio
    + Digikey part fixed audio, sounded similar to Yaseu MH31
		Mic OK, No Change.
		
18. [X] Confirm on/off power switch parts used is loose sample Edwin packed with the Qty 2 prototypes.
		Switch not used. Stay with currrent switch.
		
19. [X] Choose and order new PTT switch
		Selected Multicomp 8US8WR2C2M7RES for PTT.
		
20. [X] Should we DNL two power leds that aren't exposed via enclosure?
		Use parts Edwin has for currrent build. DNL for future production.
		
21. [X] Confirm with pot part Edwin R46 part used
		Bourns POTs ordered.
22. [ ] Confirm PTT and power switch have buttons (if rqd) and R46 pot has knob on BOM

23. [X] Round or square hole for power switch? 
		Power switch cap or button - use round part Edwin supplied with prototypes.
		
24. [ ] Communciate to Edwin 
        [X] DNL power LEDs
        [ ] knob for Bourns pot, round shaft with set screw
			TODO
        [X] round cap for power switch
        [X] Bourns trimmers
        [X] J3 and jumper loaded

Further Work
------------

1. [ ] Should R46 be log?  Last half of travel makes very little difference to subjective volume.
2. [ ] Item 13 above, noise from LM386
3. [ ] Wiki with common pin outs of CN12
   [ ] label schematic near CN12 to make working out nets easier    
   [ ] examples of how to connect grounds when AF out is on RJ45
   [ ] Matt " for fat fingers rather fiddly"
       + can we make it larger?    
   [ ] labels near R52, R47, R42, R46 on sch that match overlay and enclosure

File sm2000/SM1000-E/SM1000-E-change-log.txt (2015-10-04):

SM1000-E-CHANGE-LOG.TXT
03/30/15 RGB

1.  [X]	R	Change PTT sw. to e-switch LC2259OANP.

2.  [X]	R	Change POWER SW to e-switch LC2259EENP.
	
3.  [X]	R+E	Change SPKR CONN J4 to CONN-BOOM-XH-2A.
	*****	Edwin needs to add mating connector to speaker assembly.

4.  [X]	R	Added part outlines to layer tDocu for documentation.
		All pars have outline on tplace layer.

5.  [X]	R	Problem with SPKR OUT conn. Shorts output when stereo jack used.
		+ as per Josh Mesaline email, suggest resistors to tip and ring
		so a short doesn't upset amp.  Does this mean it will work with
		mono and stereo plugs?  If stereo only we should note this in UG.
	*****	Add jmpr to ring terminal to provide ormally open circuit. Shunt must be
		provided but only on 1 pin. Customer will place across both jmpr pins for 
		use with stereo speaker/headphones.

6.  [ ]	R	TrimPOT holes, location off by 1mm.

7.  [X]	R	U1, CPU pins extend to the end of the pads.
				Corrected RGB

8.  [ ]	R+E	Land pattern for LEDs too large. I will look into this. RGB
	*****	Land pattern size recommended by vendor. If too large, need suggested pad size from Edwin.

9.  [X]	R	SW5 land pattern too wide. Check specification.
				Corrected package RGB

10. [X]	R	C32, C59 footprint too short.
		corrected package  RGB

11. [X]	R	L1 Land pattern too wide.
		Corrected package  RGB

12  [X]	R+E	CN4 Bubble after SMT(high temperature)
		No action yet. Edwin, can you find an alternative to fit? If different footprint, let me know and send specification so
		Edwin reports other vendors parts do same. Action? RGB
	*****	No Action at this time

13. [X]	E	R46 Easy to break R46 with handling.
		Add cement after production.
	*****	Note, I accidently hit and moved pot removing PCB from case. 
		Suggest applying cement prior to soldering RGB

14. [X]	E	PCB Problem reflowing CN10 USB connector.
		Make Breakaway 10mm (Edwin)
	*****	Vendor problem. RGB

15  [X]	E	PCB Stencil too small.
		Make Stencil 52 x 52 cm(Edwin)
	*****	Vendor problem. RGB
	
16  [ ] D	Firmware   Better debouncing software for push button switches (DR)	
		could be: more solid indication of in DV mode, like two beeps, two flashes

17  [ ] R	Enclosure  Move "Speaker Volume" text lower to clear volume control knob

18  [ ] E	Enclosure  Some variablility in gap between lid and front panel, gap is
                sometimes wider on one side than another (Edwin)

19  [X] R	PCB change power led from red to green, clip/error led from amber to red? 
		LED1	GRN, LED2	RED, LED3	GRN, LED4	RED
	*****	DO we need new LED packages?

20  [ ] R+D  	Mel reported ESD events at Dayton causing SM1000 to crash.
		"Gerry and I did notice one thing... the SM1000 appears to be a little
            	sensitive to ESD events caused by "walking across the carpet in tennis
            	shoes in the booth and then touching the SM1000."  It would stop
            	working and require toggling power, however it always came back
            	working ok."
	*****	Will add pads for TVS device across DC power connector & 6 X 3.5mm connectors.
		DNL status TBD. RGB	

21  [X] R    	Mel: DNL LED5 and LED8 to save a little power.
	*****	DNL LED8, DNL R33, DNL LED5, DNL R17

22  [X] R    	Mel: Is R42 wired backwards? Higher output CCW vs CW?
		Mirrored part, corrected problem. RGB

23  [X] R   	Mel: Silk screen pin numbers on.  Can e make CN12 larger for older Hams?
	*****	Added pin nos for 1,8,9,16	RGB

24  [ ]  D+E   	Mel: green led too bright, increase R15 to 1500 ohms
	*****	WE should try this on all LEDs and evaluate. RGB

25  [ ] NA    	Mel: different colour case options

26  [ ] D    	Mel: PTT being pulsed low on power up.

27  [X] R+D    	Peter VK5APR, DC input connector hole offset down wrt to
            	enclosure on his unit.  Is this true on any other
            	samples, or maybe a 1 off?  RJ45 aperture in enclosure
            	also slightly offset to left.			
	*****	RJ45 and Power connectors are almost perfectly aligned on the units I have.
		Perhaps a problem when PCBs are assembled into case?   RGB
		No Action

28  [ ] D	firmware   Check analog speech level in digital mode.

29. [ ]	R	Change enclosure side plate for new PTT switch siize & location.

30  [ ]	R	Add shunt for #5 above to BOM

31  [ ]	R	Add TVS diodes to 3,5mm connectors & DC power Connector

06/26/2015   RGB

32  [X] R	Fix problems with CN8 and Mono plug problems.
		Changed J2 & J4 connections to work with stereo or mono plugs and protect U8.

33  [X] R	Change drill & pad diameter od pad 7 of switch LC-2259 to 1.6mm & 2.54mm respectively to accomodate switch with larger tabs.
		Library & .brd updated. RGB

Rev F Ideas
-----------

[ ] jumper with series R for mic gain
[ ] consider combining grounds on patch panel as they usually are
[ ] do all gain pots increase gain when turned CW
[ ] mic gain is wront way around
[ ] increasing arrow on trimmer pot case overlay showing increase direction
[ ] http://rfhead.net/?p=582
[ ] larger patch panel?
[ ] 0805 R48 gain resistors?

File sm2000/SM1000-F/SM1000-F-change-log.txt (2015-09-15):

SM1000-E-CHANGE-LOG.TXT
09/15/15 RGB

1.  [X]	R	Change PTT sw. to e-switch LC2259OANP.

2.  [X]	R	Change POWER SW to e-switch LC2259EENP.
	
3.  [X]	R+E	Change SPKR CONN J4 to CONN-BOOM-XH-2A.
	*****	Edwin needs to add mating connector to speaker assembly.

4.  [X]	R	Added part outlines to layer tDocu for documentation.
		All pars have outline on tplace layer.

5.  [X]	R	Problem with SPKR OUT conn. Shorts output when stereo jack used.
		+ as per Josh Mesaline email, suggest resistors to tip and ring
		so a short doesn't upset amp.  Does this mean it will work with
		mono and stereo plugs?  If stereo only we should note this in UG.
	*****	Add jmpr to ring terminal to provide ormally open circuit. Shunt must be
		provided but only on 1 pin. Customer will place across both jmpr pins for 
		use with stereo speaker/headphones.

6.  [ ]	R	TrimPOT holes, location off by 1mm.

7.  [X]	R	U1, CPU pins extend to the end of the pads.
				Corrected RGB

8.  [ ]	R+E	Land pattern for LEDs too large. I will look into this. RGB
	*****	Land pattern size recommended by vendor. If too large, need suggested pad size from Edwin.

9.  [X]	R	SW5 land pattern too wide. Check specification.
				Corrected package RGB

10. [X]	R	C32, C59 footprint too short.
		corrected package  RGB

11. [X]	R	L1 Land pattern too wide.
		Corrected package  RGB

12  [X]	R+E	CN4 Bubble after SMT(high temperature)
		No action yet. Edwin, can you find an alternative to fit? If different footprint, let me know and send specification so
		Edwin reports other vendors parts do same. Action? RGB
	*****	No Action at this time

13. [X]	E	R46 Easy to break R46 with handling.
		Add cement after production.
	*****	Note, I accidently hit and moved pot removing PCB from case. 
		Suggest applying cement prior to soldering RGB

14. [X]	E	PCB Problem reflowing CN10 USB connector.
		Make Breakaway 10mm (Edwin)
	*****	Vendor problem. RGB

15  [X]	E	PCB Stencil too small.
		Make Stencil 52 x 52 cm(Edwin)
	*****	Vendor problem. RGB
	
16  [ ] D	Firmware   Better debouncing software for push button switches (DR)	
		could be: more solid indication of in DV mode, like two beeps, two flashes

17  [ ] R	Enclosure  Move "Speaker Volume" text lower to clear volume control knob

18  [ ] E	Enclosure  Some variablility in gap between lid and front panel, gap is
                sometimes wider on one side than another (Edwin)

19  [X] R	PCB change power led from red to green, clip/error led from amber to red? 
		LED1	GRN, LED2	RED, LED3	GRN, LED4	RED
	*****	DO we need new LED packages?

20  [ ] R+D  	Mel reported ESD events at Dayton causing SM1000 to crash.
		"Gerry and I did notice one thing... the SM1000 appears to be a little
            	sensitive to ESD events caused by "walking across the carpet in tennis
            	shoes in the booth and then touching the SM1000."  It would stop
            	working and require toggling power, however it always came back
            	working ok."
	*****	Will add pads for TVS device across DC power connector & 6 X 3.5mm connectors.
		DNL status TBD. RGB	

21  [X] R    	Mel: DNL LED5 and LED8 to save a little power.
	*****	DNL LED8, DNL R33, DNL LED5, DNL R17

22  [X] R    	Mel: Is R42 wired backwards? Higher output CCW vs CW?
		Mirrored part, corrected problem. RGB

23  [X] R   	Mel: Silk screen pin numbers on.  Can e make CN12 larger for older Hams?
	*****	Added pin nos for 1,8,9,16	RGB

24  [ ]  D+E   	Mel: green led too bright, increase R15 to 1500 ohms
	*****	WE should try this on all LEDs and evaluate. RGB

25  [ ] NA    	Mel: different colour case options

26  [ ] D    	Mel: PTT being pulsed low on power up.

27  [X] R+D    	Peter VK5APR, DC input connector hole offset down wrt to
            	enclosure on his unit.  Is this true on any other
            	samples, or maybe a 1 off?  RJ45 aperture in enclosure
            	also slightly offset to left.			
	*****	RJ45 and Power connectors are almost perfectly aligned on the units I have.
		Perhaps a problem when PCBs are assembled into case?   RGB
		No Action

28  [ ] D	firmware   Check analog speech level in digital mode.

29. [ ]	R	Change enclosure side plate for new PTT switch siize & location.

30  [ ]	R	Add shunt for #5 above to BOM

31  [ ]	R	Add TVS diodes to 3,5mm connectors & DC power Connector

06/26/2015   RGB

32  [X] R	Fix problems with CN8 and Mono plug problems.
		Changed J2 & J4 connections to work with stereo or mono plugs and protect U8.

33  [X] R	Change drill & pad diameter od pad 7 of switch LC-2259 to 1.6mm & 2.54mm respectively to accomodate switch with larger tabs.
		Library & .brd updated. RGB

Rev F Changes
-----------

34 [X] jumper with series R for mic gain
          Will add jmpr and 1/4W 330 Ohm res in parallel with R48.

35 [X] consider combining grounds on patch panel as they usually are
          Will disconnect CN13-12 from RF-MIC(MIC_GND) and connect to CN12-13 RF_PTT(PTT_GND). More flexibility.

36 [X] do all gain pots increase gain when turned CW. 
          Mic GAin reversed fixed in 37 below.

37 [X] mic gain is wront way around. 
          Switched ends of POT to fix direction, increaasing CW.

38 [X] increasing arrow on trimmer pot case overlay showing increase direction
          Edwin will arrange with enclosure manufacturer.

39 [X] http://rfhead.net/?p=582
          Will add pads to implement this. Will be User change & responsibility.

40 [X] larger patch panel?
	  Replacing CN12 with 16pin DIL turret post socket.

41 [X] 0805 R48 gain resistors?
	replace R48 package with 1206 package.

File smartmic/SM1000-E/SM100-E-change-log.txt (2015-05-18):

SM1000-E-CHANGE-LOG.TXT
03/30/15 RGB

1.  [X]	Change PTT sw. to e-switch LC2259OANP.

2.  [X]	Change POWER SW to e-switch LC2259EENP.
	
3.  [X]	Change SPKR CONN J4 to CONN-BOOM-XH-2A.

4.  [ ]	Added part outlines to layer tDocu for documentation.

   	In progress, adding to outlines in time.

05/18/15

5.  [ ]	Problem with SPKR OUT conn. Shorts output when stereo jack used.

6.  [ ]	TrimPOT holes, location off by 1mm.

7.  [X]	U1, CPU pins extend to the end of the pads.

		Corrected RGB

8.  [X]	Lad pattern for LEDs too large. I will look into this. RGB

		No action todate.

9.  [X]	SW5 land pattern too wide. Check specification.

		Corrected footprint RGB

10. [X]	C32, C59 footprint too short.

		corrected  RGB

11. [X]	L1 Land pattern too wide.

		Corrected RGB

12  [ ]	CN4	Bubble after SMT(high temperature)

		No action yet. Edwin, can you find an alternative to fit? If different footprint, let me know and send specification so
		I can change it.(RGB)

13. [X]	R46	Easy to break R46 with handling.

		Add cement after production.

14. [ ]	PCB	Problem reflowing CN10 USB connector.
		
		Make Breakaway 10mm (Edwin)

15  [ ]	PCB	Stencil too small.
		
		MAke Stencil 52 x 52 cm(Edwin)

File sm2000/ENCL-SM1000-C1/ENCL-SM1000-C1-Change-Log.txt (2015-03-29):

ENCL-SM1000-C1-Change-Log.txt
Changes to ENCL-SM1000-C

1.  (TOP COVER)Change width of Top Cover ENCL-SM1000-C from 68.20mm to 68.70mm. Note: Overall width of front panel must change correspondingly  by .5mmas well.
 
2.  (TOP COVER)Trimmer POT hole (MIC GAIN) X dimension must increase from 31.25mm to 31.85mm.

3.  (TOP COVER)Trimmer POT hole (RIG SPKR) X dimension must change from 40.26 mm to 40.86mm.

4.  (TOP COVER)Trimmer POT hole (RIG MIC)  X dimension ust change from 50.25mm to 50.85mm.

5.  (BOTTOM BASE)Top View - 2.2mm D  4 dimension must change to 1.8mm D X 4. Change to accommodate a 2.2mm self tapping screw.

6.  BOTTOM BASE) front view, 54.30mm - 78.75mm X 0.85mm notch must be included to accommodate SIDE PLATE. 

7   (TOP COVER) front panel view, X dimension to center of 6.0mm D holes missing, should be 20.90mm.

8.  (TOP COVER) front panel view, X dimension to center of RJ45 connector hole missing, should be 11.76mm.

9.  (TOP COVER) front panel view, X dimension to center of 7.8mm D hole missing, should be 10.26mm.

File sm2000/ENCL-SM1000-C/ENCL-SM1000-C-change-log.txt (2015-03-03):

ENCL-SM1000-C-change-log.txt
Created 02/24/15
==========================================================
1.	Numerous dimensions changed. Changed origin points to ensure fit between enclosure
	bottom and top. Dimension changes are for most part are sub millimetre. Will attempt 
	to mark up .PDFs to show dimension changes between Rev B & Rev C 
	
2.	Need to determine thichness of powder coat finish to ensure proper fit between 
	enclosure parts.
	
3.	Modified enclosure panels to allow for silk screen operations without smearing.

4.  cHANGED spkr volume TO SINGLE LINE TO FIT.

5. Changed REAR panel logo to fit.

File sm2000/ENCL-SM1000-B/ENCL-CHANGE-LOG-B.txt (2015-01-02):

CHANGE LOG ENCL-B
rgb 01/01/2014

1.	[ ]	Change metal thickness to 22GA (.85mm/.0336") for top & bottom enclosure parts. - RGB
2.	[ ] Move rear panel(USB, POT, LEDs, etc) to top (cover) to allow top & bottom pieces to slide into position. 
3.	[ ]	Add tab to left side to act as user surface for PTT SW & EXT PTT conn.
4.	[ ] Add cutout (slot) in cover, left side to allow cover to slide into place over PTT SW & EXT PTT conn.

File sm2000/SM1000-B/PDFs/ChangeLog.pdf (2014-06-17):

1. Change U5 TPS54329E to RT8250
2. Move LED8 to 5V
3. Change rig mic amp circuit to pot on transformer output. 4. Change mic preamp circuit to op-amp per DR. 5. Add ext. PTT connector and cpu DI. 6. Bring GND, RF(GND) & +VEXT to IC1 connector. 7. Change PCB from 4 layer to 2 layer. 8. Change processor from STM32F407 to STM32F405. 9. Change bypass caps to mix of 100nF and 10nF. 10. Add hdr for speaker. 11. Change C43, C44, C45 to 100pF
12. Change C23 to 25V. 13 Added PTT SW network to permit DFU mode on power up. 05/28/2014
14. Change Reset switch to header. 15. Power electret mic from VDD
16. Change CN1 to 3-pin

05/29/2014

17. Change SCL, SDA pulldowns to pullups.

06/01/2014

18. Delete STLINK LED & components. 19. Delete USB fault LED & circuitry. 20. Delete VUSB Led & circuitry. 21. Add SELECT & BACK switches. 06/02/2014
22. Change 0603 resistors to IPC packages & symbols. 06/05/2014
23. Change 0603 caps to IPC packages & symbols.

06/12/2014

24. Change D3 to BAT60
25. Change SW3 back to PBH2UUENAGX
26. Remove signals from pins 9 & 10 CN12. 27. Change C10 & C12 to Ceramic 0603 caps. 28. Change C8 to 10nF. 29. Change R12, R13, R15, R16 & R17 to 680 Ohms. 30. Change R1, R7 & R8 to 10K
31. Correct pinout for LD3985. 32. Change C2 & C3 to 20pF. 33. Change C27 to 22pF. 34. Change C40 to 25V. 35. Move Pot R52 to T1 output & change to 1K. 36. Change C39 to 220uF,25V

06/15/2014
37. Change GND on CN12-12,13 to RF
38. Add test points at pins 77,78,79,80. PA15,PC10,PC11,PC12
39. Add test points at pins 97,98,1,2. PE0,PE1,PE2,PE3
40. Add test points at pins 24,25,29,30. AIN1,AIN2,DAC1,DAC2
41. Add test points P14,P16,P18 (GND). 42. Add test points P13,p15,p17 (VDD). 43. Add test point P19 (+5V). 40. Add test point P20 (+VIN ). 06/16/2014

# Change Log for SM1000 PCB

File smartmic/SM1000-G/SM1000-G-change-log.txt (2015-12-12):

SM1000 Rev G Change Log

[ ] Add large txt silk screen lables to STLINK CN1 to help people
    connecting to it

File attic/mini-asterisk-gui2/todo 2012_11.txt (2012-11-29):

IP04 GUI2 To do notes
Ian Roberts 

*************************************************************************

Nov 16 2012

Dave added new cgis to use perl instead of sed.
	- sed is broken under busybox 1.4.1
	- perl is working fine.
    - comment.cgi
	- uncomment.cgi
	- setlinekey2.cgi

voip provider page

  Test sip
     - registering successfully with another asterisk box (use host=dynamic)
	 - out bound calls ?
	 - inbound calls ?
  
  Test jazmin
	- do we get a successful registration ?
		fails with none dropbox set ... read in current registration
		fails with mulit changes...leave voip keyword intact (Done)
		
	- can we make outbound voip calls ?
	- are inbound voip calls working ?

(Maybe add in voip line 2 page... later)
  
*****************************************************************************  

 Nov 29 2012
 
 voip line (sip trunk) page is now working.
	- reads settings from sip.conf 
	- there are four options for sip trunk... none, sip, sip with nat, and provider
	- you can change user, password, host, fromuser, and fromdomain
	- these changes get saved back into sip.conf when you press the ok
 
 testing
    - sip		registers	ok
				outbound	ok
				inbound		not tested yet

    - sipnat	registers	not tested yet
				outbound	not tested yet
				inbound		not tested yet

    - provider	registers	ok      voip.oeg.com.au
				outbound	ok      (adelaide ok, wgong fails)
				inbound		not tested yet

	- none		clears rego	ok

*************************************************************************************

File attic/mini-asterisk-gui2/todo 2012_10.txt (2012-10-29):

IP04 GUI2 To do notes
Ian Roberts 

*************************************************************************

Oct 1 2012

network page
  
  Test static to dhcp selection
  
  dhcp   if cant reference objects (radio) directly...use getElementById()
         dhcp get 1.30 if possible?
		 
  gateway :fping does not time out when internet down
  
  add in emergency ip code

phones page

  debug reception errors with 1fxo, 1fxs in zaptel.conf
  
new config page 

  impedance select US or AU
  ntp select region
 
new login page
  makes a cookie based on 

*****************************************************************************  
  
Oct 18 2012

Phones page

	Reception update fail : 
		Daisy chain url calls
		Fix asterisk cgi prefix .... cli=dial plan

	internet fping 8.8.8.8
  
Network page
  
	Bad dns .... Try fping 8.8.8.8 instead?
	....try fping dns check before internet fping
	.... maybe nslookup 
		 fping 8.8.8.8 ?

	two crosses dns and internet?

	fping dns
	if ok fping google
	else fail report
	
[  Dialplan outbound g1/g2 ?   ]

IP provider page

Login page

*************************************************************************************

Oct 29 2012

IP provider page work
	sip.conf modified with new keywords
	install script changed to update sip.conf
	Are sip provider entries ok to leav uncommented?...they have dummy hosts
	
Notice ip phone (ekiga from pc) registrations stay on ip04 after phone has disappeared

Error on Fxo/FXS rearrangement  phones lines read as phone

Register command needs to be unique

SetRegister.cgi   ?  with mini-asterisk

	$ cat test.txt | sed 's/\(register=>\).*\( ; mini-asterisk\)/\1bob:superbob@192.168.1.3\2/'
	register=>bob:superbob@192.168.1.3 ; mini-asterisk yada yada
	;register => 2345:password@sip_proxy/1234

Register needs to be able to handle other manual register entries

Or make a mod to set_line_ext.cgi with third arg (jazmin,sip,sip-nat)

Uncomment / comment sip provider as a cgi?

								s/$this.*/$this$that/g
[11:09:09 AM | Edited 11:10:06 AM] David Rowe:  s/(host=).*\w/$1trev/g
[11:10:13 AM] David Rowe: host=mal
[11:10:16 AM] David Rowe: host=trev

hex codes as uniques?  hard to remember

$ cat test.txt | sed 's/\(host=\)[a-z]*\(.*sip mini-asterisk.*\)/\1trev\2/'
host=fred ; jazmin mini-asterisk
host=trev ; sip mini-asterisk

$ cat test.txt | sed 's/\(dtmfmod=\)[a-z0-9\.]*\(.*Jazmin mini-asterisk.*\)/\1trev\2/'
host=192.168.1.28       ; Jazmin mini-asterisk do not remove this comment
dtmfmod=trev         ; Jazmin mini-asterisk do not remove this comment

debugging
#!/bin/sh
[12:05:07 PM] David Rowe: #!/bin/sh -x
[12:05:16 PM] David Rowe:   sed -i "s/$this.*/$this$that/g" $file

export QUERY_STRING='file=test.txt&this=host=&that=192.168.1.31&key=Jazmin mini'; ./setlinekey.cgi

We are getting problems with sed (busybox version) regular expressions on the ip04. We are losing /1 /2 entities.

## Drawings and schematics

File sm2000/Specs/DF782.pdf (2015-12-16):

Case Style | DF

## PCB Land Pattern

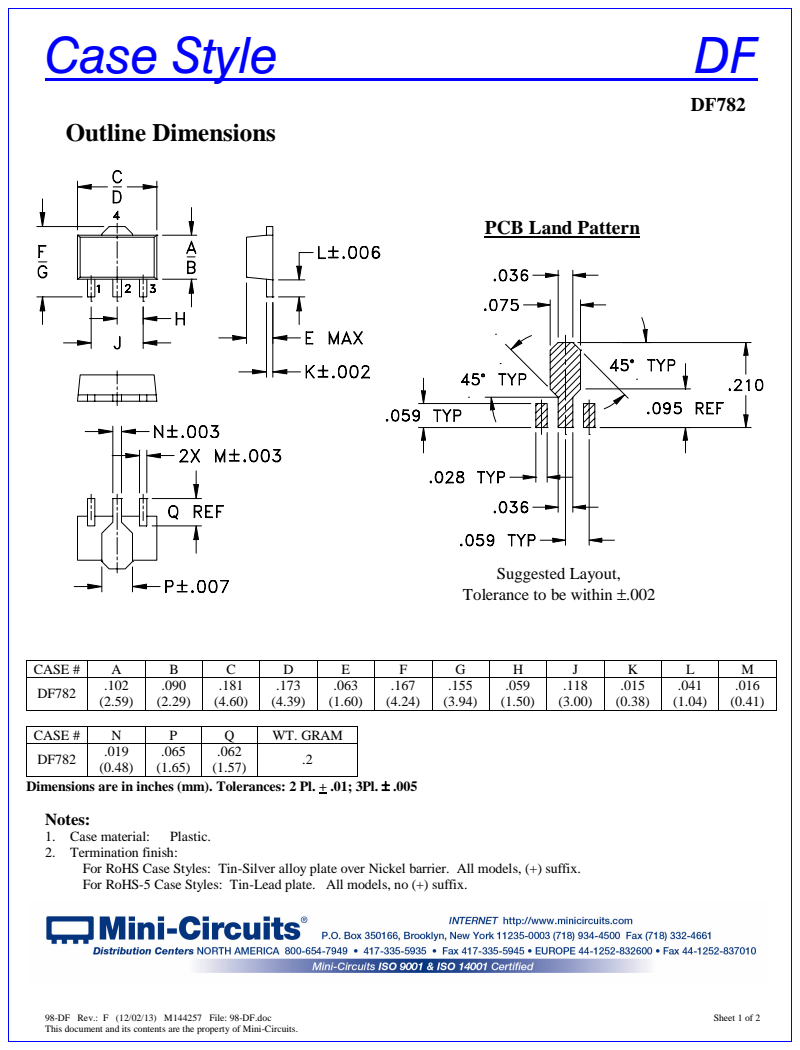
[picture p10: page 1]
98-DF Rev.: F (12/02/13) M144257 File: 98-DF.doc; Sheet 1 of 2; Notes:; 1. Case material:; Plastic.; 2. Termination finish:; Outline Dimensions

Suggested Layout,
Tolerance to be within ±.002

CASE # | A | B | C | D | E | F | G | H | J | K | L | M
DF782 | .102 (2.59) | .090 (2.29) | .181 (4.60) | .173 (4.39) | .063 (1.60) | .167 (4.24) | .155 (3.94) | .059 (1.50) | .118 (3.00) | .015 (0.38) | .041 (1.04) | .016 (0.41)

CASE # | N | P | Q | WT. GRAM
DF782 | .019 (0.48) | .065 (1.65) | .062 (1.57) .2

Dimensions are in inches (mm). Tolerances: 2 Pl. + .01; 3Pl. ± .005

For RoHS Case Styles: Tin-Silver alloy plate over Nickel barrier. All models, (+) suffix.
For RoHS-5 Case Styles: Tin-Lead plate. All models, no (+) suffix.

This document and its contents are the property of Mini-Circuits.

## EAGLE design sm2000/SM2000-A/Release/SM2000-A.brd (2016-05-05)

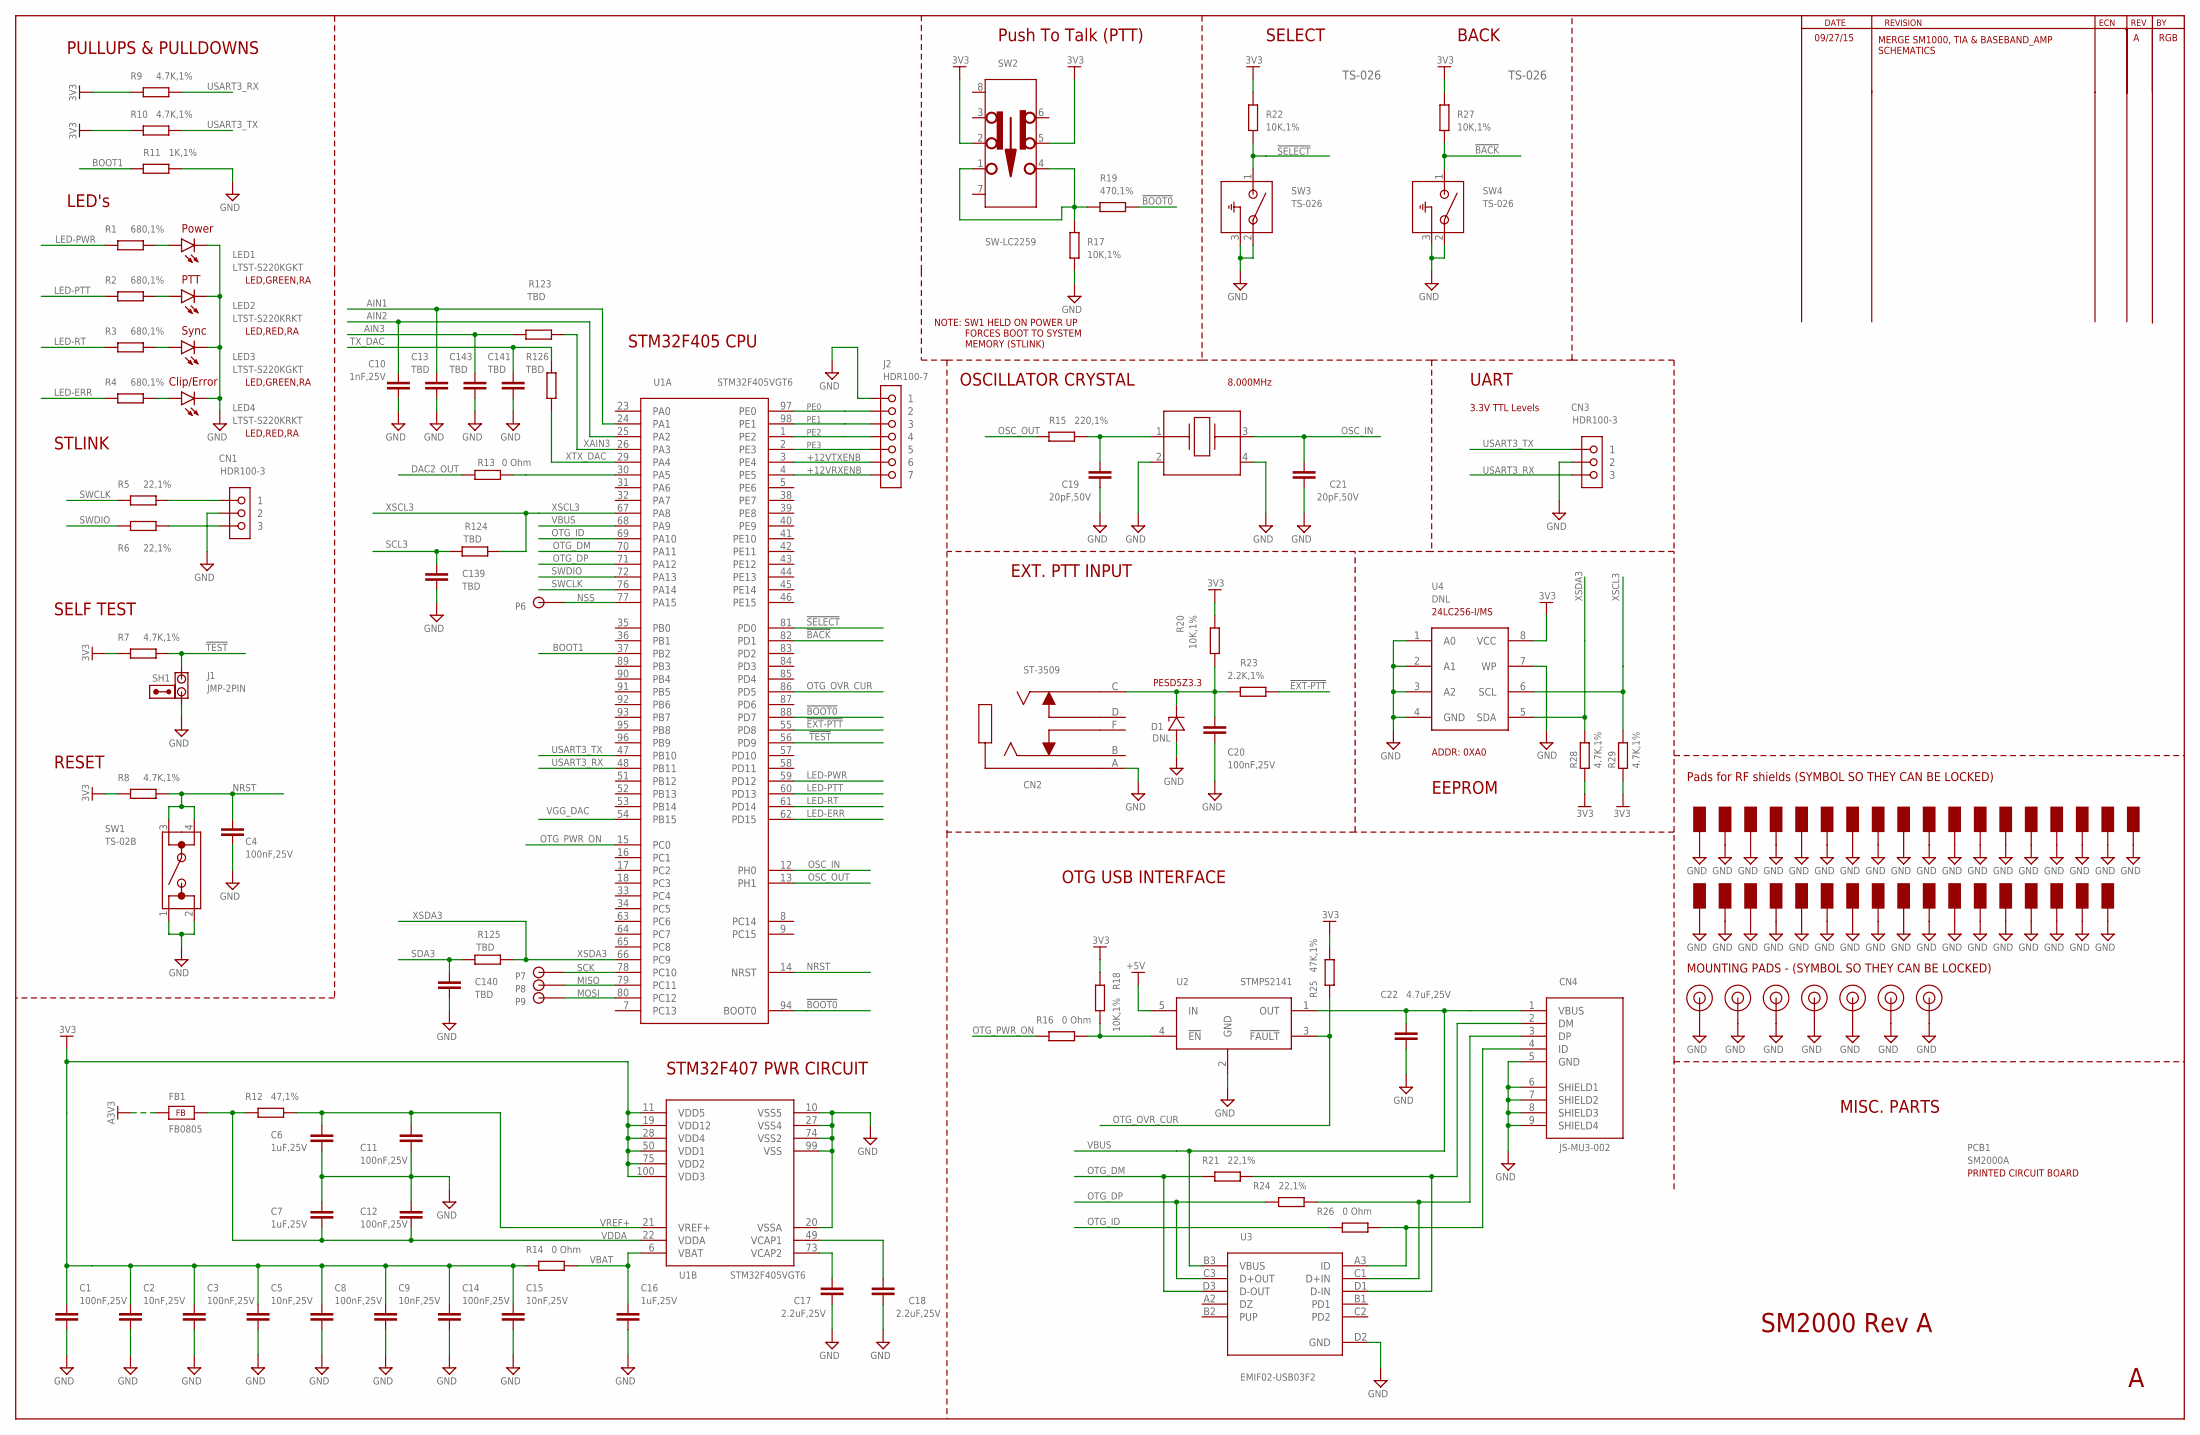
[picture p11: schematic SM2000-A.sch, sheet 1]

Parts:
C1, C3, C4, C8, C11, C12, C14, C20: 100nF,25V; C0805
C2, C5, C9, C15: 10nF,25V; C0805
C6, C7, C16: 1uF,25V; C0805
C10: 1nF,25V; C0805
C13, C139, C140, C141, C143: TBD; C0805
C17, C18: 2.2uF,25V; C0805
C19, C21: 20pF,50V; C0805
C22: 4.7uF,25V; C0805
CN1, CN3: HDR100-3
CN2: ST-3509
CN4: JS-MU3-002; JI-MU3-002
D1: DNL; SOD523
FB1: FB0805; FE0805
J1: JMP-2PIN; JMPR-2PIN
J2: HDR100-7
LED1, LED3: LTST-S220KGKT; LTST-S2200K
LED2, LED4: LTST-S220KRKT; LTST-S2200K
P6, P7, P8, P9: TPAD50
PAD1, PAD2, PAD3, PAD4, PAD5, PAD6, PAD7: MTG-PAD-3.2
PCB1: SM2000A; NOPACKAGE
R1, R2, R3, R4: 680,1%; R0805
R5, R6, R21, R24: 22,1%; R0805
R7, R8, R9, R10, R28, R29: 4.7K,1%; R0805
R11: 1K,1%; R0805
R12: 47,1%; R0805
R13, R14, R16, R26: 0 Ohm; R0805
R15: 220,1%; R0805
R17, R18, R20, R22, R27: 10K,1%; R0805
R19: 470,1%; R0805
R23: 2.2K,1%; R0805
R25: 47K,1%; R0805
R123, R124, R125, R126: TBD; R0805
S1, S2, S3, S4, S5, S6, S8, S9, S10, S11, S12, S14, S15, S16, S17, S18, S20, S21, S22, S23, S24, S25, S26, S27, S28, S29, S30, S31, S35, S36, S37, S38, S39, S40, S43: SGND
SH1: SHUNT,0.1IN; NOPACKAGE
SW1: TS-02B
SW2: SW-LC2259
SW3, SW4: TS-026
U1: STM32F405VGT6; LQFP100-14
U2: STMPS2141; SOT23-5L
U3: EMIF02-USB03F2; ECOPACK-11
U4: DNL; SOIC8
XTAL1: 8.000MHz; CTS-405

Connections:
3V3: C1.1, C2.1, C3.1, C5.1, C8.1, C9.1, C14.1, C15.1, R7.1, R8.1, R9.1, R10.1, R14.1, R18.2, R20.1, R22.2, R25.1, R27.2, R28.1, R29.1, SW2.2, SW2.5, U1.11 (VDD5), U1.19 (VDD12), U1.28 (VDD4), U1.50 (VDD1), U1.75 (VDD2), U1.100 (VDD3), U4.8 (VCC); also elsewhere on the board
!BACK!: R27.1, SW4.1, U1.82 (PD1)
!BOOT0!: R19.1, U1.88 (PD7), U1.94 (BOOT0)
!EXT-PTT!: R23.2, U1.55 (PD8)
!SELECT!: R22.1, SW3.1, U1.81 (PD0)
!TEST!: J1.1, R7.2, U1.56 (PD9)
+5V: U2.5 (IN); also elsewhere on the board
+12VRXENB: J2.7, U1.4 (PE5); also elsewhere on the board
+12VTXENB: J2.6, U1.3 (PE4); also elsewhere on the board
A3V3: FB1.1; also elsewhere on the board
AIN1: C13.1, U1.24 (PA1); also elsewhere on the board
AIN2: C10.1, U1.25 (PA2); also elsewhere on the board
AIN3: C143.1, R123.2; also elsewhere on the board
BOOT1: R11.2, U1.37 (PB2)
DAC2_OUT: R13.2; also elsewhere on the board
GND: C1.2, C2.2, C3.2, C4.2, C5.2, C6.2, C7.2, C8.2, C9.2, C10.2, C11.2, C12.2, C13.2, C14.2, C15.2, C16.2, C17.2, C18.2, C19.2, C20.2, C21.2, C22.2, C139.2, C140.2, C141.2, C143.2, CN1.2, CN2.A, CN3.2, CN4.5 (GND), CN4.6 (SHIELD1), CN4.7 (SHIELD2), CN4.8 (SHIELD3), CN4.9 (SHIELD4), D1.A, J1.2, J2.1, LED1.C, LED2.C, LED3.C, LED4.C, PAD1.P$1, PAD2.P$1, PAD3.P$1, PAD4.P$1, PAD5.P$1, PAD6.P$1, PAD7.P$1, R11.1, R17.1, S1.1, S2.1, S3.1, S4.1, S5.1, S6.1, S8.1, S9.1, S10.1, S11.1, S12.1, S14.1, S15.1, S16.1, S17.1, S18.1, S20.1, S21.1, S22.1, S23.1, S24.1, S25.1, S26.1, S27.1, S28.1, S29.1, S30.1, S31.1, S35.1, S36.1, S37.1, S38.1, S39.1, S40.1, S43.1, SW1.1, SW1.2, SW3.2, SW3.3, SW4.2, SW4.3, U1.10 (VSS5), U1.20 (VSSA), U1.27 (VSS4), U1.74 (VSS2), U1.99 (VSS), U2.2 (GND), U3.D2 (GND), U4.1 (A0), U4.2 (A1), U4.3 (A2), U4.4 (GND), U4.7 (WP), XTAL1.2, XTAL1.4; also elsewhere on the board
LED-ERR: R4.1, U1.62 (PD15)
LED-PTT: R2.1, U1.60 (PD13)
LED-PWR: R1.1, U1.59 (PD12)
LED-RT: R3.1, U1.61 (PD14)
MISO: P8.1, U1.79 (PC11)
MOSI: P9.1, U1.80 (PC12)
unnamed: C17.1, U1.73 (VCAP2)
unnamed: C18.1, U1.49 (VCAP1)
unnamed: CN1.3, R6.2
unnamed: CN1.1, R5.2
unnamed: C19.1, R15.2, XTAL1.1
unnamed: R13.1, U1.30 (PA5)
unnamed: R17.2, R19.2, SW2.1, SW2.4
unnamed: C20.1, CN2.C, D1.C, R20.2, R23.1
unnamed: LED1.A, R1.2
unnamed: LED2.A, R2.2
unnamed: LED3.A, R3.2
unnamed: LED4.A, R4.2
unnamed: CN4.3 (DP), R24.1, U3.C1 (D+IN)
unnamed: CN4.2 (DM), R21.1, U3.D1 (D-IN)
unnamed: CN4.4 (ID), R26.1, U3.A3 (ID)
unnamed: R16.2, R18.1, U2.4 (!EN!)
NRST: C4.1, R8.2, SW1.3, SW1.4, U1.14 (NRST)
NSS: P6.1, U1.77 (PA15)
OSC_IN: C21.1, U1.12 (PH0), XTAL1.3
OSC_OUT: R15.1, U1.13 (PH1)
OTG_DM: R21.2, U1.70 (PA11), U3.D3 (D-OUT)
OTG_DP: R24.2, U1.71 (PA12), U3.C3 (D+OUT)
OTG_ID: R26.2, U1.69 (PA10)
OTG_OVR_CUR: R25.2, U1.86 (PD5), U2.3 (!FAULT!)
OTG_PWR_ON: R16.1, U1.15 (PC0)
PE0: J2.2, U1.97 (PE0)
PE1: J2.3, U1.98 (PE1)
PE2: J2.4, U1.1 (PE2)
PE3: J2.5, U1.2 (PE3)
SCK: P7.1, U1.78 (PC10)
SCL3: C139.1, R124.2; also elsewhere on the board
SDA3: C140.1, R125.2; also elsewhere on the board
SWCLK: R5.1, U1.76 (PA14)
SWDIO: R6.1, U1.72 (PA13)
TX_DAC: C141.1, R126.2; also elsewhere on the board
USART3_RX: CN3.3, R9.2, U1.48 (PB11)
USART3_TX: CN3.1, R10.2, U1.47 (PB10)
VBAT: C16.1, R14.2, U1.6 (VBAT)
VBUS: C22.1, CN4.1 (VBUS), U1.68 (PA9), U2.1 (OUT), U3.B3 (VBUS)
VDDA: C7.1, C12.1, FB1.2, R12.1, U1.22 (VDDA)
VGG_DAC: U1.54 (PB15); also elsewhere on the board
VREF+: C6.1, C11.1, R12.2, U1.21 (VREF+)
XAIN3: R123.1, U1.26 (PA3)
XSCL3: R29.2, R124.1, U1.67 (PA8), U4.6 (SCL)
XSDA3: R28.2, R125.1, U1.66 (PC9), U4.5 (SDA)
XTX_DAC: R126.1, U1.29 (PA4)

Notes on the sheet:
PULLUPS & PULLDOWNS
LED's
STLINK
OSCILLATOR CRYSTAL
OTG USB INTERFACE
STM32F405 CPU
STM32F407 PWR CIRCUIT
SM2000 Rev A
Push To Talk (PTT)
NOTE: SW1 HELD ON POWER UP FORCES BOOT TO SYSTEM MEMORY (STLINK)
SELF TEST
RESET
SELECT
BACK
Power
PTT
Sync
Clip/Error
UART
3.3V TTL Levels
8.000MHz
TS-026
RGB
MISC. PARTS
LED,GREEN,RA
LED,RED,RA
EEPROM
ADDR: 0XA0
09/27/15
24LC256-I/MS
MERGE SM1000, TIA & BASEBAND_AMP SCHEMATICS
EXT. PTT INPUT
PESD5Z3.3
Pads for RF shields (SYMBOL SO THEY CAN BE LOCKED)
MOUNTING PADS - (SYMBOL SO THEY CAN BE LOCKED)

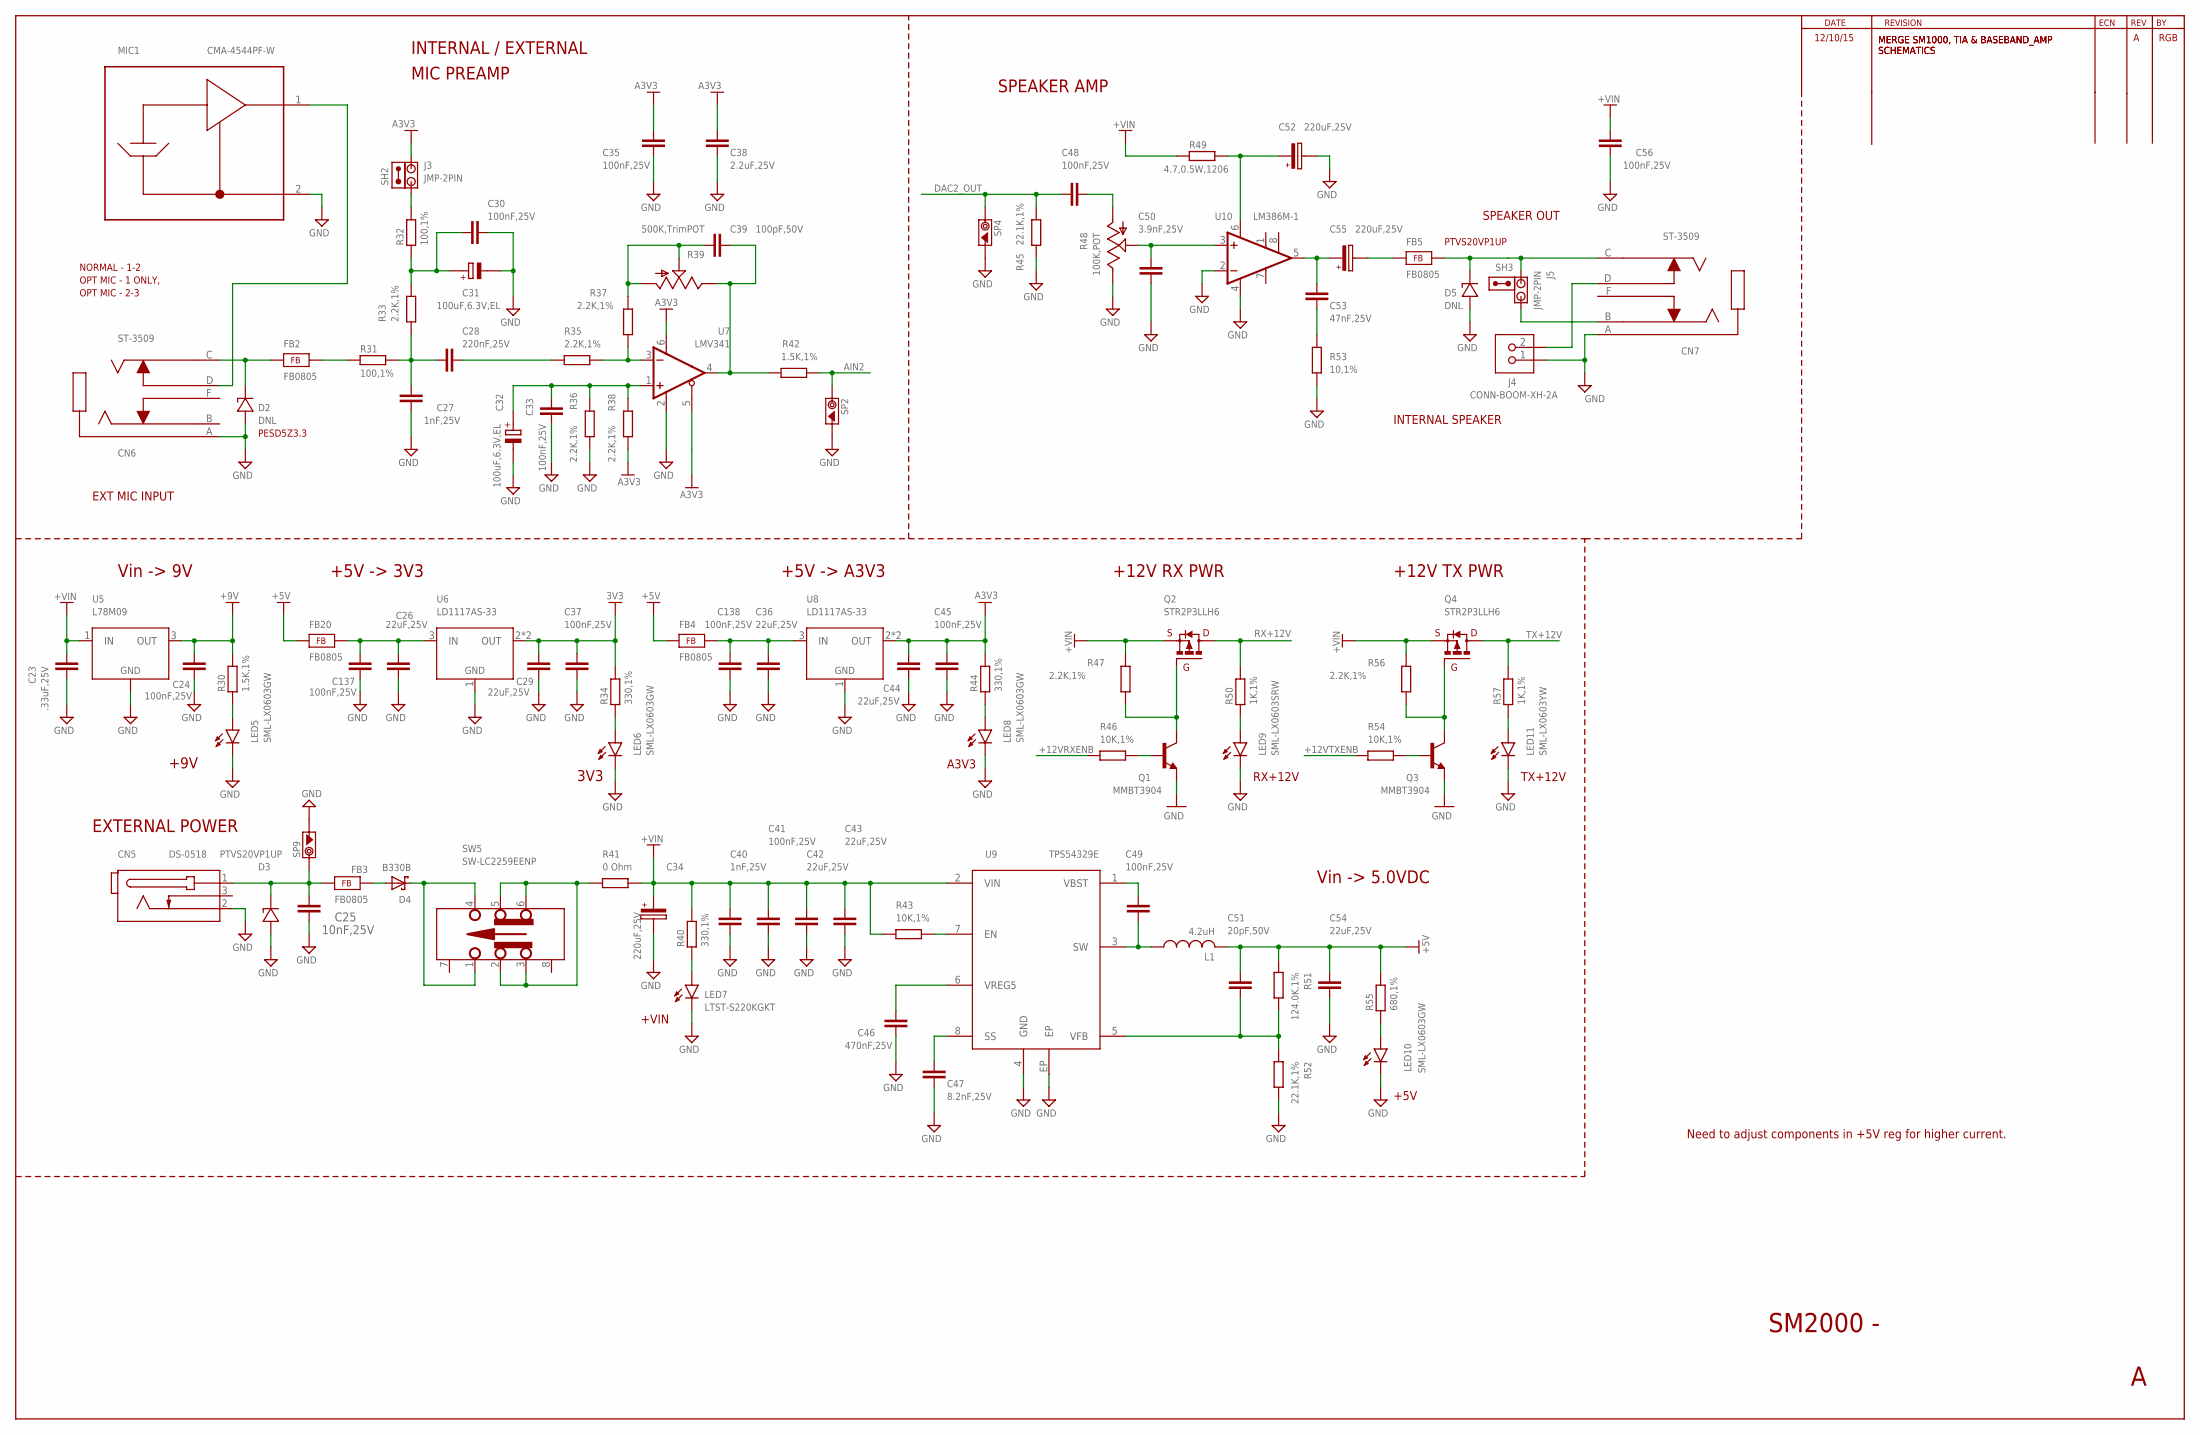
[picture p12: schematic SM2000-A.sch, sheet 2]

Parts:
C23: .33uF,25V; C0805
C24, C30, C33, C35, C37, C41, C45, C48, C49, C56, C137, C138: 100nF,25V; C0805
C25: 10nF,25V; C0805
C26, C29, C36, C42, C43, C44, C54: 22uF,25V; C1210
C27, C40: 1nF,25V; C0805
C28: 220nF,25V; C0805
C31, C32: 100uF,6.3V,EL; NICHICON-WX-6.3
C34, C52, C55: 220uF,25V; CAP-CHEMI-HA0
C38: 2.2uF,25V; C0805
C39: 100pF,50V; C0805
C46: 470nF,25V; C0805
C47: 8.2nF,25V; C0805
C50: 3.9nF,25V; C0805
C51: 20pF,50V; C0805
C53: 47nF,25V; C0805
CN5: DS-0518
CN6, CN7: ST-3509
D2: DNL; SOD523
D3: PTVS20VP1UP; SOD128
D4: B330B; SMB
D5: DNL; SOD128
FB2, FB3, FB4, FB5, FB20: FB0805; FE0805
J3, J5: JMP-2PIN; JMPR-2PIN
J4: CONN-BOOM-XH-2A
L1: 4.2uH; SRR5028
LED5, LED6, LED8, LED10: SML-LX0603GW; SML-LX0603SRW
LED7: LTST-S220KGKT; LTST-S2200K
LED9: SML-LX0603SRW
LED11: SML-LX0603YW; SML-LX0603SRW
MIC1: CMA-4544PF-W
Q1, Q3: MMBT3904; SOT23
Q2, Q4: STR2P3LLH6; SOT23
R30, R42: 1.5K,1%; R0805
R31, R32: 100,1%; R0805
R33, R35, R36, R37, R38, R47, R56: 2.2K,1%; R0805
R34, R40, R44: 330,1%; R0805
R39: 500K,TrimPOT; POT3361
R41: 0 Ohm; R0805
R43, R46, R54: 10K,1%; R0805
R45, R52: 22.1K,1%; R0805
R48: 100K,POT; POT-3310C
R49: 4.7,0.5W,1206; R1206
R50, R57: 1K,1%; R0805
R51: 124.0K,1%; R0805
R53: 10,1%; R0805
R55: 680,1%; R0805
SH2, SH3: SHUNT,0.1IN; NOPACKAGE
SP2, SP4, SP9: SCOPE_PAD
SW5: SW-LC2259EENP; SW-LC2259
U5: L78M09; DPAK
U6, U8: LD1117AS-33; SOT223
U7: LMV341; SOT23-6
U9: TPS54329E; PSO-DDA
U10: LM386M-1; SO08

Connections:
3V3: C29.1, C37.1, R34.2, U6.2 (OUT), U6.4 (OUT); also elsewhere on the board
+5V: C51.1, C54.1, FB4.1, FB20.1, L1.2, R51.1, R55.2; also elsewhere on the board
+9V: C24.1, R30.2, U5.3 (OUT); also elsewhere on the board
+12VRXENB: R46.1; also elsewhere on the board
+12VTXENB: R54.1; also elsewhere on the board
+VIN: C23.1, C34.1, C40.1, C41.1, C42.1, C43.1, C56.1, Q2.2 (S), Q4.2 (S), R40.2, R41.2, R43.1, R47.2, R49.1, R56.2, U5.1 (IN), U9.2 (VIN)
A3V3: C35.1, C38.1, C44.1, C45.1, J3.2, R38.2, R44.2, U7.5 (!SHDN!), U7.6 (V+), U8.2 (OUT), U8.4 (OUT); also elsewhere on the board
AIN2: R42.1, SP2.1; also elsewhere on the board
DAC2_OUT: C48.1, R45.1, SP4.1; also elsewhere on the board
GND: C23.2, C24.2, C25.2, C26.2, C27.2, C29.2, C30.2, C31.2 (-), C32.2 (-), C33.1, C34.2, C35.2, C36.2, C37.2, C38.2, C40.2, C41.2, C42.2, C43.2, C44.2, C45.2, C46.2, C47.2, C50.2, C52.2, C54.2, C56.2, C137.2, C138.2, CN5.2, CN6.A, CN7.A, D2.A, D3.A, D5.A, J4.1, LED5.C, LED6.C, LED7.C, LED8.C, LED9.C, LED10.C, LED11.C, MIC1.2, Q1.2 (E), Q3.2 (E), R36.2, R45.2, R48.1, R52.2, R53.2, SP2.2, SP4.2, SP9.2, U5.4 (GND), U6.1 (GND), U7.2 (GND), U8.1 (GND), U9.4 (GND), U9.EP, U10.2 (-IN), U10.4 (GND); also elsewhere on the board
unnamed: C53.1, C55.1, U10.5 (OUT)
unnamed: D4.A, FB3.2
unnamed: C27.1, C28.1, R31.2, R33.1
unnamed: FB2.2, R31.1
unnamed: C39.2, R39.1, R42.2, U7.4 (OUT)
unnamed: J3.1, R32.2
unnamed: C48.2, R48.3
unnamed: C28.2, R35.1
unnamed: C50.1, R48.2, U10.3 (+IN)
unnamed: C39.1, R37.2, R39.2, R39.3
unnamed: Q1.3 (C), Q2.1 (G), R47.1
unnamed: C53.2, R53.1
unnamed: C55.2, FB5.1
unnamed: C30.1, C31.1 (+), R32.1, R33.2
unnamed: C32.1 (+), C33.2, R36.1, R38.1, U7.1 (+IN)
unnamed: C52.1, R49.2, U10.6 (VS)
unnamed: Q3.3 (C), Q4.1 (G), R56.1
unnamed: Q1.1 (B), R46.2
unnamed: C36.1, C138.1, FB4.2, U8.3 (IN)
unnamed: Q3.1 (B), R54.2
unnamed: CN6.D, MIC1.1
unnamed: CN7.C, D5.C, FB5.2, J5.2
unnamed: LED5.A, R30.1
unnamed: CN7.B, J5.1
unnamed: CN7.D, J4.2
unnamed: CN6.C, D2.C, FB2.1
unnamed: C25.1, CN5.1, D3.C, FB3.1, SP9.1
unnamed: D4.C (K), SW5.1, SW5.4
unnamed: R35.2, R37.1, U7.3 (-IN)
unnamed: C26.1, C137.1, FB20.2, U6.3 (IN)
unnamed: LED8.A, R44.1
unnamed: LED9.A, R50.1
unnamed: LED6.A, R34.1
unnamed: LED11.A, R57.1
unnamed: LED10.A, R55.1
unnamed: LED7.A, R40.1
unnamed: R41.1, SW5.2, SW5.3, SW5.5, SW5.6
unnamed: C49.1, U9.1 (VBST)
unnamed: C51.2, R51.2, R52.1, U9.5 (VFB)
unnamed: C47.1, U9.8 (SS)
unnamed: C46.1, U9.6 (VREG5)
unnamed: R43.2, U9.7 (EN)
RX+12V: Q2.3 (D), R50.2; also elsewhere on the board
SW: C49.2, L1.1, U9.3 (SW)
TX+12V: Q4.3 (D), R57.2; also elsewhere on the board

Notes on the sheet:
SPEAKER OUT
EXT MIC INPUT
EXTERNAL POWER
INTERNAL / EXTERNAL
MIC PREAMP
SPEAKER AMP
SM2000 -
NORMAL - 1-2
OPT MIC - 1 ONLY,
OPT MIC - 2-3
INTERNAL SPEAKER
+5V -> A3V3
PTVS20VP1UP
PESD5Z3.3
RGB
12/10/15
MERGE SM1000, TIA & BASEBAND_AMP SCHEMATICS
+12V RX PWR
+12V TX PWR
Vin -> 5.0VDC
+5V -> 3V3
Vin -> 9V
Need to adjust components in +5V reg for higher current.
+9V
3V3
A3V3
RX+12V
TX+12V
+5V
+VIN

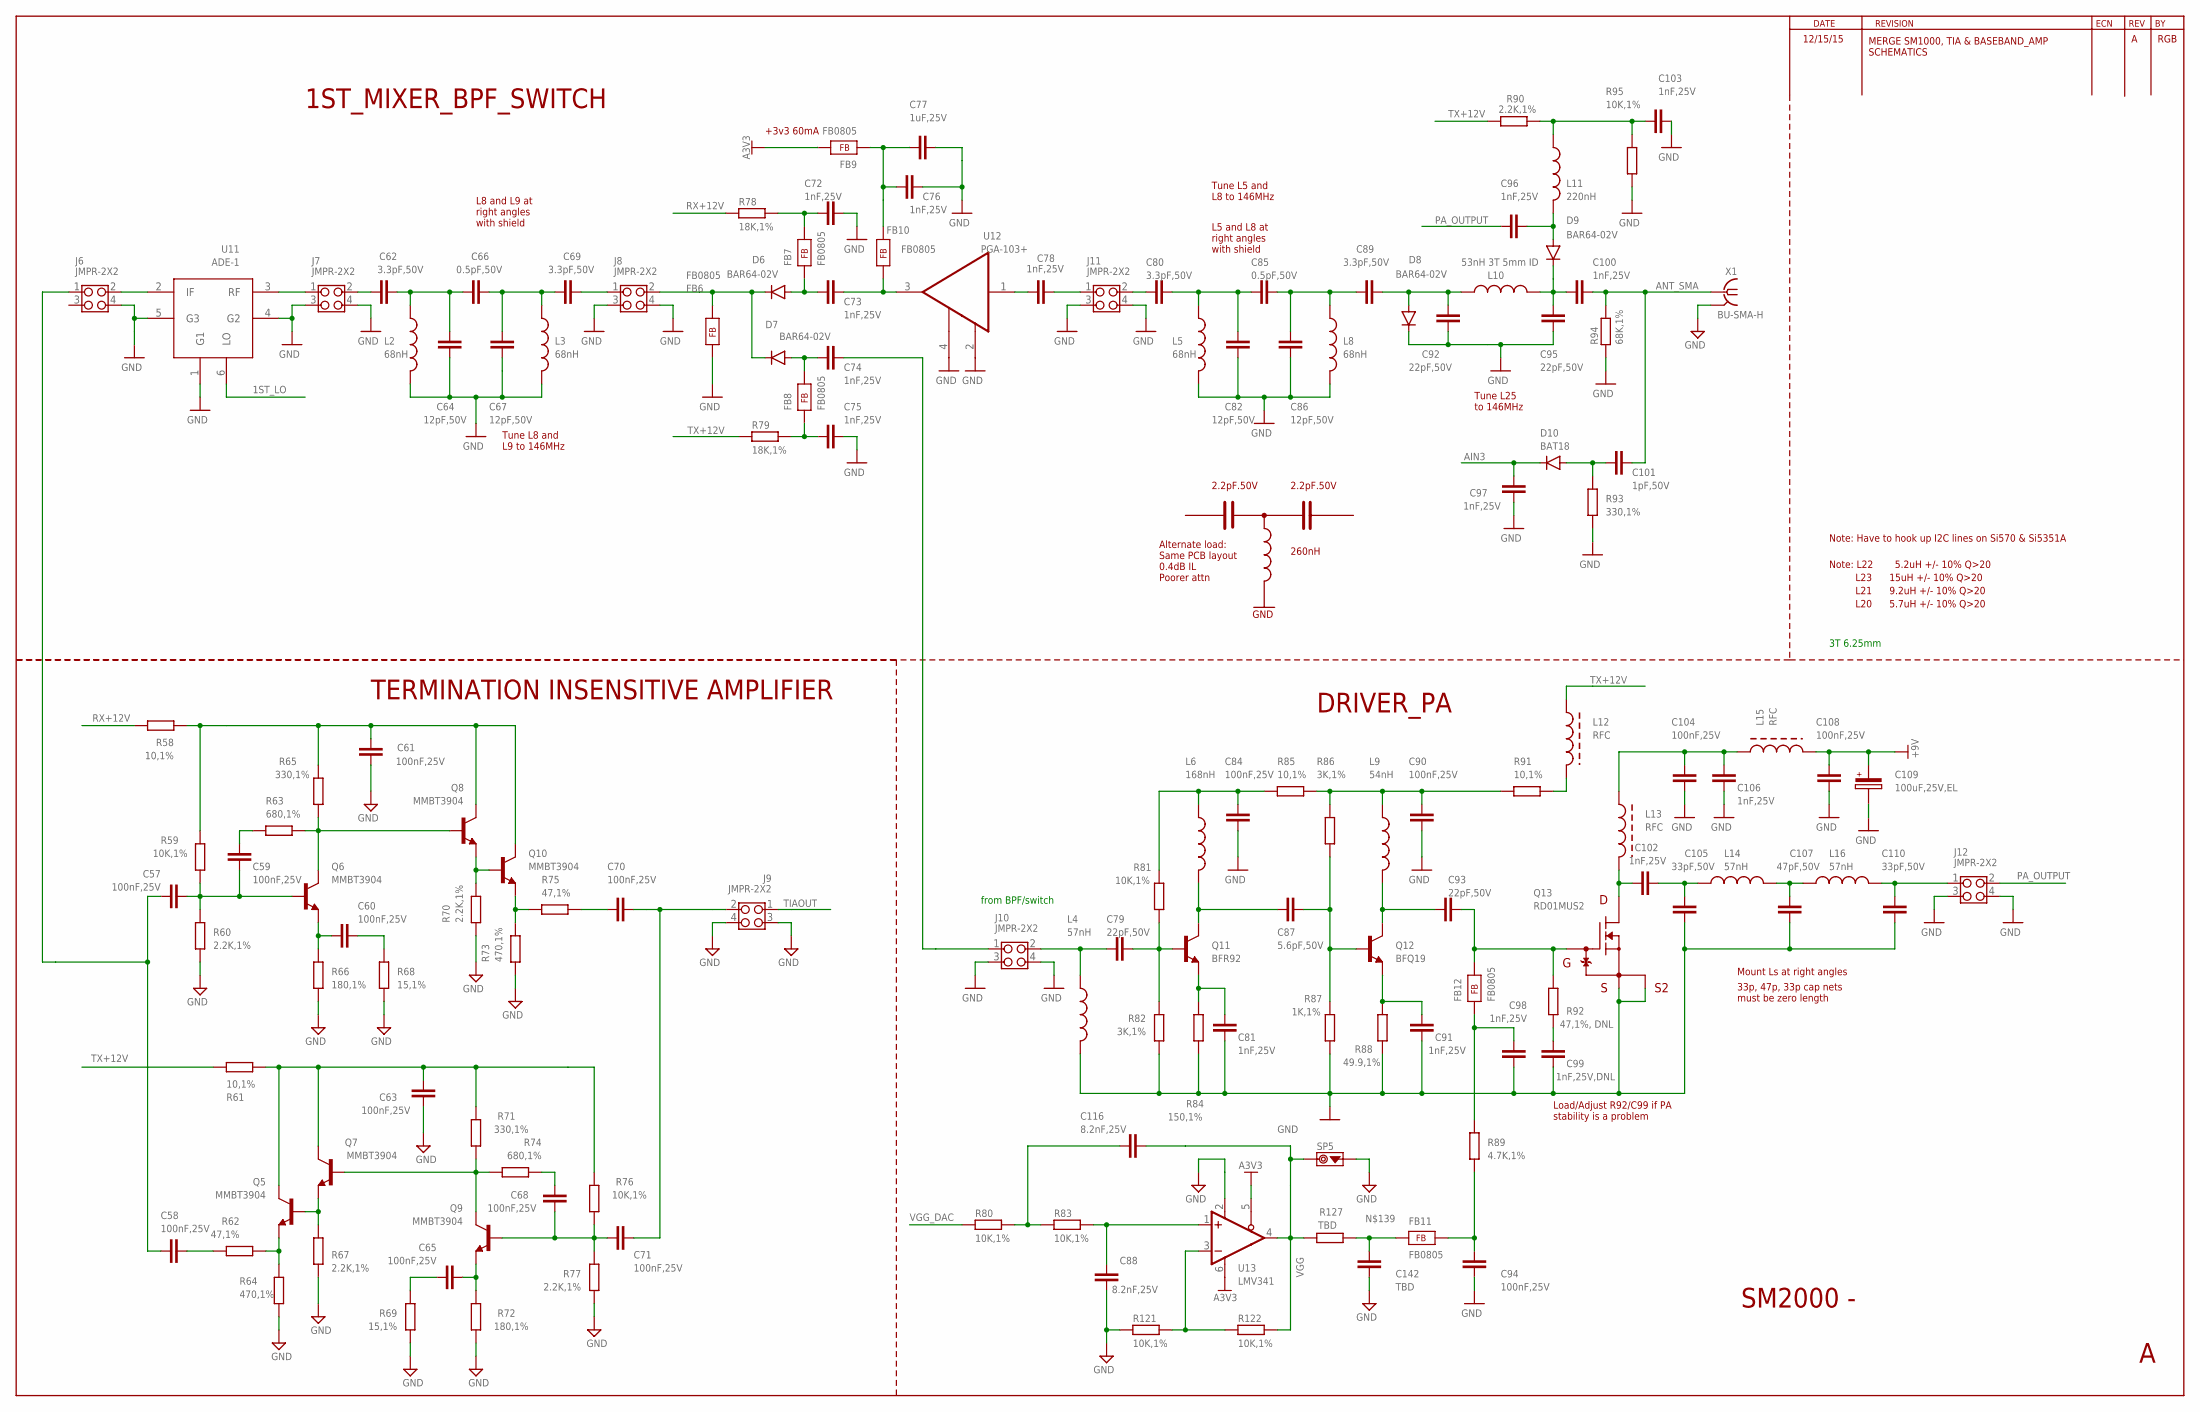
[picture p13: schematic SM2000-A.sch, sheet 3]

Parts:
C57, C58, C59, C60, C61, C63, C65, C68, C70, C71, C84, C90, C94, C104, C108: 100nF,25V; C0805
C62, C69, C80, C89: 3.3pF,50V; C0805
C64, C67, C82, C86: 12pF,50V; C0805
C66, C85: 0.5pF,50V; C0805
C72, C73, C74, C75, C76, C78, C81, C91, C96, C97, C98, C100, C102, C103, C106: 1nF,25V; C0805
C77: 1uF,25V; C0805
C79, C92, C93, C95: 22pF,50V; C0805
C87: 5.6pF,50V; C0805
C88, C116: 8.2nF,25V; C0805
C99: 1nF,25V,DNL; C0805
C101: 1pF,50V; C0805
C105, C110: 33pF,50V; C0805
C107: 47pF,50V; C0805
C109: 100uF,25V,EL; CAP-CHEMI-F80
C142: TBD; C0805
D6, D7, D8, D9: BAR64-02V; SC79_INFINEON
D10: BAT18; SOT23
FB6, FB7, FB8, FB9, FB10, FB11, FB12: FB0805; FE0805
J6, J7, J8, J9, J10, J11, J12: JMPR-2X2; JMPR-2X2X.1
L2, L3, L5, L8: 68nH; L10X15
L4, L14, L16: 57nH; L10X15
L6: 168nH; L10X15
L9: 54nH; L10X15
L10: 53nH 3T 5mm ID; L10X15
L11: 220nH; L10X15
L12, L13, L15: RFC; Z15/4
Q5, Q6, Q7, Q8, Q9, Q10: MMBT3904; SOT23
Q11: BFR92; SOT23
Q12: BFQ19; SOT89
Q13: RD01MUS2; SOT89
R58, R61, R85, R91: 10,1%; R0805
R59, R76, R80, R81, R83, R95, R121, R122: 10K,1%; R0805
R60, R67, R70, R77, R90: 2.2K,1%; R0805
R62, R75: 47,1%; R0805
R63, R74: 680,1%; R0805
R64, R73: 470,1%; R0805
R65, R71, R93: 330,1%; R0805
R66, R72: 180,1%; R0805
R68, R69: 15,1%; R0805
R78, R79: 18K,1%; R0805
R82, R86: 3K,1%; R0805
R84: 150,1%; R0805
R87: 1K,1%; R0805
R88: 49.9,1%; R0805
R89: 4.7K,1%; R0805
R92: 47,1%, DNL; R0805
R94: 68K,1%; R0805
R127: TBD; R0805
SP5: SCOPE_PAD
U11: ADE-1
U12: PGA-103+; DF782
U13: LMV341; SOT23-6
X1: BU-SMA-H

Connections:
1ST_LO: U11.6 (LO); also elsewhere on the board
+9V: C108.1, C109.1, L15.2; also elsewhere on the board
A3V3: FB9.2, U13.5 (!SHDN!), U13.6 (V+); also elsewhere on the board
AIN3: C97.2, D10.1 (K); also elsewhere on the board
ANT_SMA: C100.1, C101.2, R94.2, X1.1
DRIVER/PA_INPUT: C74.2, J10.1
GND: C61.2, C63.2, C64.2, C67.1, C72.2, C75.2, C76.2, C77.2, C81.2, C82.2, C84.2, C86.1, C88.2, C90.2, C91.2, C92.2, C94.2, C95.2, C97.1, C98.2, C99.2, C103.2, C104.2, C105.2, C106.2, C107.2, C108.2, C109.2, C110.2, C142.2, D8.C, FB6.1, J6.4, J7.3, J7.4, J8.3, J8.4, J9.3, J9.4, J10.3, J10.4, J11.3, J11.4, J12.3, J12.4, L2.2, L3.2, L4.2, L5.2, L8.2, Q13.2 (S), Q13.4 (S2), R60.1, R64.1, R66.1, R67.1, R68.1, R69.1, R70.1, R72.1, R73.1, R77.1, R82.1, R84.1, R87.1, R88.1, R93.1, R94.1, R95.1, R121.1, SP5.2, U11.1 (G1), U11.4 (G2), U11.5 (G3), U12.2 (GND), U12.4 (GND1), U13.2 (GND), X1.2, X1.3 (2), X1.4 (2), X1.5 (2); also elsewhere on the board
unnamed: C76.1, C77.1, FB9.1, FB10.2
unnamed: R121.2, R122.1, U13.3 (-IN)
unnamed: C107.1, L14.2, L16.1
unnamed: C80.2, J11.2
unnamed: J6.2, U11.2 (IF)
unnamed: L12.2, R91.1
unnamed: C62.1, C64.1, C66.2, L2.1
unnamed: C116.1, R80.2, R83.1
unnamed: C102.1, L13.2, Q13.3 (D)
unnamed: C93.1, FB12.2, Q13.1 (G), R92.2
unnamed: C88.1, R83.2, U13.1 (+IN)
unnamed: C95.1, C100.2, D9.C, L10.2
unnamed: C94.1, FB11.2, R89.1
unnamed: C110.1, J12.1, L16.2
unnamed: C62.2, J7.2
unnamed: C101.1, D10.3 (A), R93.2
unnamed: J7.1, U11.3 (RF)
unnamed: C78.2, J11.1
unnamed: C78.1, U12.1 (1N)
unnamed: C70.1, C71.2, J9.2
unnamed: Q6.3 (C), Q8.1 (B), R63.2, R65.2
unnamed: C61.1, Q8.3 (C), Q10.3 (C), R58.1, R59.2, R65.1
unnamed: Q8.2 (E), Q10.1 (B), R70.2
unnamed: C59.1, R63.1
unnamed: C81.1, Q11.2 (E), R84.2
unnamed: C91.1, Q12.3 (E), R88.2
unnamed: C84.1, L6.1, R81.2, R85.2
unnamed: C90.1, L9.1, R85.1, R86.2, R91.2
unnamed: C87.1, Q12.1 (B), R86.1, R87.2
unnamed: C79.1, Q11.1 (B), R81.1, R82.2
unnamed: C69.1, J8.1
unnamed: C87.2, L6.2, Q11.3 (C)
unnamed: C57.1, C59.2, Q6.1 (B), R59.1, R60.2
unnamed: C93.2, L9.2, Q12.2 (C), Q12.4 (C)
unnamed: C60.1, Q6.2 (E), R66.2
unnamed: C60.2, R68.2
unnamed: Q10.2 (E), R73.2, R75.1
unnamed: C70.2, R75.2
unnamed: Q7.1 (B), Q9.3 (C), R71.2, R74.2
unnamed: C63.1, Q5.3 (C), Q7.3 (C), R61.2, R71.1, R76.2
unnamed: Q5.1 (B), Q7.2 (E), R67.2
unnamed: C68.1, R74.1
unnamed: C68.2, C71.1, Q9.1 (B), R76.1, R77.2
unnamed: C65.1, Q9.2 (E), R72.2
unnamed: C65.2, R69.2
unnamed: Q5.2 (E), R62.1, R64.2
unnamed: C58.2, R62.2
unnamed: C72.1, FB7.2, R78.2
unnamed: C79.2, J10.2, L4.1
unnamed: C99.1, R92.1
unnamed: C98.1, FB12.1, R89.2
unnamed: C73.1, D6.A, FB7.1
unnamed: C73.2, FB10.1, U12.3 (OUT)
unnamed: C74.1, D7.A, FB8.2
unnamed: C102.2, C105.1, L14.1
unnamed: C75.1, FB8.1, R79.2
unnamed: C66.1, C67.2, C69.2, L3.1
unnamed: C104.1, C106.1, L13.1, L15.1
unnamed: D6.C, D7.C, FB6.2, J8.2
unnamed: C80.1, C82.1, C85.2, L5.1
unnamed: C85.1, C86.2, C89.2, L8.1
unnamed: C142.1, FB11.1, R127.1
unnamed: C89.1, C92.1, D8.A, L10.1
unnamed: C96.1, D9.A, L11.2
unnamed: C103.1, L11.1, R90.1, R95.2
PA_OUTPUT: C96.2, J12.2
RX+12V: R58.2, R78.1; also elsewhere on the board
TIAIN: C57.2, C58.1, J6.1
TIAOUT: J9.1; also elsewhere on the board
TX+12V: L12.1, R61.1, R79.1, R90.2; also elsewhere on the board
VGG: C116.2, R122.2, R127.2, SP5.1, U13.4 (OUT)
VGG_DAC: R80.1; also elsewhere on the board

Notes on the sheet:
SM2000 -
12/15/15
MERGE SM1000, TIA & BASEBAND_AMP SCHEMATICS
RGB
3T 6.25mm
Note: L22
5.2uH +/- 10% Q>20
L23 15uH +/- 10% Q>20
L21 9.2uH +/- 10% Q>20
L20 5.7uH +/- 10% Q>20
Note: Have to hook up I2C lines on Si570 & Si5351A
Tune L8 and L9 to 146MHz
+3v3 60mA
Alternate load: Same PCB layout 0.4dB IL Poorer attn
Tune L5 and L8 to 146MHz
L5 and L8 at right angles with shield
L8 and L9 at right angles with shield
Tune L25 to 146MHz
1ST_MIXER_BPF_SWITCH
TERMINATION INSENSITIVE AMPLIFIER
Load/Adjust R92/C99 if PA stability is a problem
from BPF/switch
33p, 47p, 33p cap nets must be zero length
Mount Ls at right angles
DRIVER_PA
GND
2.2pF.50V
260nH

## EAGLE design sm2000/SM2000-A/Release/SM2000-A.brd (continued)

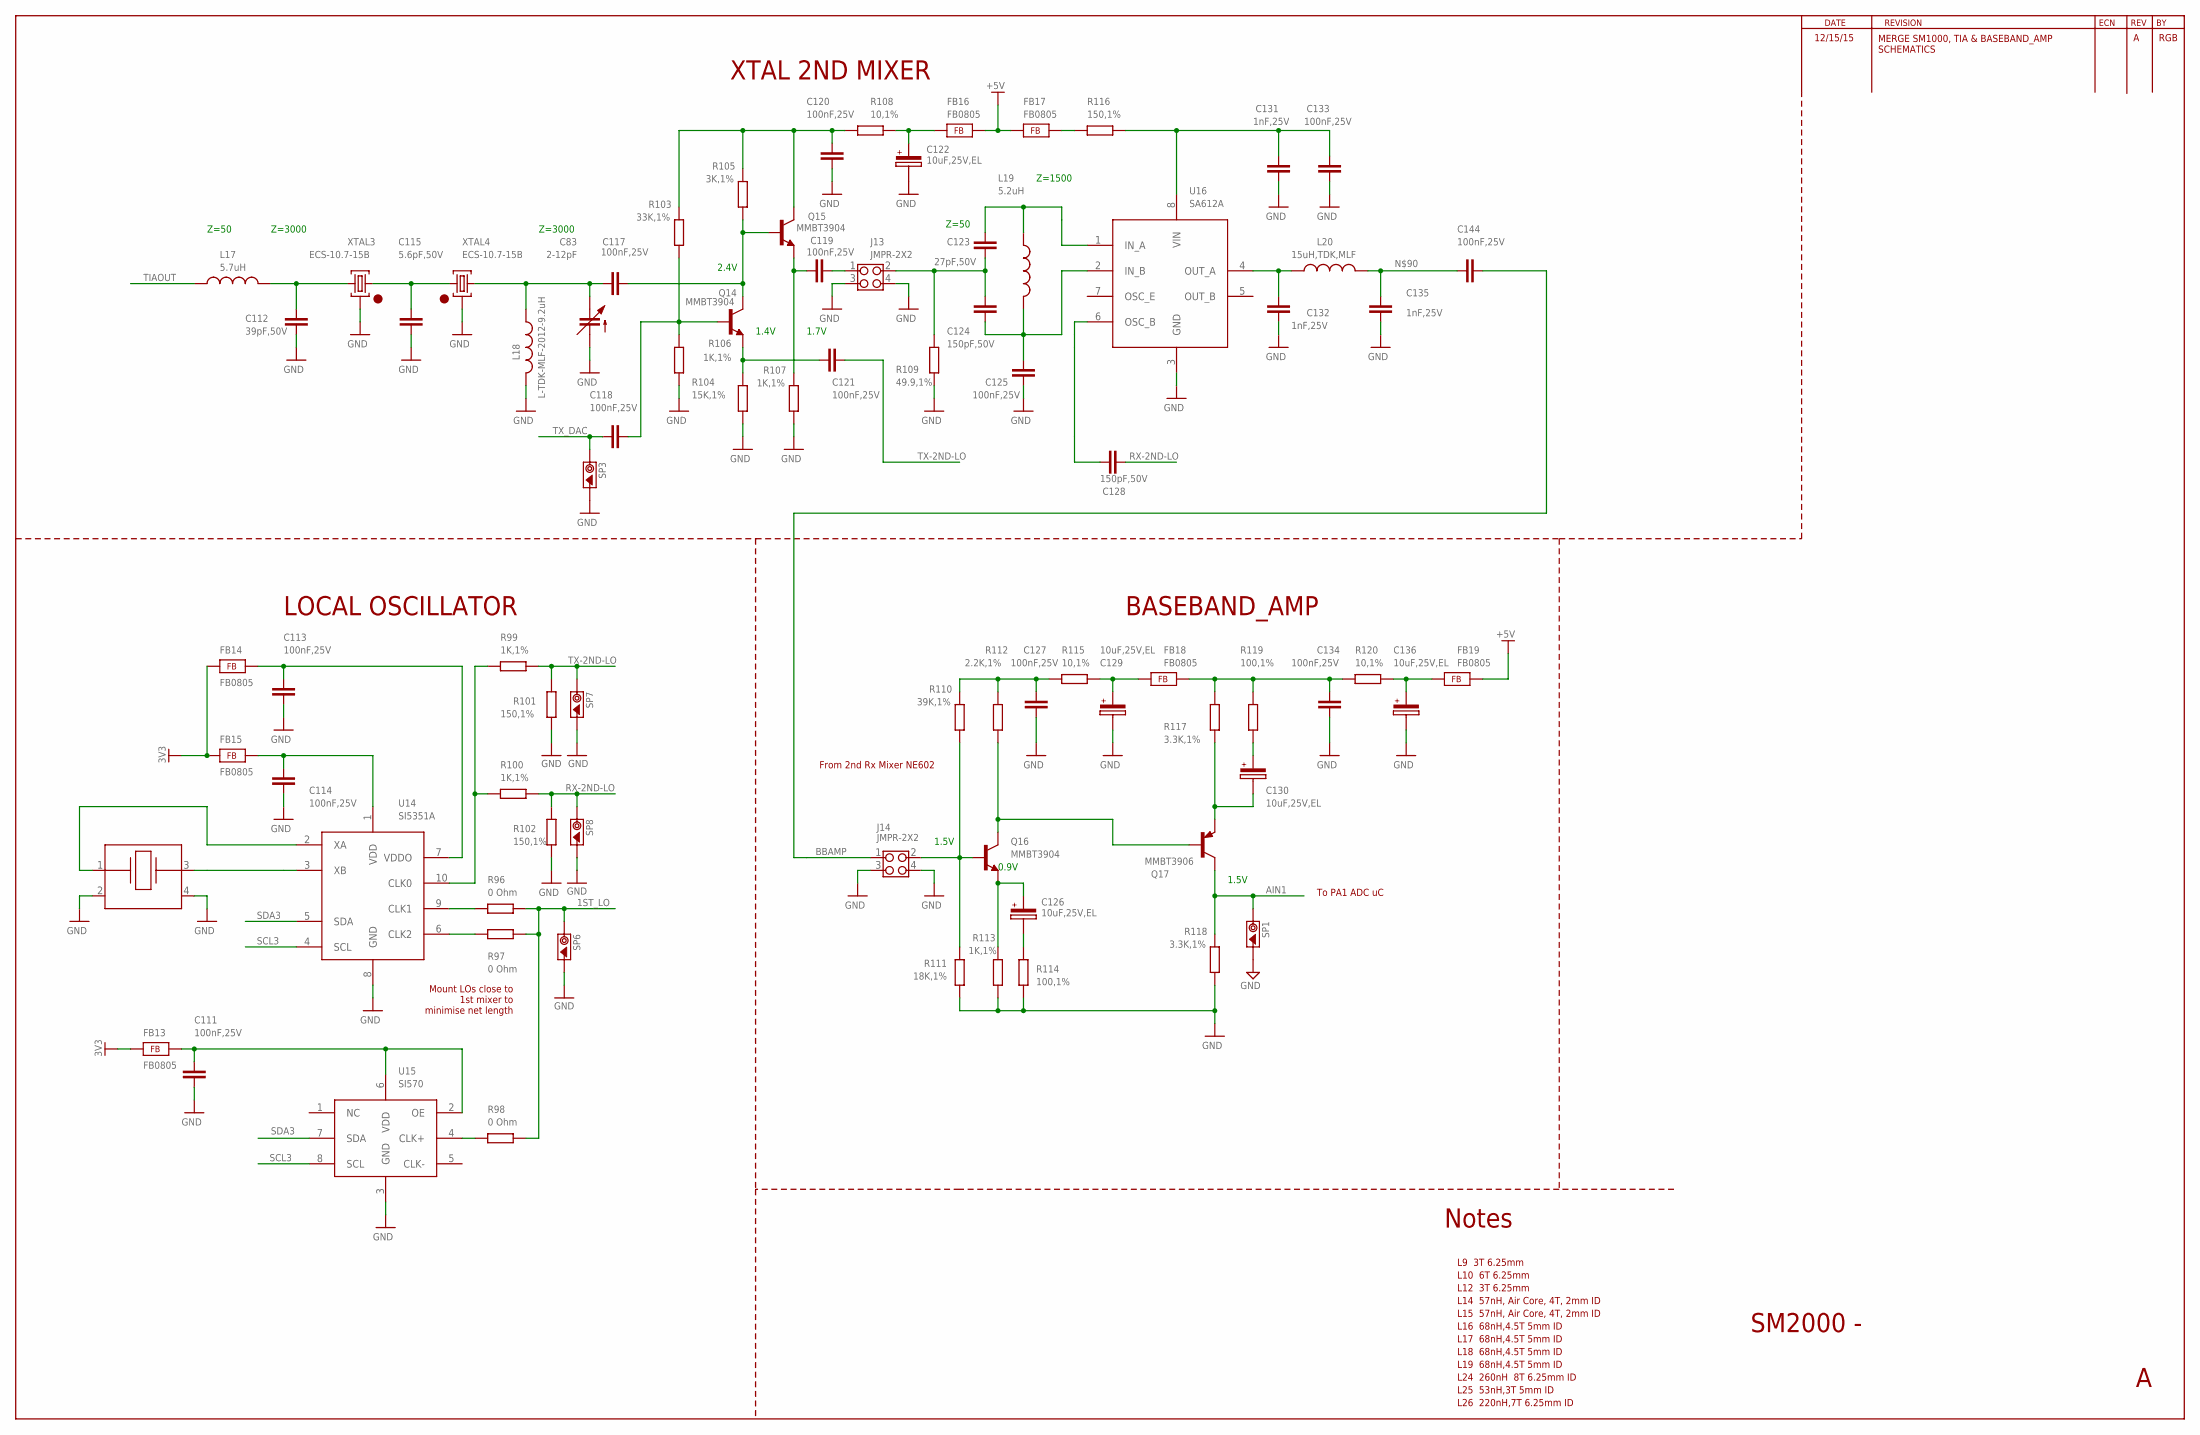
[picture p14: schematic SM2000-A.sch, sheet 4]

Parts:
C83: 2-12pF; TRIMCAP_VAR_2222_V
C111, C113, C114, C117, C118, C119, C120, C121, C125, C127, C133, C134, C144: 100nF,25V; C0805
C112: 39pF,50V; C0805
C115: 5.6pF,50V; C0805
C122, C126, C129, C130, C136: 10uF,25V,EL; NICHICON-WJ-5
C123: 27pF,50V; C0805
C124, C128: 150pF,50V; C0805
C131, C132, C135: 1nF,25V; C0805
FB13, FB14, FB15, FB16, FB17, FB18, FB19: FB0805; FE0805
J13, J14: JMPR-2X2; JMPR-2X2X.1
L17: 5.7uH; L-TDK-MLF2012
L18: L-TDK-MLF-2012-9.2uH; L-TDK-MLF2012
L19: 5.2uH; L-TDK-MLF2012
L20: 15uH,TDK,MLF; L-TDK-MLF2012
Q14, Q15, Q16: MMBT3904; SOT23
Q17: MMBT3906; SOT23
R96, R97, R98: 0 Ohm; R0805
R99, R100, R106, R107, R113: 1K,1%; R0805
R101, R102, R116: 150,1%; R0805
R103: 33K,1%; R0805
R104: 15K,1%; R0805
R105: 3K,1%; R0805
R108, R115, R120: 10,1%; R0805
R109: 49.9,1%; R0805
R110: 39K,1%; R0805
R111: 18K,1%; R0805
R112: 2.2K,1%; R0805
R114, R119: 100,1%; R0805
R117, R118: 3.3K,1%; R0805
SP1, SP3, SP6, SP7, SP8: SCOPE_PAD
U14: SI5351A; MSOP10
U15: SI570
U16: SA612A; SO-08
XTAL2: 25.000MHz; CTS-405
XTAL3, XTAL4: ECS-10.7-15B; HC49U

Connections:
1ST_LO: R96.1, R97.1, R98.1, SP6.1; also elsewhere on the board
3V3: FB13.1, FB14.1, FB15.1; also elsewhere on the board
+5V: FB16.2, FB17.1, FB19.2; also elsewhere on the board
AIN1: Q17.3 (C), R118.2, SP1.1; also elsewhere on the board
BBAMP: C144.1, J14.1
GND: C83.R1 (R), C83.R2 (R), C111.2, C112.2, C113.2, C114.2, C115.2, C120.2, C122.2, C125.1, C127.2, C129.2, C131.1, C132.1, C133.1, C134.2, C135.1, C136.2, J13.3, J13.4, J14.3, J14.4, L18.P$2 (2), R101.2, R102.2, R104.1, R106.1, R107.1, R109.1, R111.1, R113.1, R114.1, R118.1, SP1.2, SP3.2, SP6.2, SP7.2, SP8.2, U14.8 (GND), U15.3 (GND), U16.3 (GND), XTAL2.2, XTAL2.4, XTAL3.2, XTAL4.2; also elsewhere on the board
unnamed: U14.2 (XA), XTAL2.1
unnamed: C119.2, J13.1
unnamed: C114.1, FB15.2, U14.1 (VDD)
unnamed: C123.1, C124.2, J13.2, R109.2
unnamed: C124.1, C125.2, L19.P$2 (2), U16.2 (IN_B)
unnamed: U14.3 (XB), XTAL2.3
unnamed: C135.2, C144.2, L20.P$2 (2)
unnamed: C126.1, Q16.2 (E), R113.2
unnamed: C134.1, FB18.2, R117.2, R119.2, R120.2
unnamed: C127.1, R110.2, R112.2, R115.2
unnamed: J14.2, Q16.1 (B), R110.1, R111.2
unnamed: Q16.3 (C), Q17.1 (B), R112.1
unnamed: C130.2, Q17.2 (E), R117.1
unnamed: C129.1, FB18.1, R115.1
unnamed: C126.2, R114.2
unnamed: C130.1, R119.1
unnamed: C136.1, FB19.1, R120.1
unnamed: C111.1, FB13.2, U15.2 (OE), U15.6 (VDD)
unnamed: C113.1, FB14.2, U14.7 (VDDO)
unnamed: R96.2, U14.9 (CLK1)
unnamed: R97.2, U14.6 (CLK2)
unnamed: R98.2, U15.4 (CLK+)
unnamed: R99.2, R100.2, U14.10 (CLK0)
unnamed: C120.1, Q15.3 (C), R103.2, R105.2, R108.2
unnamed: C117.2, Q14.3 (C), Q15.1 (B), R105.1
unnamed: C122.1, FB16.1, R108.1
unnamed: C112.1, L17.P$2 (2), XTAL3.3
unnamed: C115.1, XTAL3.1, XTAL4.1
unnamed: C83.S, C117.1, L18.P$1 (1), XTAL4.3
unnamed: C118.1, Q14.1 (B), R103.1, R104.2
unnamed: C121.1, Q14.2 (E), R106.2
unnamed: C119.1, Q15.2 (E), R107.2
unnamed: C123.2, L19.P$1 (1), U16.1 (IN_A)
unnamed: FB17.2, R116.2
unnamed: C131.2, C133.2, R116.1, U16.8 (VIN)
unnamed: C128.2, U16.6 (OSC_B)
unnamed: C132.2, L20.P$1 (1), U16.4 (OUT_A)
RX-2ND-LO: C128.1, R100.1, R102.1, SP8.1
SCL3: U14.4 (SCL), U15.8 (SCL); also elsewhere on the board
SDA3: U14.5 (SDA), U15.7 (SDA); also elsewhere on the board
TIAOUT: L17.P$1 (1); also elsewhere on the board
TX-2ND-LO: C121.2, R99.1, R101.1, SP7.1
TX_DAC: C118.2, SP3.1; also elsewhere on the board

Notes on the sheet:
12/15/15
MERGE SM1000, TIA & BASEBAND_AMP SCHEMATICS
RGB
SM2000 -
L10 6T 6.25mm
L12 3T 6.25mm
L9 3T 6.25mm
L26 220nH,7T 6.25mm ID
L19 68nH,4.5T 5mm ID
L18 68nH,4.5T 5mm ID
L17 68nH,4.5T 5mm ID
L16 68nH,4.5T 5mm ID
L24 260nH 8T 6.25mm ID
L25 53nH,3T 5mm ID
L15 57nH, Air Core, 4T, 2mm ID
L14 57nH, Air Core, 4T, 2mm ID
1.7V
1.4V
2.4V
Z=50
Z=3000
Z=1500
XTAL 2ND MIXER
Notes
To PA1 ADC uC
From 2nd Rx Mixer NE602
1.5V
0.9V
BASEBAND_AMP
Mount LOs close to 1st mixer to minimise net length
LOCAL OSCILLATOR

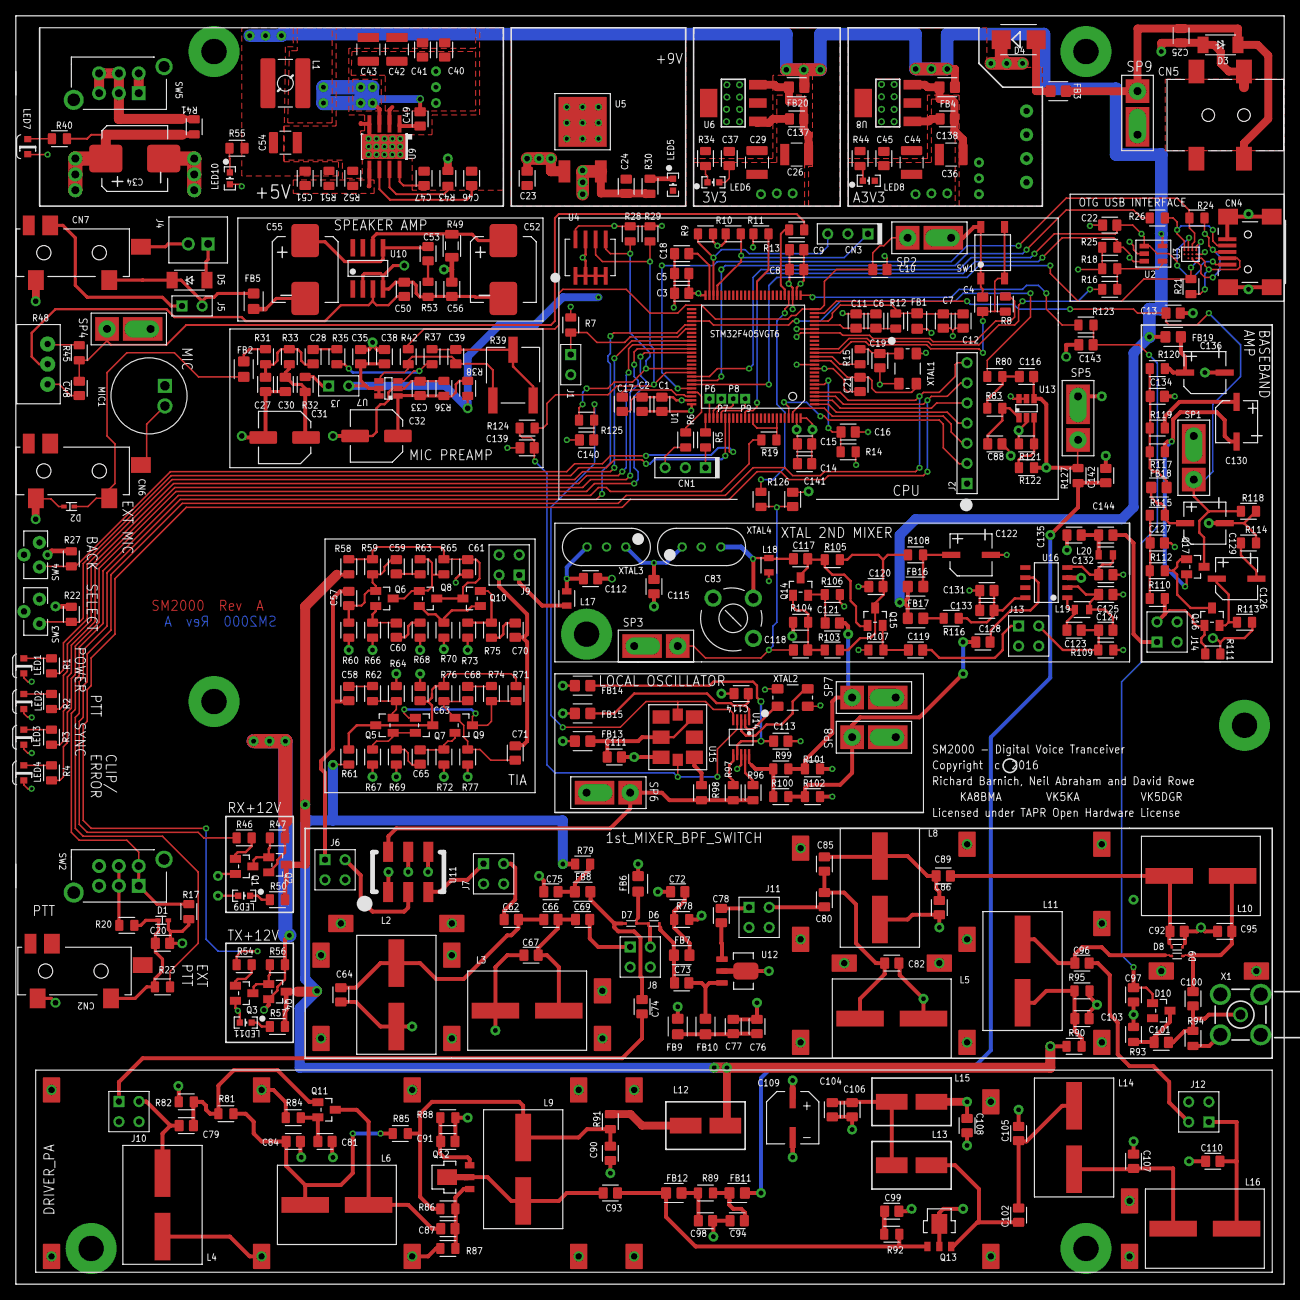
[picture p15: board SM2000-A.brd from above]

Board: 4 copper layers, 160.0 x 160.0 mm, 456 parts (0 on the bottom side), 227 nets.

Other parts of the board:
DRILEGEND: DRILEGEND

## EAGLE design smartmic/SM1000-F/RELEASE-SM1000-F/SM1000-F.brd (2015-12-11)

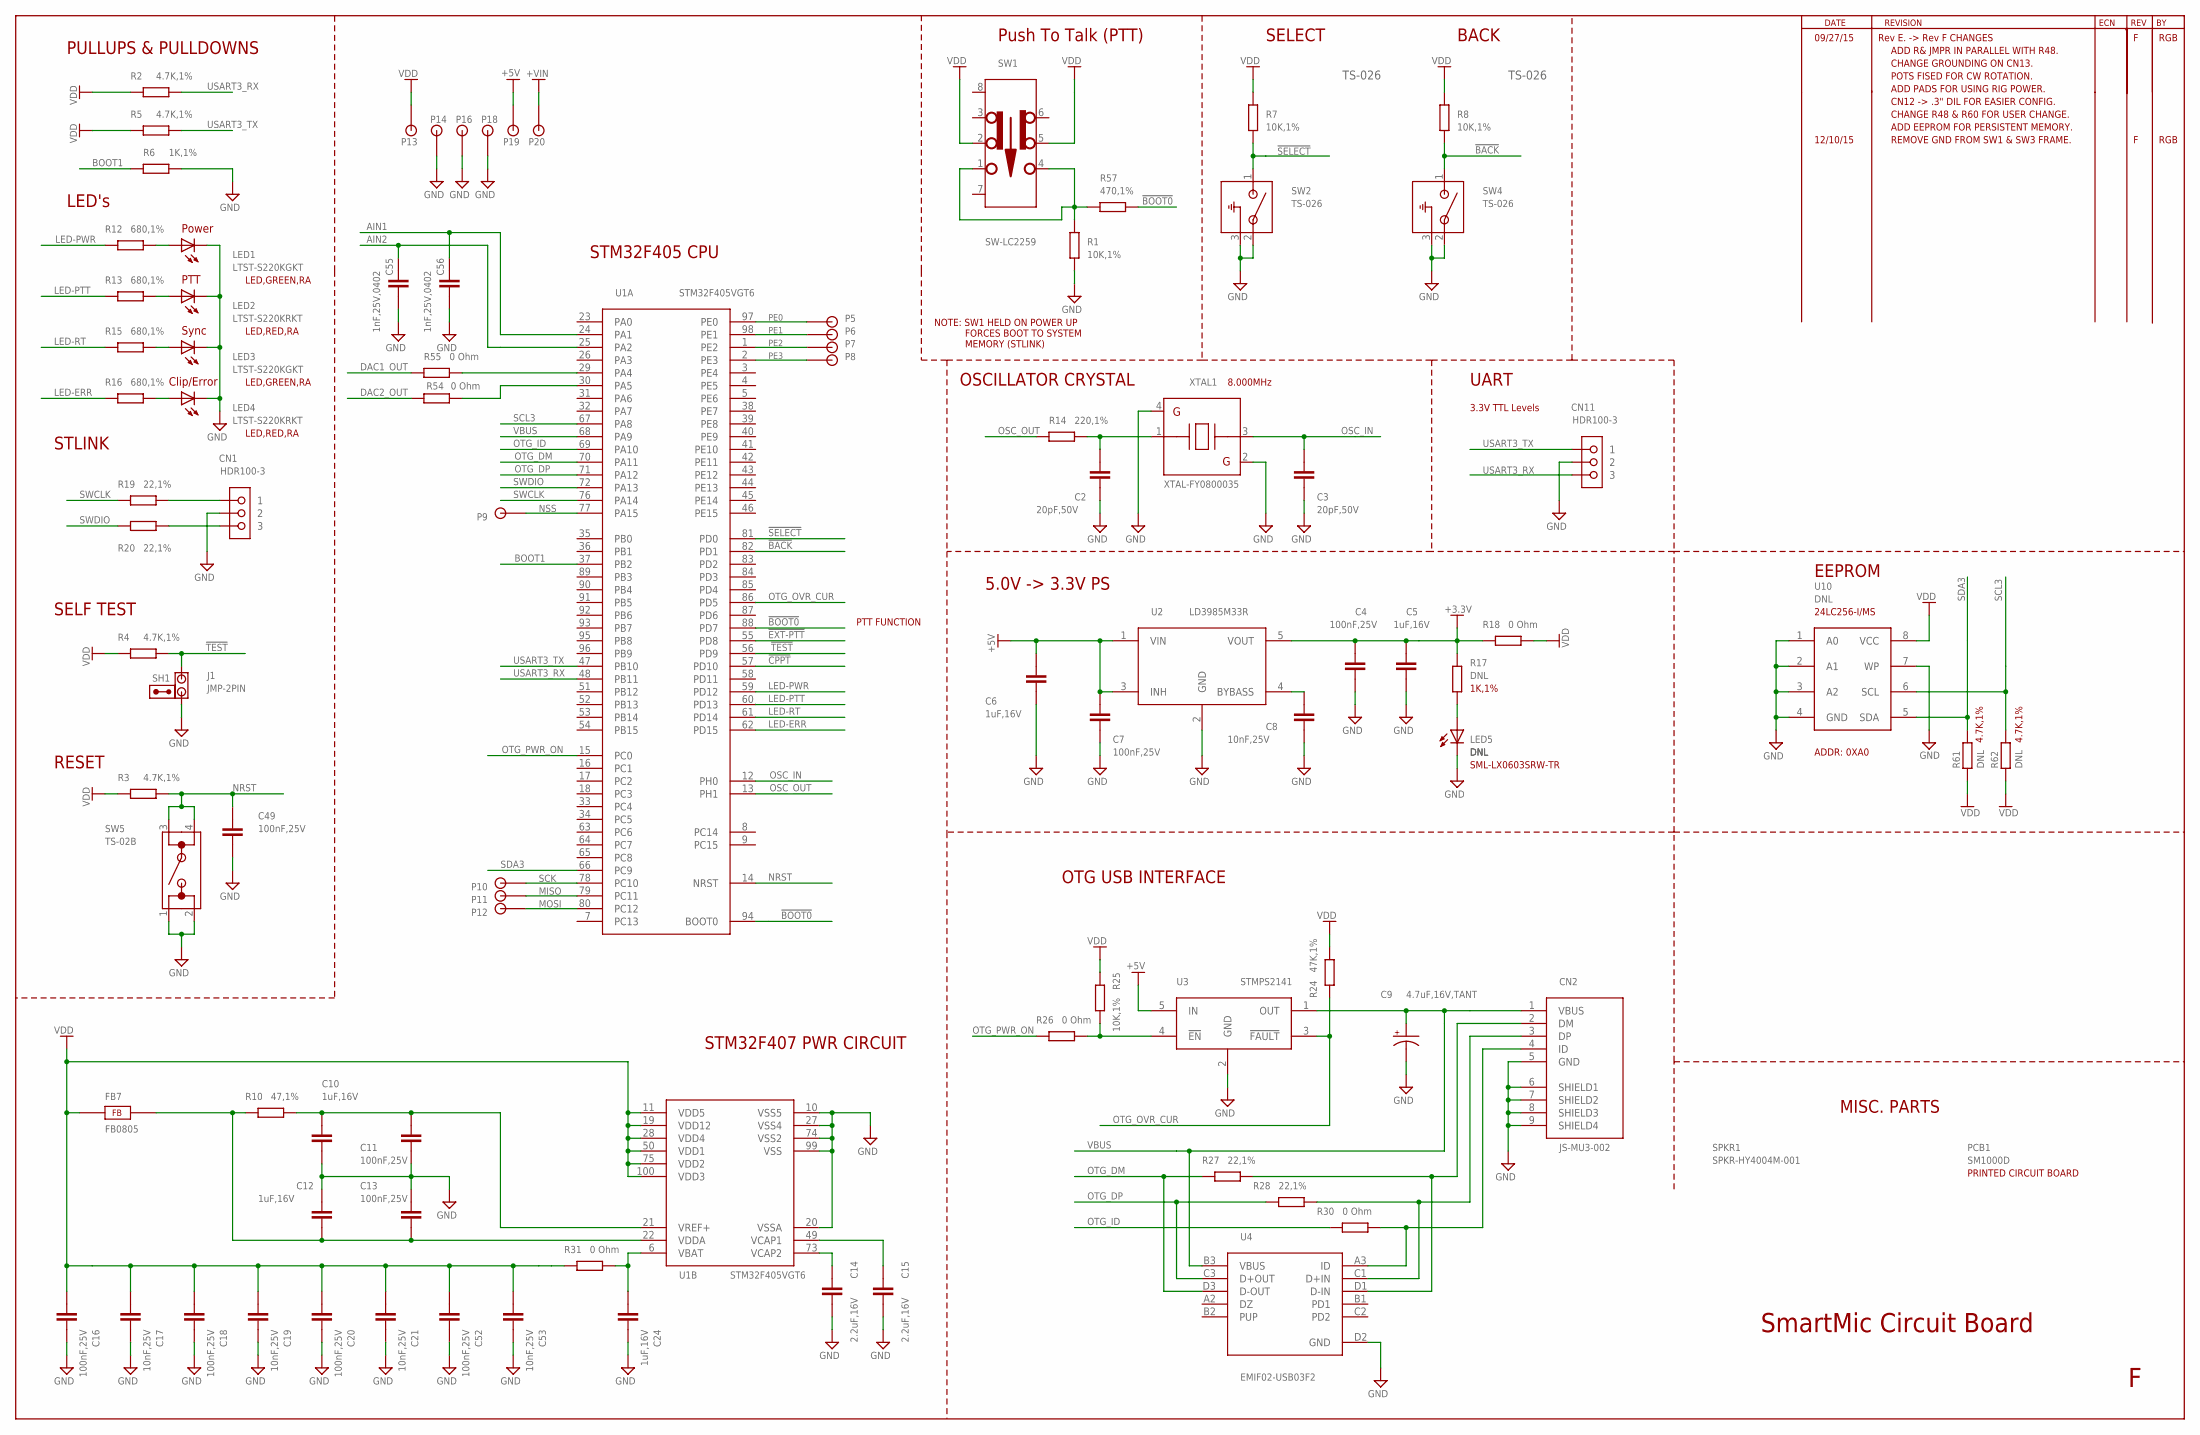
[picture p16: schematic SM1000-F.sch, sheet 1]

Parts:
C2, C3: 20pF,50V; CAPC1005X60N
C4, C7, C11, C13, C16, C18, C20, C49, C52: 100nF,25V; CAPC1005X60N
C5, C6, C10, C12, C24: 1uF,16V; CAPC1608X92N
C8, C17, C19, C21, C53: 10nF,25V; CAPC1005X60N
C9: 4.7uF,16V,TANT; C1206-TANT
C14, C15: 2.2uF,16V; CAPC1608X92N
C55, C56: 1nF,25V,0402; CAPC1005X60N
CN1, CN11: HDR100-3
CN2: JS-MU3-002; JI-MU3-002
FB7: FB0805; FE0805
J1: JMP-2PIN; JMPR-2PIN
LED1, LED3: LTST-S220KGKT; LTST-S2200K
LED2, LED4: LTST-S220KRKT; LTST-S2200K
LED5: DNL; SML-LX0603SRW
P5, P6, P7, P8, P9, P10, P11, P12, P13, P14, P16, P18, P19, P20: TPAD50
PCB1: SM1000D; NOPACKAGE
R1, R7, R8, R25: 10K,1%; RESC1005X40AN
R2, R3, R4, R5: 4.7K,1%; RESC1005X40AN
R6: 1K,1%; RESC1005X40AN
R10: 47,1%; RESC1608X55N
R12, R13, R15, R16: 680,1%; RESC1005X40AN
R14: 220,1%; RESC1005X40AN
R17: DNL; RESC1005X40AN
R18, R26, R30, R31, R54, R55: 0 Ohm; RESC1608X55N
R19, R20: 22,1%; RESC1608X55N
R24: 47K,1%; RESC1005X40AN
R27, R28: 22,1%; RESC1005X40AN
R57: 470,1%; RESC1005X40AN
R61, R62: DNL; RESC1608X55N
SH1: SHUNT,0.1IN; NOPACKAGE
SPKR1: SPKR-HY4004M-001; NOPACKAGE
SW1: SW-LC2259
SW2, SW4: TS-026
SW5: TS-02B
U1: STM32F405VGT6; LQFP100-14
U2: LD3985M33R; SOT23-5L
U3: STMPS2141; SOT23-5L
U4: EMIF02-USB03F2; ECOPACK-11
U10: DNL; SOIC8
XTAL1: XTAL-FY0800035

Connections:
!BACK!: R8.1, SW4.1, U1.82 (PD1)
!BOOT0!: R57.1, U1.88 (PD7), U1.94 (BOOT0)
!CPPT!: U1.57 (PD10); also elsewhere on the board
!EXT-PTT!: U1.55 (PD8); also elsewhere on the board
!SELECT!: R7.1, SW2.1, U1.81 (PD0)
!TEST!: J1.1, R4.2, U1.56 (PD9)
+3.3V: C4.1, C5.1, R17.2, R18.1, U2.5 (VOUT)
+5V: C6.1, C7.1, P19.1, U2.1 (VIN), U2.3 (INH), U3.5 (IN); also elsewhere on the board
+VIN: P20.1; also elsewhere on the board
AIN1: C56.1, U1.24 (PA1); also elsewhere on the board
AIN2: C55.1, U1.25 (PA2); also elsewhere on the board
BOOT1: R6.2, U1.37 (PB2)
DAC1_OUT: R55.2; also elsewhere on the board
DAC2_OUT: R54.2; also elsewhere on the board
GND: C2.2, C3.2, C4.2, C5.2, C6.2, C7.2, C8.2, C9.2, C10.2, C11.2, C12.2, C13.2, C14.2, C15.2, C16.2, C17.2, C18.2, C19.2, C20.2, C21.2, C24.2, C49.2, C52.2, C53.2, C55.2, C56.2, CN1.2, CN2.5 (GND), CN2.6 (SHIELD1), CN2.7 (SHIELD2), CN2.8 (SHIELD3), CN2.9 (SHIELD4), CN11.2, J1.2, LED1.C, LED2.C, LED3.C, LED4.C, LED5.C, P14.1, P16.1, P18.1, R1.1, R6.1, SW2.2, SW2.3, SW4.2, SW4.3, SW5.1, SW5.2, U1.10 (VSS5), U1.20 (VSSA), U1.27 (VSS4), U1.74 (VSS2), U1.99 (VSS), U2.2 (GND), U3.2 (GND), U4.D2 (GND), U10.1 (A0), U10.2 (A1), U10.3 (A2), U10.4 (GND), U10.7 (WP), XTAL1.2, XTAL1.4; also elsewhere on the board
LED-ERR: R16.1, U1.62 (PD15)
LED-PTT: R13.1, U1.60 (PD13)
LED-PWR: R12.1, U1.59 (PD12)
LED-RT: R15.1, U1.61 (PD14)
MISO: P11.1, U1.79 (PC11)
MOSI: P12.1, U1.80 (PC12)
unnamed: C14.1, U1.73 (VCAP2)
unnamed: C24.1, R31.2, U1.6 (VBAT)
unnamed: C15.1, U1.49 (VCAP1)
unnamed: C10.1, C11.1, R10.2, U1.21 (VREF+)
unnamed: C12.1, C13.1, FB7.2, R10.1, U1.22 (VDDA)
unnamed: CN1.3, R20.2
unnamed: CN1.1, R19.2
unnamed: C2.1, R14.2, XTAL1.1
unnamed: R55.1, U1.29 (PA4)
unnamed: C8.1, U2.4 (BYBASS)
unnamed: R54.1, U1.30 (PA5)
unnamed: R1.2, R57.2, SW1.1, SW1.4
unnamed: LED1.A, R12.2
unnamed: LED2.A, R13.2
unnamed: LED3.A, R15.2
unnamed: LED5.A, R17.1
unnamed: LED4.A, R16.2
unnamed: CN2.3 (DP), R28.1, U4.C1 (D+IN)
unnamed: CN2.2 (DM), R27.1, U4.D1 (D-IN)
unnamed: CN2.4 (ID), R30.1, U4.A3 (ID)
unnamed: R25.1, R26.2, U3.4 (!EN!)
NRST: C49.1, R3.2, SW5.3, SW5.4, U1.14 (NRST)
NSS: P9.1, U1.77 (PA15)
OSC_IN: C3.1, U1.12 (PH0), XTAL1.3
OSC_OUT: R14.1, U1.13 (PH1)
OTG_DM: R27.2, U1.70 (PA11), U4.D3 (D-OUT)
OTG_DP: R28.2, U1.71 (PA12), U4.C3 (D+OUT)
OTG_ID: R30.2, U1.69 (PA10)
OTG_OVR_CUR: R24.2, U1.86 (PD5), U3.3 (!FAULT!)
OTG_PWR_ON: R26.1, U1.15 (PC0)
PE0: P5.1, U1.97 (PE0)
PE1: P6.1, U1.98 (PE1)
PE2: P7.1, U1.1 (PE2)
PE3: P8.1, U1.2 (PE3)
SCK: P10.1, U1.78 (PC10)
SCL3: R62.2, U1.67 (PA8), U10.6 (SCL)
SDA3: R61.2, U1.66 (PC9), U10.5 (SDA)
SWCLK: R19.1, U1.76 (PA14)
SWDIO: R20.1, U1.72 (PA13)
USART3_RX: CN11.3, R2.2, U1.48 (PB11)
USART3_TX: CN11.1, R5.2, U1.47 (PB10)
VBUS: C9.1, CN2.1 (VBUS), U1.68 (PA9), U3.1 (OUT), U4.B3 (VBUS)
VDD: C16.1, C17.1, C18.1, C19.1, C20.1, C21.1, C52.1, C53.1, FB7.1, P13.1, R2.1, R3.1, R4.1, R5.1, R7.2, R8.2, R18.2, R24.1, R25.2, R31.1, R61.1, R62.1, SW1.2, SW1.5, U1.11 (VDD5), U1.19 (VDD12), U1.28 (VDD4), U1.50 (VDD1), U1.75 (VDD2), U1.100 (VDD3), U10.8 (VCC); also elsewhere on the board

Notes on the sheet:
PULLUPS & PULLDOWNS
LED's
STLINK
OSCILLATOR CRYSTAL
5.0V -> 3.3V PS
OTG USB INTERFACE
STM32F405 CPU
STM32F407 PWR CIRCUIT
SmartMic Circuit Board
Push To Talk (PTT)
PTT FUNCTION
NOTE: SW1 HELD ON POWER UP FORCES BOOT TO SYSTEM MEMORY (STLINK)
SELF TEST
RESET
SELECT
BACK
Power
PTT
Sync
Clip/Error
UART
3.3V TTL Levels
8.000MHz
TS-026
RGB
MISC. PARTS
LED,GREEN,RA
LED,RED,RA
1K,1%
SML-LX0603SRW-TR
DNL
EEPROM
ADDR: 0XA0
09/27/15
Rev E. -> Rev F CHANGES
ADD R& JMPR IN PARALLEL WITH R48.
CHANGE GROUNDING ON CN13.
POTS FISED FOR CW ROTATION.
ADD PADS FOR USING RIG POWER.
CN12 -> .3" DIL FOR EASIER CONFIG.

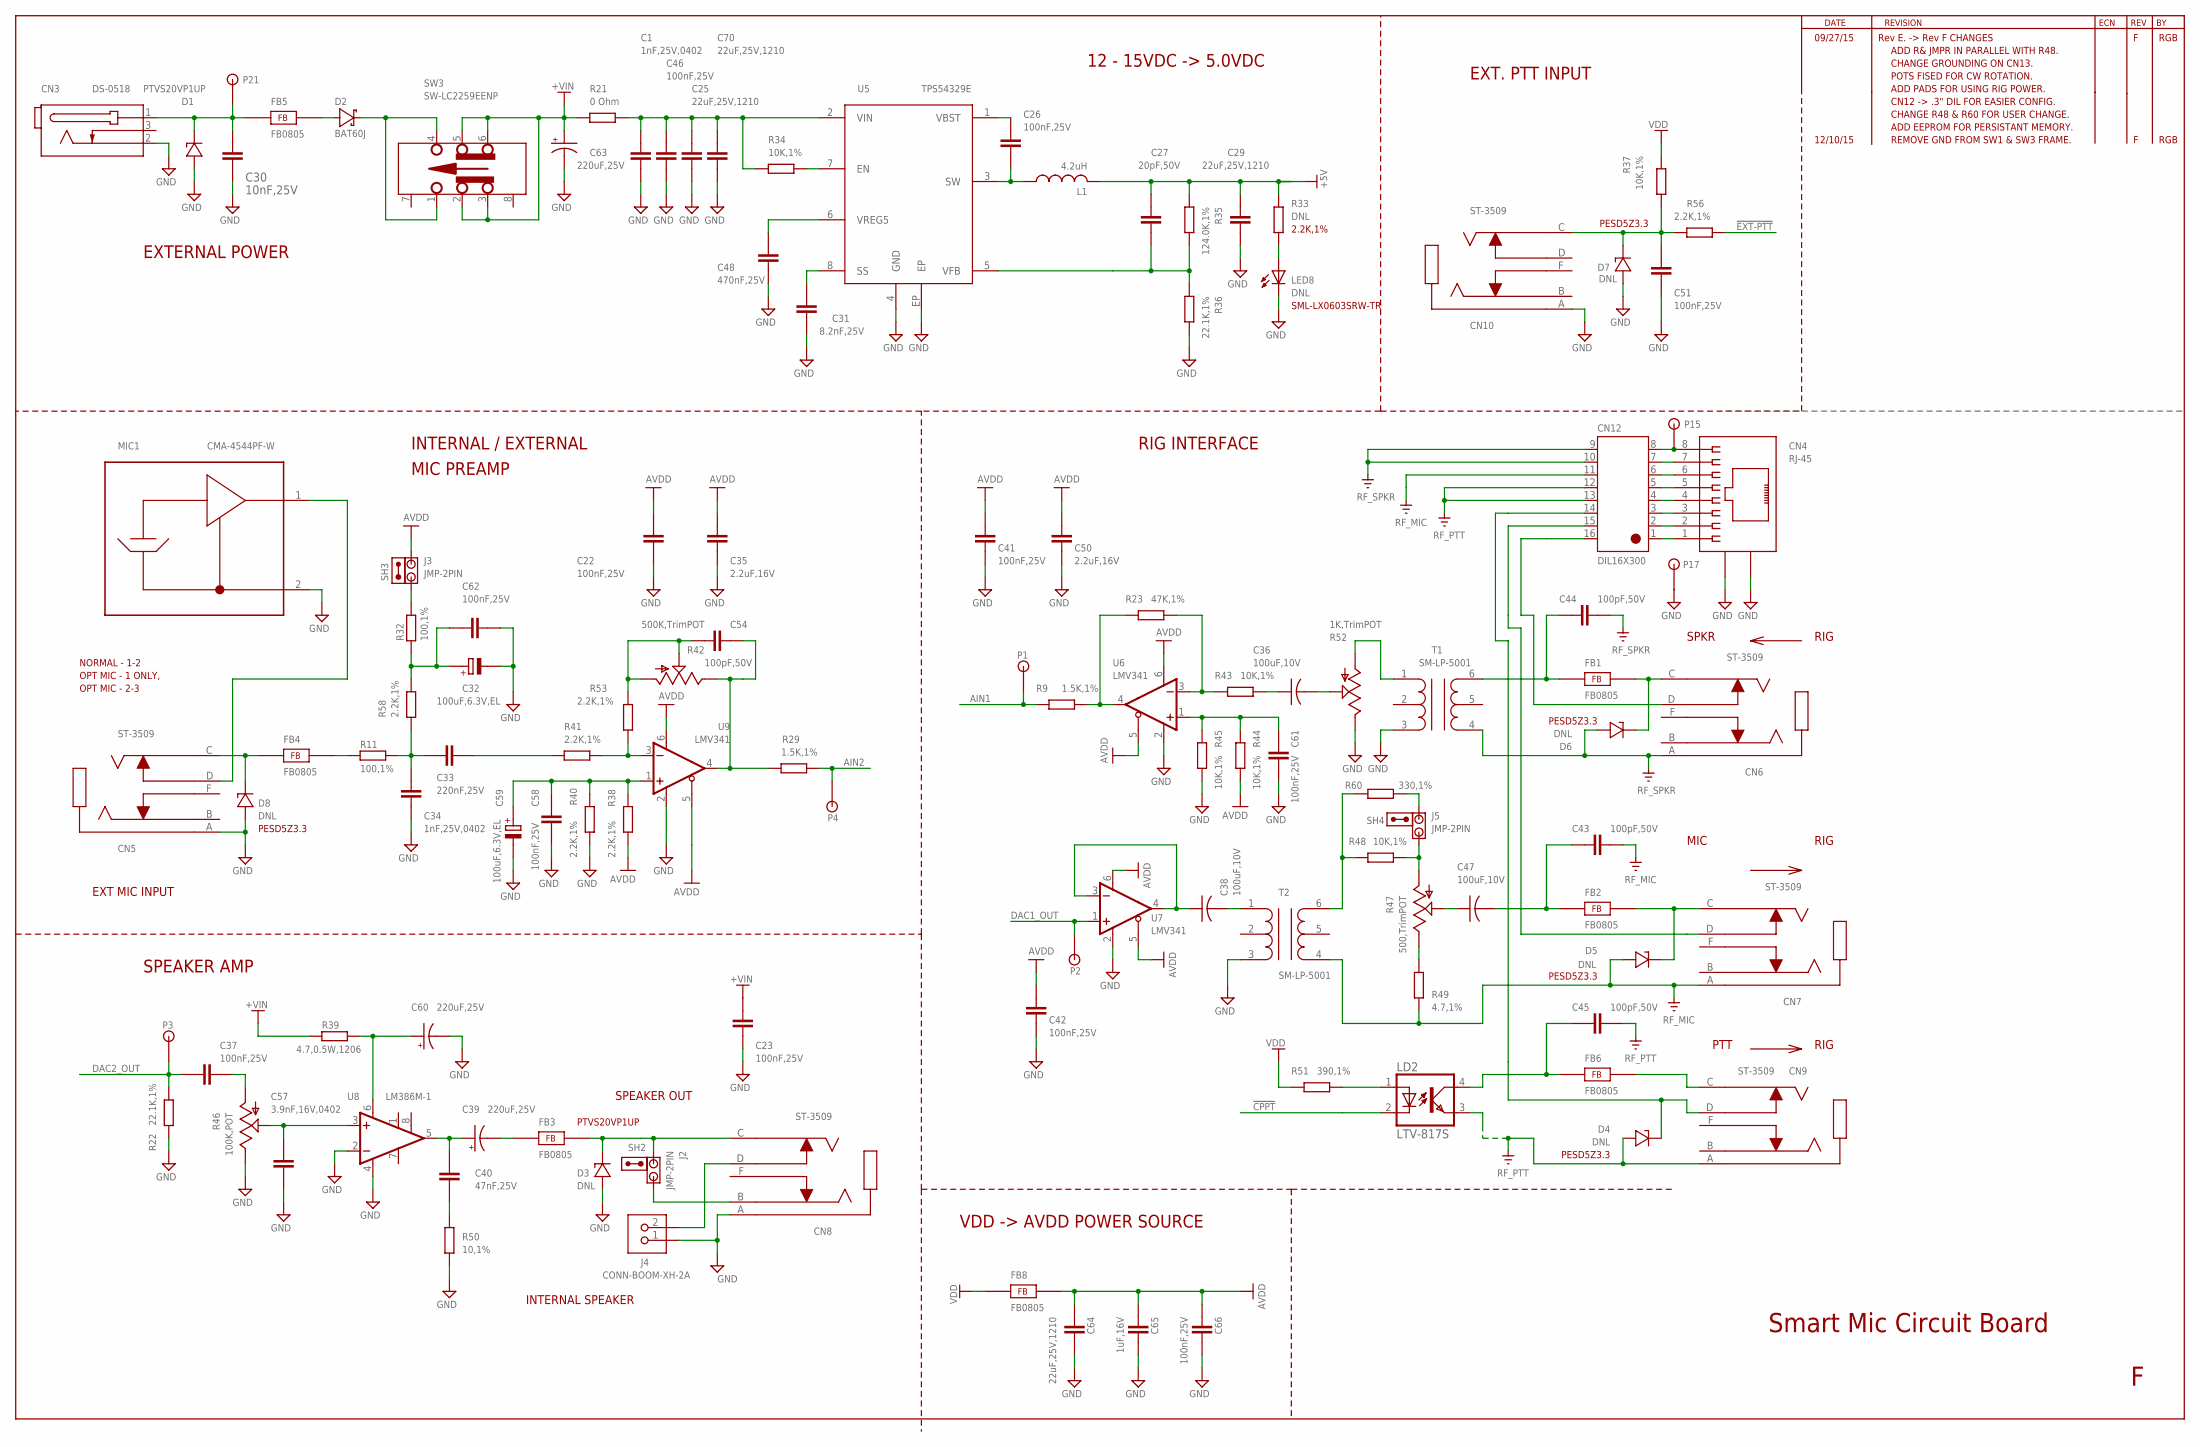
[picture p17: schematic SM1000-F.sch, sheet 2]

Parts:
C1, C34: 1nF,25V,0402; CAPC1005X60N
C22, C23, C26, C37, C41, C42, C46, C51, C58, C61, C62, C66: 100nF,25V; CAPC1005X60N
C25, C29, C64, C70: 22uF,25V,1210; CAPC3225X168N
C27: 20pF,50V; CAPC1005X60N
C30: 10nF,25V; CAPC1005X60N
C31: 8.2nF,25V; CAPC1608X92N
C32, C59: 100uF,6.3V,EL; NICHICON-WX-6.3
C33: 220nF,25V; CAPC1005X60N
C35, C50: 2.2uF,16V; CAPC1608X92N
C36, C38, C47: 100uF,10V; C1210
C39, C60, C63: 220uF,25V; CAP-CHEMI-HA0
C40: 47nF,25V; CAPC1005X60N
C43, C44, C45, C54: 100pF,50V; CAPC1005X60N
C48: 470nF,25V; CAPC1608X92N
C57: 3.9nF,16V,0402; CAPC1005X60N
C65: 1uF,16V; CAPC1608X92N
CN3: DS-0518
CN4: RJ-45; CONN-RJ45-MOLEX-44144-003
CN5, CN6, CN7, CN8, CN9, CN10: ST-3509
CN12: DIL16X300
D1: PTVS20VP1UP; SOD128
D2: BAT60J; SOD323R_INFINEON
D3: DNL; SOD128
D4, D5, D6, D7, D8: DNL; SOD523
FB1, FB2, FB3, FB4, FB5, FB6, FB8: FB0805; FE0805
J2, J3, J5: JMP-2PIN; JMPR-2PIN
J4: CONN-BOOM-XH-2A
L1: 4.2uH; SRR5028
LD2: LTV-817S
LED8: DNL; SML-LX0603SRW
MIC1: CMA-4544PF-W
P1, P2, P3, P4, P15, P17, P21: TPAD50
R9, R29: 1.5K,1%; RESC1005X40AN
R11, R32: 100,1%; RESC1608X55N
R21: 0 Ohm; RESC1608X55N
R22: 22.1K,1%; RESC1608X55N
R23: 47K,1%; RESC1005X40AN
R33: DNL; RESC1005X40AN
R34, R37, R43, R44, R45: 10K,1%; RESC1005X40AN
R35: 124.0K,1%; RESC1005X40AN
R36: 22.1K,1%; RESC1005X40AN
R38, R40, R41, R53, R56, R58: 2.2K,1%; RESC1005X40AN
R39: 4.7,0.5W,1206; RESC3115X70N
R42: 500K,TrimPOT; POT3361
R46: 100K,POT; POT-3310C
R47: 500,TrimPOT; POT3361
R48: 10K,1%; RESC3115X70N
R49: 4.7,1%; RESC1005X40AN
R50: 10,1%; RESC1608X55N
R51: 390,1%; RESC1005X40AN
R52: 1K,TrimPOT; POT3361
R60: 330,1%; RESC3115X70N
SH2, SH3, SH4: SHUNT,0.1IN; NOPACKAGE
SW3: SW-LC2259EENP; SW-LC2259
T1, T2: SM-LP-5001
U5: TPS54329E; PSO-DDA
U6, U7, U9: LMV341; SOT23-6
U8: LM386M-1; SO08

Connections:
!CPPT!: LD2.2 (C); also elsewhere on the board
!EXT-PTT!: R56.2; also elsewhere on the board
+5V: C27.1, C29.1, L1.2, R33.1, R35.1; also elsewhere on the board
+VIN: C23.1, C63.1, R21.1, R39.1, SW3.2, SW3.3, SW3.5, SW3.6; also elsewhere on the board
AIN1: P1.1, R9.1; also elsewhere on the board
AIN2: P4.1, R29.1; also elsewhere on the board
APTT: CN9.D, CN12.14, D4.C
AVDD: C22.1, C35.1, C41.1, C42.1, C50.1, C64.1, C65.1, C66.1, FB8.2, J3.2, R38.2, R44.2, U6.5 (!SHDN!), U6.6 (V+), U7.5 (!SHDN!), U7.6 (V+), U9.5 (!SHDN!), U9.6 (V+)
DAC1_OUT: P2.1, U7.1 (+IN); also elsewhere on the board
DAC2_OUT: C37.1, P3.1, R22.1; also elsewhere on the board
GND: C1.1, C22.2, C23.2, C25.2, C29.2, C30.2, C31.2, C32.2 (-), C34.2, C35.2, C41.2, C42.2, C46.2, C48.2, C50.2, C51.2, C57.2, C58.1, C59.2 (-), C60.2, C61.2, C62.2, C63.2, C64.2, C65.2, C66.2, C70.2, CN3.2, CN4.9, CN4.10, CN5.A, CN8.A, CN10.A, D1.A, D3.A, D7.A, D8.A, J4.1, LED8.C, MIC1.2, P17.1, R22.2, R36.2, R40.2, R45.2, R46.1, R50.2, R52.1, T1.3, T2.3, U5.4 (GND), U5.EP, U6.2 (GND), U7.2 (GND), U8.2 (-IN), U8.4 (GND), U9.2 (GND); also elsewhere on the board
MIC: CN7.D, CN12.15
unnamed: C39.1, C40.1, U8.5 (OUT)
unnamed: C36.2, R52.2
unnamed: C51.1, CN10.C, D7.C, R37.2, R56.1
unnamed: C26.1, U5.1 (VBST)
unnamed: D2.A, FB5.2
unnamed: C33.1, C34.1, R11.2, R58.1
unnamed: FB4.2, R11.1
unnamed: C54.2, R29.2, R42.1, U9.4 (OUT)
unnamed: J3.1, R32.2
unnamed: C27.2, R35.2, R36.1, U5.5 (VFB)
unnamed: R23.2, R43.1, U6.3 (-IN)
unnamed: C44.1, FB1.1, T1.6
unnamed: C37.2, R46.3
unnamed: C33.2, R41.1
unnamed: C1.2, C25.1, C46.1, C70.1, R21.2, R34.1, U5.2 (VIN)
unnamed: R9.2, R23.1, U6.4 (OUT)
unnamed: C31.1, U5.8 (SS)
unnamed: C57.1, R46.2, U8.3 (+IN)
unnamed: C48.1, U5.6 (VREG5)
unnamed: C54.1, R42.2, R42.3, R53.2
unnamed: R34.2, U5.7 (EN)
unnamed: C40.2, R50.1
unnamed: C39.2, FB3.1
unnamed: C32.1 (+), C62.1, R32.1, R58.2
unnamed: C58.2, C59.1 (+), R38.1, R40.1, U9.1 (+IN)
unnamed: LED8.A, R33.2
unnamed: C60.1, R39.2, U8.6 (VS)
unnamed: LD2.1 (A), R51.1
unnamed: C36.1, R43.2
unnamed: CN4.8, CN12.8, P15.1
unnamed: CN4.7, CN12.7
unnamed: CN4.6, CN12.6
unnamed: CN4.5, CN12.5
unnamed: CN4.4, CN12.4
unnamed: CN4.3, CN12.3
unnamed: CN4.2, CN12.2
unnamed: CN4.1, CN12.1
unnamed: C61.1, R44.1, R45.1, U6.1 (+IN)
unnamed: CN5.D, MIC1.1
unnamed: R47.1, R49.2
unnamed: CN8.C, D3.C, FB3.2, J2.2
unnamed: R52.3, T1.1
unnamed: CN8.B, J2.1
unnamed: C38.2, T2.1
unnamed: CN7.C, D5.C, FB2.2
unnamed: C38.1, U7.3 (-IN), U7.4 (OUT)
unnamed: CN8.D, J4.2
unnamed: CN9.C, FB6.2
unnamed: C45.1, FB6.1, LD2.4 (COL)
unnamed: J5.2, R60.1
unnamed: CN5.C, D8.C, FB4.1
unnamed: C30.1, CN3.1, D1.C, FB5.1, P21.1
unnamed: R48.2, R60.2, T2.6
unnamed: C43.1, C47.2, FB2.1
unnamed: C47.1, R47.2
unnamed: D2.C, SW3.1, SW3.4
unnamed: J5.1, R47.3, R48.1
unnamed: CN6.C, D6.C, FB1.2
unnamed: R41.2, R53.1, U9.3 (-IN)
RF_MIC: C43.2, CN7.A, CN12.11, D5.A, R49.1, T2.4
RF_PTT: C45.2, CN9.A, CN12.12, CN12.13, D4.A, LD2.3 (EMIT)
RF_SPKR: C44.2, CN6.A, CN12.9, CN12.10, D6.A, T1.4
SPKR: CN6.D, CN12.16
SW: C26.2, L1.1, U5.3 (SW)
VDD: FB8.1, R37.1, R51.2; also elsewhere on the board

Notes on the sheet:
SPKR
MIC
RIG
SPEAKER OUT
PTT
EXT MIC INPUT
EXTERNAL POWER
12 - 15VDC -> 5.0VDC
INTERNAL / EXTERNAL
MIC PREAMP
SPEAKER AMP
RIG INTERFACE
Smart Mic Circuit Board
NORMAL - 1-2
OPT MIC - 1 ONLY,
OPT MIC - 2-3
EXT. PTT INPUT
INTERNAL SPEAKER
VDD -> AVDD POWER SOURCE
2.2K,1%
SML-LX0603SRW-TR
PESD5Z3.3
PTVS20VP1UP
09/27/15
Rev E. -> Rev F CHANGES
ADD R& JMPR IN PARALLEL WITH R48.
CHANGE GROUNDING ON CN13.
POTS FISED FOR CW ROTATION.
ADD PADS FOR USING RIG POWER.
CN12 -> .3" DIL FOR EASIER CONFIG.
CHANGE R48 & R60 FOR USER CHANGE.
RGB
ADD EEPROM FOR PERSISTANT MEMORY.
REMOVE GND FROM SW1 & SW3 FRAME.
12/10/15

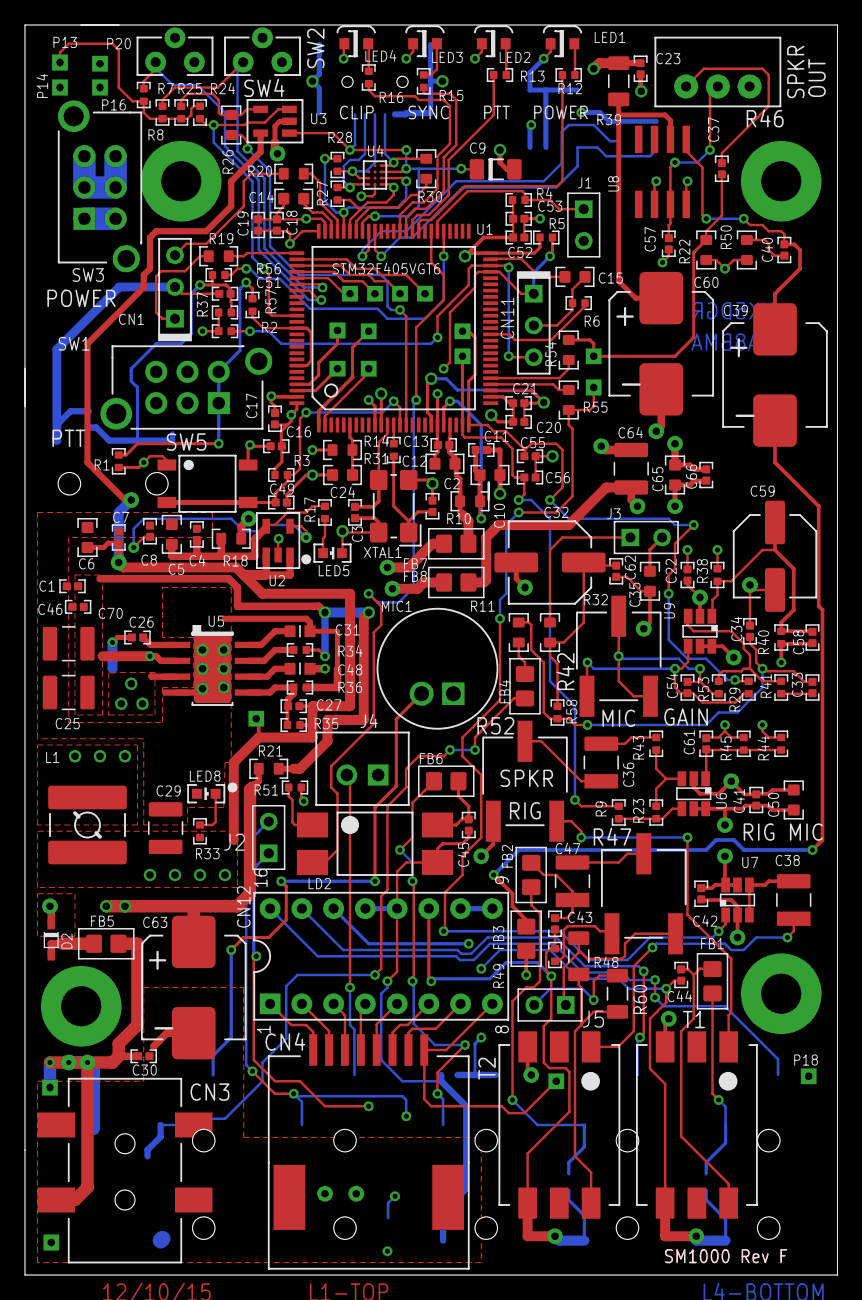
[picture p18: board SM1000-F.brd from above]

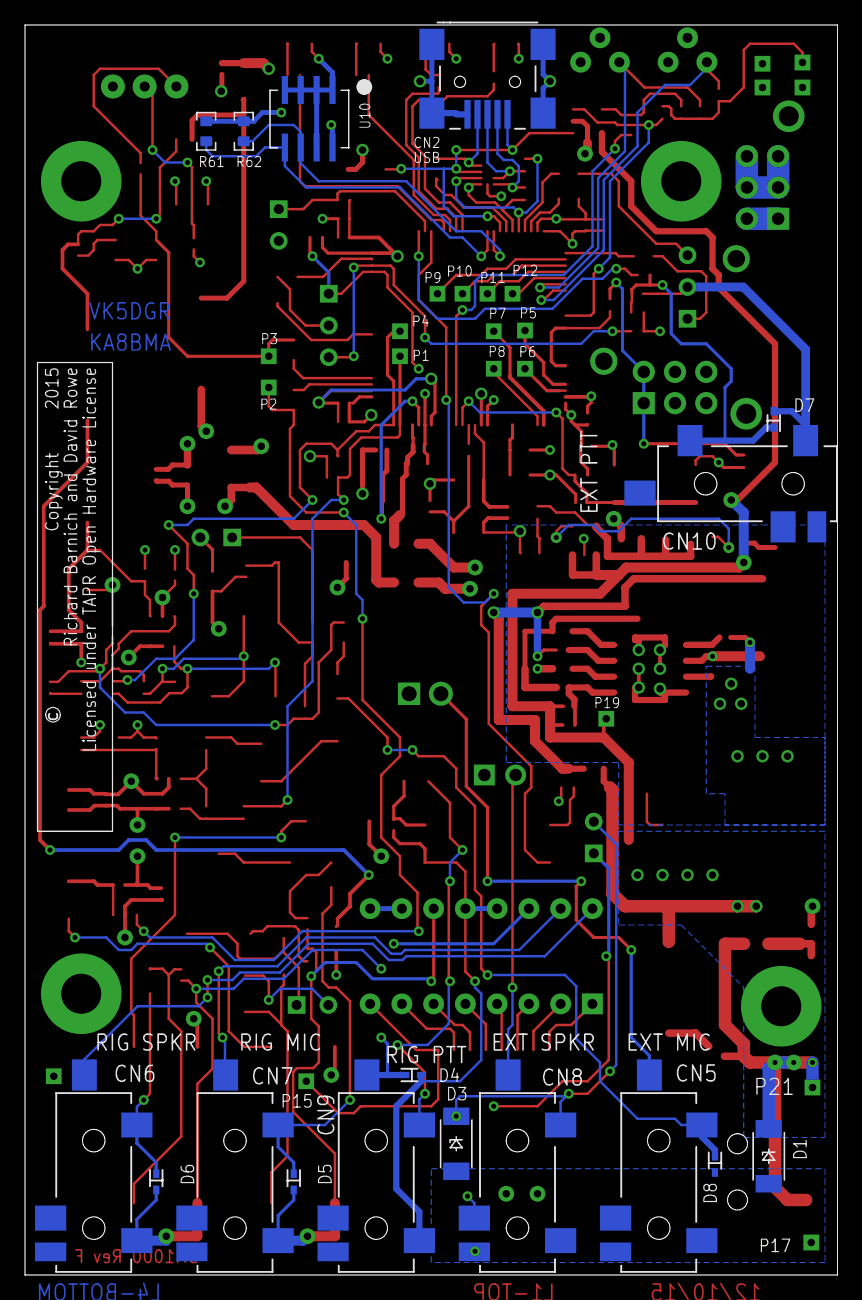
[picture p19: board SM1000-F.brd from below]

Board: 4 copper layers, 65.0 x 100.0 mm, 216 parts (33 on the bottom side), 131 nets.

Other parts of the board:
DRILEGEND: DRILEGEND
U$4: SWPS-OTL

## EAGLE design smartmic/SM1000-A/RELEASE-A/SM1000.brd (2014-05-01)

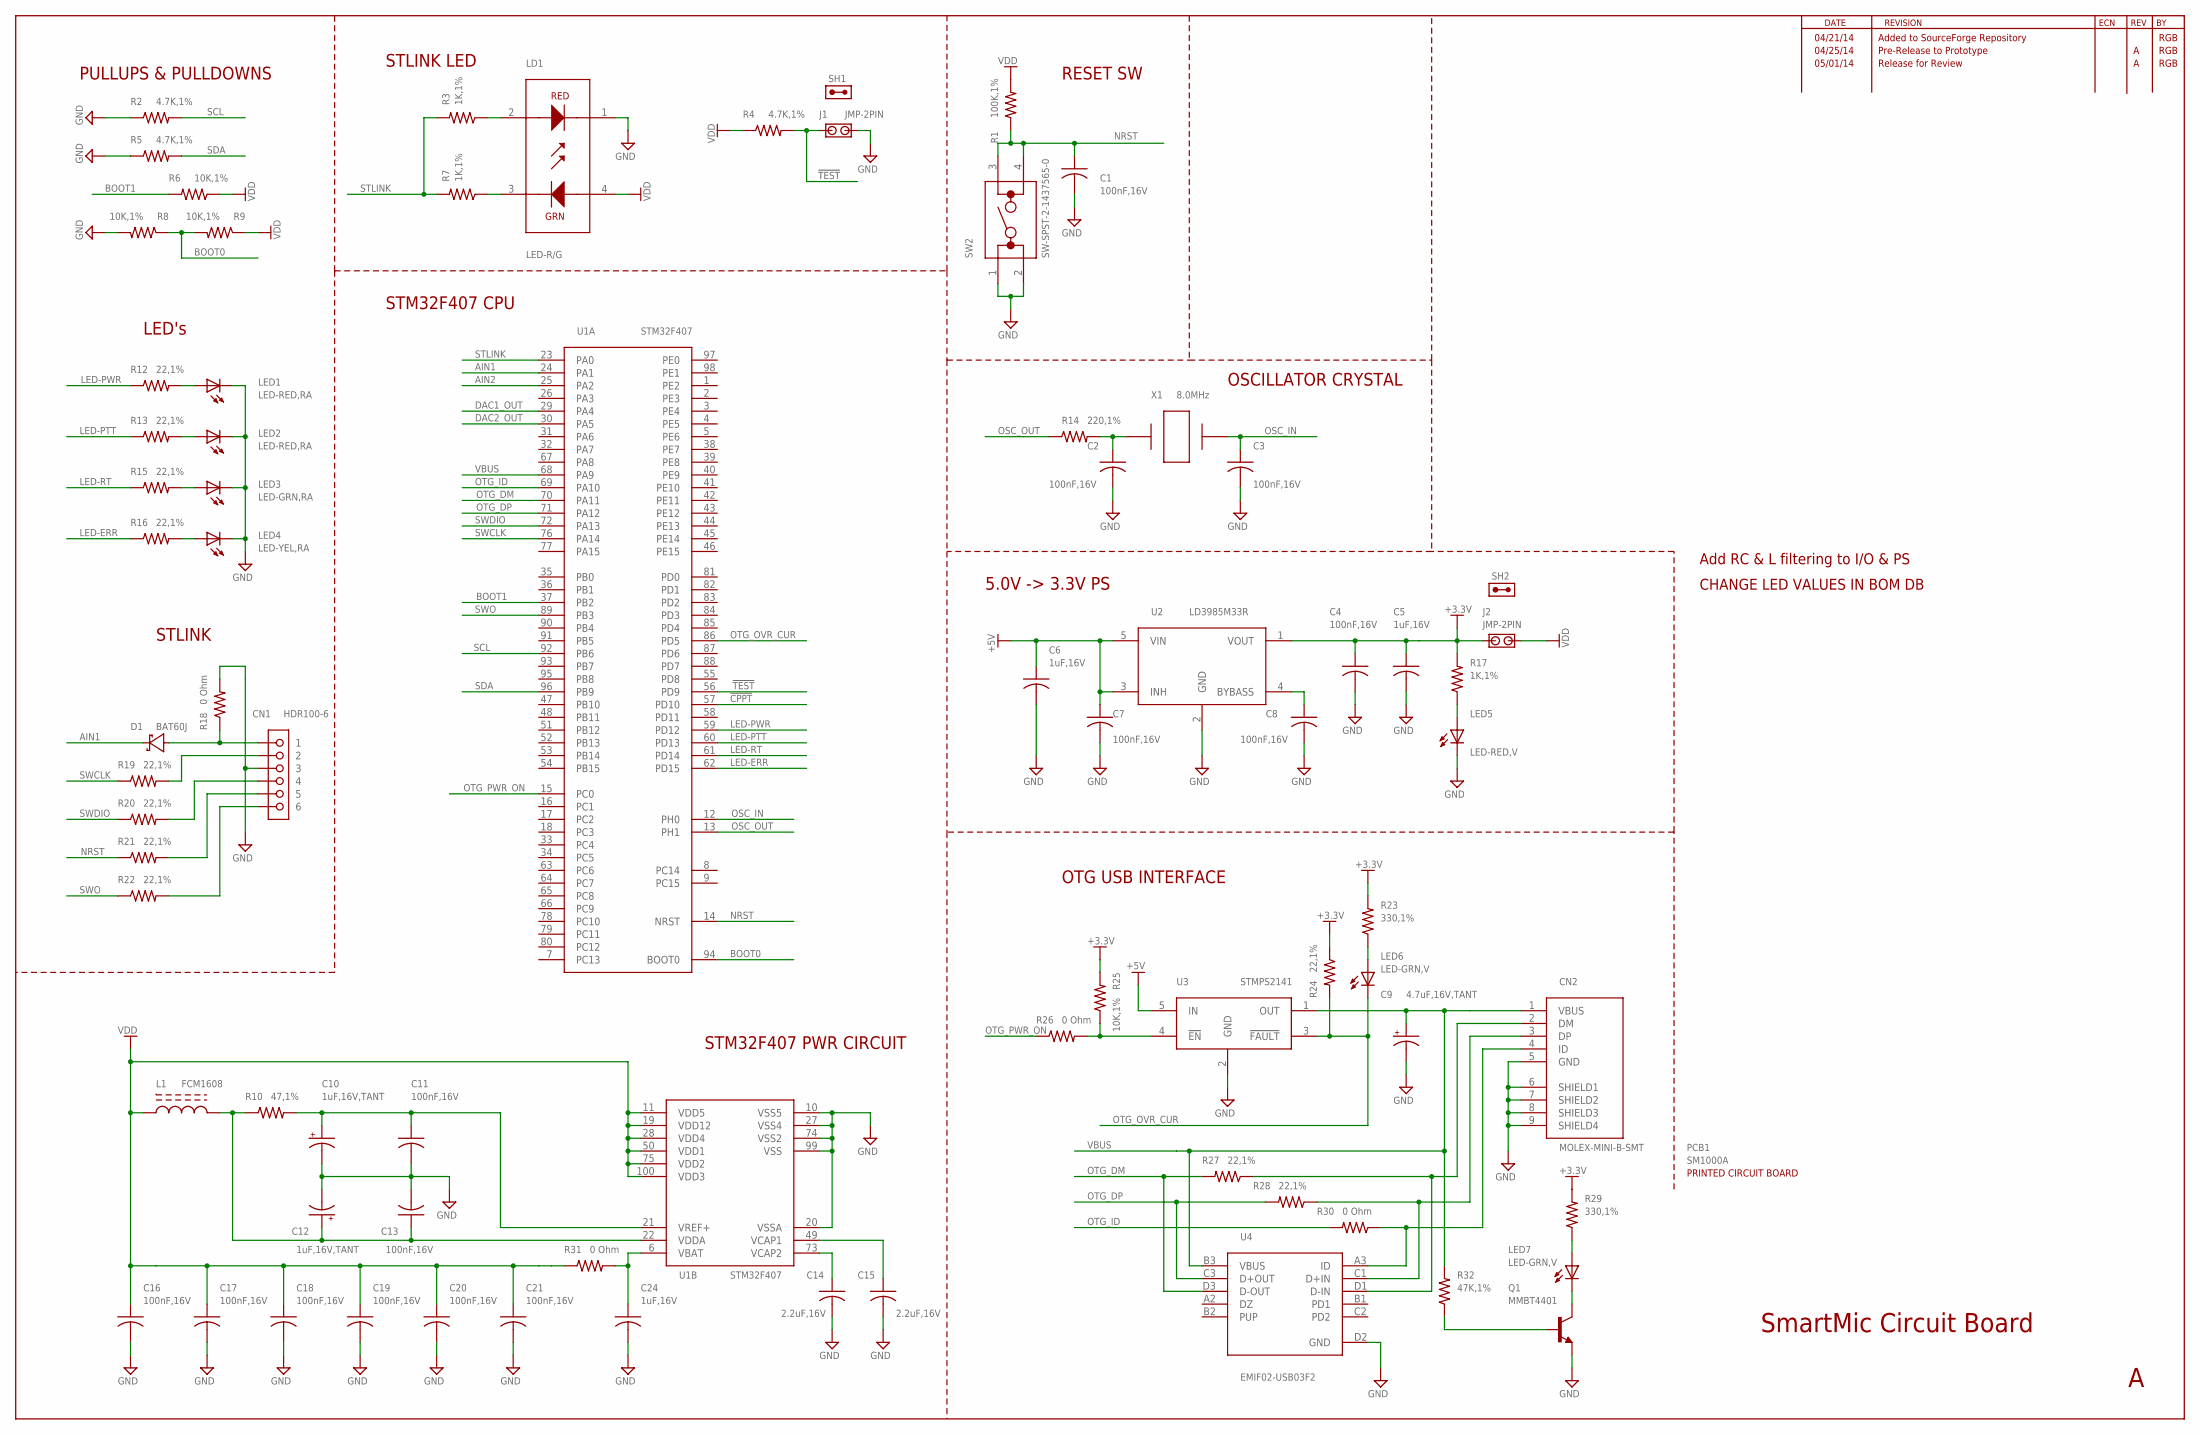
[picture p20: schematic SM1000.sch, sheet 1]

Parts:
C1, C2, C3, C4, C7, C8, C11, C13, C16, C17, C18, C19, C20, C21: 100nF,16V; C0603
C5, C6, C24: 1uF,16V; C0603
C9: 4.7uF,16V,TANT; C1206-TANT
C10, C12: 1uF,16V,TANT; C1206-TANT
C14, C15: 2.2uF,16V; C0805
CN1: HDR100-6
CN2: MOLEX-MINI-B-SMT
D1: BAT60J; SOD323R_INFINEON
J1, J2: JMP-2PIN; JMPR-2PIN
L1: FCM1608
LD1: LED-R/G
LED1, LED2: LED-RED,RA; LTST-S2200K
LED3: LED-GRN,RA; LTST-S2200K
LED4: LED-YEL,RA; LTST-S2200K
LED5: LED-RED,V; CHIP-LED-0603
LED6, LED7: LED-GRN,V; CHIP-LED-0603
PCB1: SM1000A; NOPACKAGE
Q1: MMBT4401; SOT23
R1: 100K,1%; R0603
R2, R4, R5: 4.7K,1%; R0603
R3, R7, R17: 1K,1%; R0603
R6, R8, R9, R25: 10K,1%; R0603
R10: 47,1%; R0603
R12, R13, R15, R16, R19, R20, R21, R22, R24, R27, R28: 22,1%; R0603
R14: 220,1%; R0603
R18, R26, R30, R31: 0 Ohm; R0603
R23, R29: 330,1%; R0603
R32: 47K,1%; R0603
SH1, SH2: SHUNT,0.1IN; NOPACKAGE
SW2: SW-SPST-2-1437565-0; SW-SPST-TE-2-1437565-0
U1: STM32F407; LQFP100-14
U2: LD3985M33R; SOT23-5L
U3: STMPS2141; SOT23-5L
U4: EMIF02-USB03F2; ECOPACK-11
X1: 8.0MHz; HC49-SMT

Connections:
!CPPT!: U1.57 (PD10); also elsewhere on the board
!TEST!: J1.1, R4.2, U1.56 (PD9)
+3.3V: C4.1, C5.1, J2.1, R17.2, R23.2, R24.1, R25.2, R29.2, U2.1 (VOUT)
+5V: C6.1, C7.1, U2.3 (INH), U2.5 (VIN), U3.5 (IN); also elsewhere on the board
AIN1: D1.C, U1.24 (PA1)
AIN2: U1.25 (PA2); also elsewhere on the board
BOOT0: R8.1, R9.2, U1.94 (BOOT0)
BOOT1: R6.2, U1.37 (PB2)
DAC1_OUT: U1.29 (PA4); also elsewhere on the board
DAC2_OUT: U1.30 (PA5); also elsewhere on the board
GND: C1.2, C2.2, C3.2, C4.2, C5.2, C6.2, C7.2, C8.2, C9.2, C10.2, C11.2, C12.2, C13.2, C14.2, C15.2, C16.2, C17.2, C18.2, C19.2, C20.2, C21.2, C24.2, CN1.3, CN2.5 (GND), CN2.6 (SHIELD1), CN2.7 (SHIELD2), CN2.8 (SHIELD3), CN2.9 (SHIELD4), J1.2, LD1.1, LED1.C, LED2.C, LED3.C, LED4.C, LED5.C, Q1.2 (E), R2.1, R5.1, R8.2, R18.2, SW2.1, SW2.2, U1.10 (VSS5), U1.20 (VSSA), U1.27 (VSS4), U1.74 (VSS2), U1.99 (VSS), U2.2 (GND), U3.2 (GND), U4.D2 (GND); also elsewhere on the board
LED-ERR: R16.1, U1.62 (PD15)
LED-PTT: R13.1, U1.60 (PD13)
LED-PWR: R12.1, U1.59 (PD12)
LED-RT: R15.1, U1.61 (PD14)
unnamed: C14.1, U1.73 (VCAP2)
unnamed: C24.1, R31.2, U1.6 (VBAT)
unnamed: C15.1, U1.49 (VCAP1)
unnamed: C10.1, C11.1, R10.2, U1.21 (VREF+)
unnamed: C12.1, C13.1, L1.2, R10.1, U1.22 (VDDA)
unnamed: CN1.1, D1.A, R18.1
unnamed: CN1.2, R19.2
unnamed: CN1.4, R20.2
unnamed: CN1.5, R21.2
unnamed: C2.1, R14.2, X1.1
unnamed: CN1.6, R22.2
unnamed: C8.1, U2.4 (BYBASS)
unnamed: LD1.2, R3.1
unnamed: LD1.3, R7.1
unnamed: Q1.1 (B), R32.1
unnamed: LED1.A, R12.2
unnamed: LED2.A, R13.2
unnamed: LED3.A, R15.2
unnamed: LED5.A, R17.1
unnamed: LED4.A, R16.2
unnamed: CN2.3 (DP), R28.1, U4.C1 (D+IN)
unnamed: CN2.2 (DM), R27.1, U4.D1 (D-IN)
unnamed: LED7.C, Q1.3 (C)
unnamed: LED7.A, R29.1
unnamed: CN2.4 (ID), R30.1, U4.A3 (ID)
unnamed: LED6.A, R23.1
unnamed: R25.1, R26.2, U3.4 (!EN!)
NRST: C1.1, R1.1, R21.1, SW2.3, SW2.4, U1.14 (NRST)
OSC_IN: C3.1, U1.12 (PH0), X1.2
OSC_OUT: R14.1, U1.13 (PH1)
OTG_DM: R27.2, U1.70 (PA11), U4.D3 (D-OUT)
OTG_DP: R28.2, U1.71 (PA12), U4.C3 (D+OUT)
OTG_ID: R30.2, U1.69 (PA10)
OTG_OVR_CUR: LED6.C, R24.2, U1.86 (PD5), U3.3 (!FAULT!)
OTG_PWR_ON: R26.1, U1.15 (PC0)
SCL: R2.2, U1.92 (PB6)
SDA: R5.2, U1.96 (PB9)
STLINK: R3.2, R7.2, U1.23 (PA0)
SWCLK: R19.1, U1.76 (PA14)
SWDIO: R20.1, U1.72 (PA13)
SWO: R22.1, U1.89 (PB3)
VBUS: C9.1, CN2.1 (VBUS), R32.2, U1.68 (PA9), U3.1 (OUT), U4.B3 (VBUS)
VDD: C16.1, C17.1, C18.1, C19.1, C20.1, C21.1, J2.2, L1.1, LD1.4, R1.2, R4.1, R6.1, R9.1, R31.1, U1.11 (VDD5), U1.19 (VDD12), U1.28 (VDD4), U1.50 (VDD1), U1.75 (VDD2), U1.100 (VDD3); also elsewhere on the board

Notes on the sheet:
PULLUPS & PULLDOWNS
LED's
STLINK
STLINK LED
RESET SW
OSCILLATOR CRYSTAL
5.0V -> 3.3V PS
OTG USB INTERFACE
STM32F407 CPU
STM32F407 PWR CIRCUIT
SmartMic Circuit Board
04/21/14
Added to SourceForge Repository
RGB
CHANGE LED VALUES IN BOM DB
Add RC & L filtering to I/O & PS
04/25/14
Pre-Release to Prototype
05/01/14
Release for Review

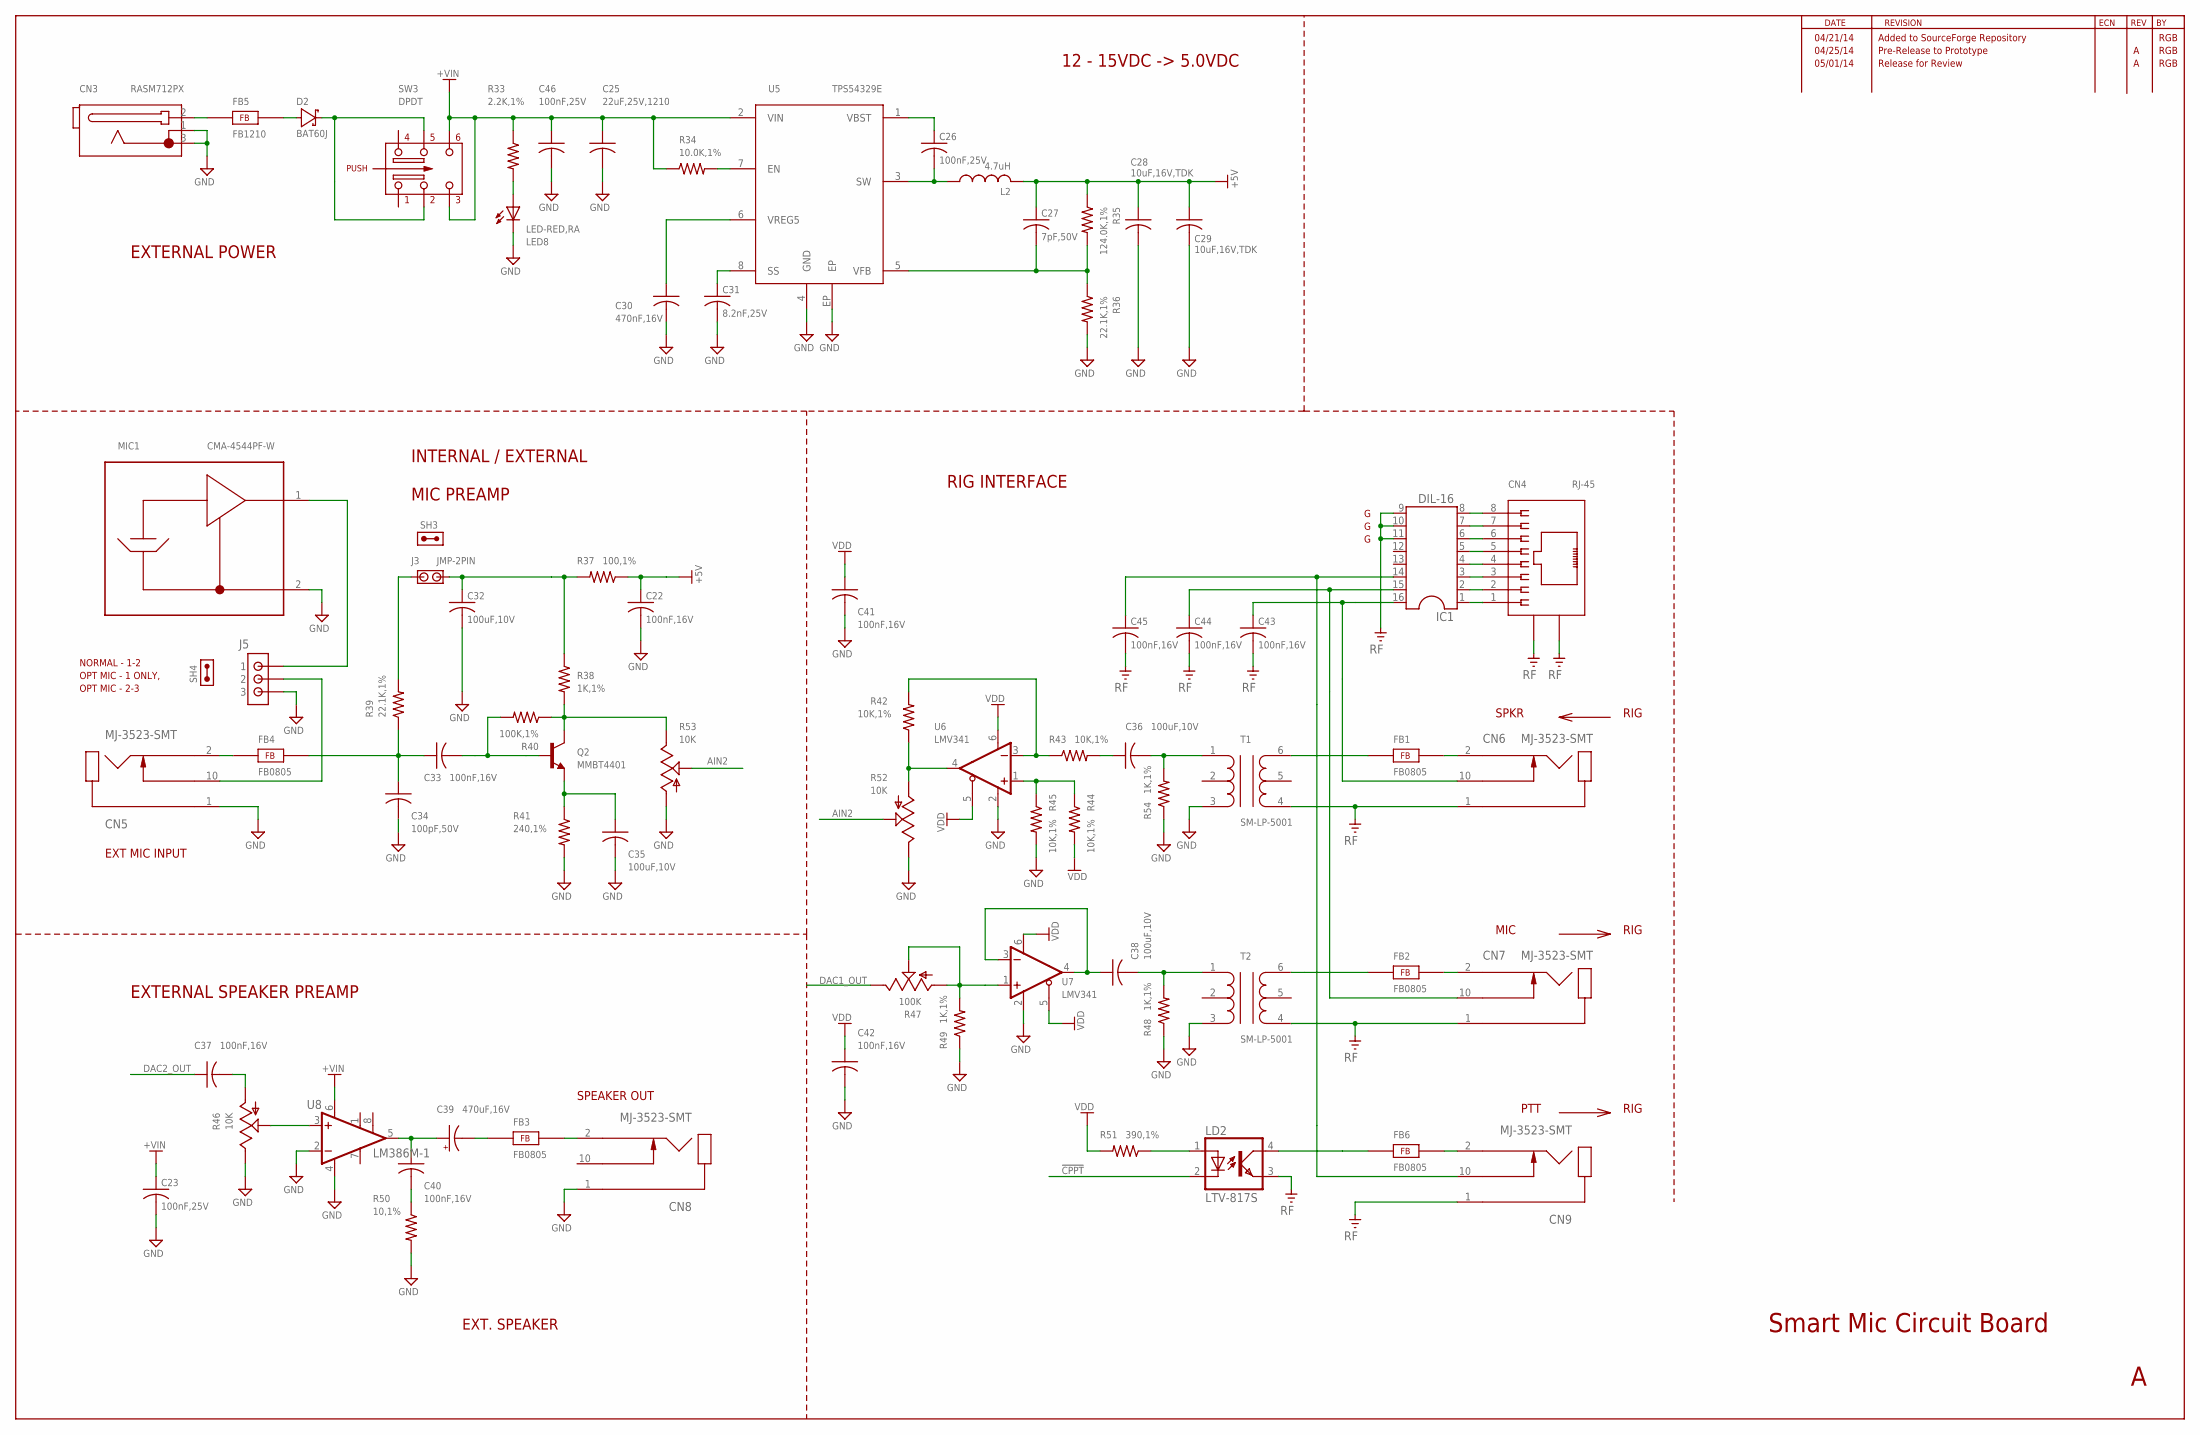
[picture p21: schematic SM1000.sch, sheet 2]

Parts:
C22, C33, C37, C40, C41, C42, C43, C44, C45: 100nF,16V; C0603
C23, C26, C46: 100nF,25V; C0603
C25: 22uF,25V,1210; C1210
C27: 7pF,50V; C0603
C28, C29: 10uF,16V,TDK; C1206
C30: 470nF,16V; C0603
C31: 8.2nF,25V; C0603
C32, C35, C36, C38: 100uF,10V; C1210
C34: 100pF,50V; C0603
C39: 470uF,16V; CAP-CHEMI-HA0
CN3: RASM712PX
CN4: RJ-45; CONN-RJ45-MOLEX-44144-003
CN5, CN6, CN7, CN8, CN9: MJ-3523-SMT
D2: BAT60J; SOD323R_INFINEON
FB1, FB2, FB3, FB4, FB6: FB0805; FE0805
FB5: FB1210; FE1210
IC1: DIL-16; SOCKET-16
J3: JMP-2PIN; JMPR-2PIN
J5: JMPR-3PIN
L2: 4.7uH; SRN6045
LD2: LTV-817S; SMD4
LED8: LED-RED,RA; LTST-S2200K
MIC1: CMA-4544PF-W
Q2: MMBT4401; SOT23
R33: 2.2K,1%; R0603
R34: 10.0K,1%; R0603
R35: 124.0K,1%; R0603
R36, R39: 22.1K,1%; R0603
R37: 100,1%; R0603
R38, R48, R49, R54: 1K,1%; R0603
R40: 100K,1%; R0603
R41: 240,1%; R0603
R42, R43, R44, R45: 10K,1%; R0603
R46: 10K; POT-3310C
R47: 100K; TRIMPOT91
R50: 10,1%; R0603
R51: 390,1%; R0603
R52, R53: 10K; TRIMPOT91
SH3, SH4: SHUNT,0.1IN; NOPACKAGE
SW3: DPDT; SW-PWR
T1, T2: SM-LP-5001
U5: TPS54329E; PSO-DDA
U6, U7: LMV341; SOT23-6
U8: LM386M-1; SO08

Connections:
!CPPT!: LD2.2 (C); also elsewhere on the board
+5V: C22.1, C27.1, C28.1, C29.1, L2.2, R35.1, R37.1; also elsewhere on the board
+VIN: C23.1, C25.1, C46.1, R33.1, R34.1, SW3.3, SW3.6, U5.2 (VIN), U8.6 (VS)
AIN2: R52.2, R53.2; also elsewhere on the board
DAC1_OUT: R47.1; also elsewhere on the board
DAC2_OUT: C37.1; also elsewhere on the board
GND: C22.2, C23.2, C25.2, C28.2, C29.2, C30.2, C31.2, C32.2, C34.2, C35.2, C41.2, C42.2, C46.2, CN3.1, CN3.3, CN5.1, CN8.1, J5.3, LED8.C, MIC1.2, R36.2, R41.2, R45.2, R46.1, R48.1, R49.1, R50.2, R52.1, R53.3, R54.1, T1.3, T2.3, U5.4 (GND), U5.EP, U6.2 (GND), U7.2 (GND), U8.2 (-IN), U8.4 (GND); also elsewhere on the board
MIC: C44.1, CN7.10, IC1.15
unnamed: C26.1, U5.1 (VBST)
unnamed: D2.A, FB5.2
unnamed: C33.1, C34.1, FB4.2, R39.1
unnamed: C27.2, R35.2, R36.1, U5.5 (VFB)
unnamed: J5.1, MIC1.1
unnamed: FB1.1, T1.6
unnamed: C37.2, R46.3
unnamed: C33.2, Q2.1 (B), R40.2
unnamed: C39.1, C40.1, U8.5 (OUT)
unnamed: C31.1, U5.8 (SS)
unnamed: R46.2, U8.3 (+IN)
unnamed: C30.1, U5.6 (VREG5)
unnamed: C35.1, Q2.2 (E), R41.1
unnamed: R34.2, U5.7 (EN)
unnamed: C40.2, R50.1
unnamed: C39.2, FB3.1
unnamed: J3.1, R39.2
unnamed: C32.1, J3.2, R37.2, R38.1
unnamed: LED8.A, R33.2
unnamed: R42.1, R52.3, U6.4 (OUT)
unnamed: LD2.1 (A), R51.1
unnamed: C36.1, R43.2
unnamed: CN4.8, IC1.8
unnamed: CN4.7, IC1.7
unnamed: CN4.6, IC1.6
unnamed: CN4.5, IC1.5
unnamed: CN4.4, IC1.4
unnamed: CN4.3, IC1.3
unnamed: CN4.2, IC1.2
unnamed: CN4.1, IC1.1
unnamed: R44.1, R45.1, U6.1 (+IN)
unnamed: CN5.10, J5.2
unnamed: FB2.1, T2.6
unnamed: R42.2, R43.1, U6.3 (-IN)
unnamed: C36.2, R54.2, T1.1
unnamed: CN6.2, FB1.2
unnamed: C38.2, R48.2, T2.1
unnamed: Q2.3 (C), R38.2, R40.1, R53.1
unnamed: C38.1, U7.3 (-IN), U7.4 (OUT)
unnamed: CN7.2, FB2.2
unnamed: CN9.2, FB6.2
unnamed: FB6.1, LD2.4 (COL)
unnamed: CN8.2, FB3.2
unnamed: CN5.2, FB4.1
unnamed: CN3.2, FB5.1
unnamed: D2.C, SW3.2, SW3.5
unnamed: R47.2, R47.3, R49.2, U7.1 (+IN)
PTT: C45.1, CN9.10, IC1.14
RF: C43.2, C44.2, C45.2, CN4.9, CN4.10, CN6.1, CN7.1, CN9.1, IC1.9, IC1.10, IC1.11, LD2.3 (EMIT), T1.4, T2.4
SPKR: C43.1, CN6.10, IC1.16
SW: C26.2, L2.1, U5.3 (SW)
VDD: C41.1, C42.1, R44.2, R51.2, U6.5 (!SHDN!), U6.6 (V+), U7.5 (!SHDN!), U7.6 (V+); also elsewhere on the board

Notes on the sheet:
SPKR
MIC
RIG
SPEAKER OUT
PTT
EXT MIC INPUT
EXTERNAL POWER
12 - 15VDC -> 5.0VDC
INTERNAL / EXTERNAL
MIC PREAMP
EXTERNAL SPEAKER PREAMP
RIG INTERFACE
Smart Mic Circuit Board
EXT. SPEAKER
NORMAL - 1-2
OPT MIC - 1 ONLY,
OPT MIC - 2-3
04/25/14
Pre-Release to Prototype
RGB
04/21/14
Added to SourceForge Repository
05/01/14
Release for Review

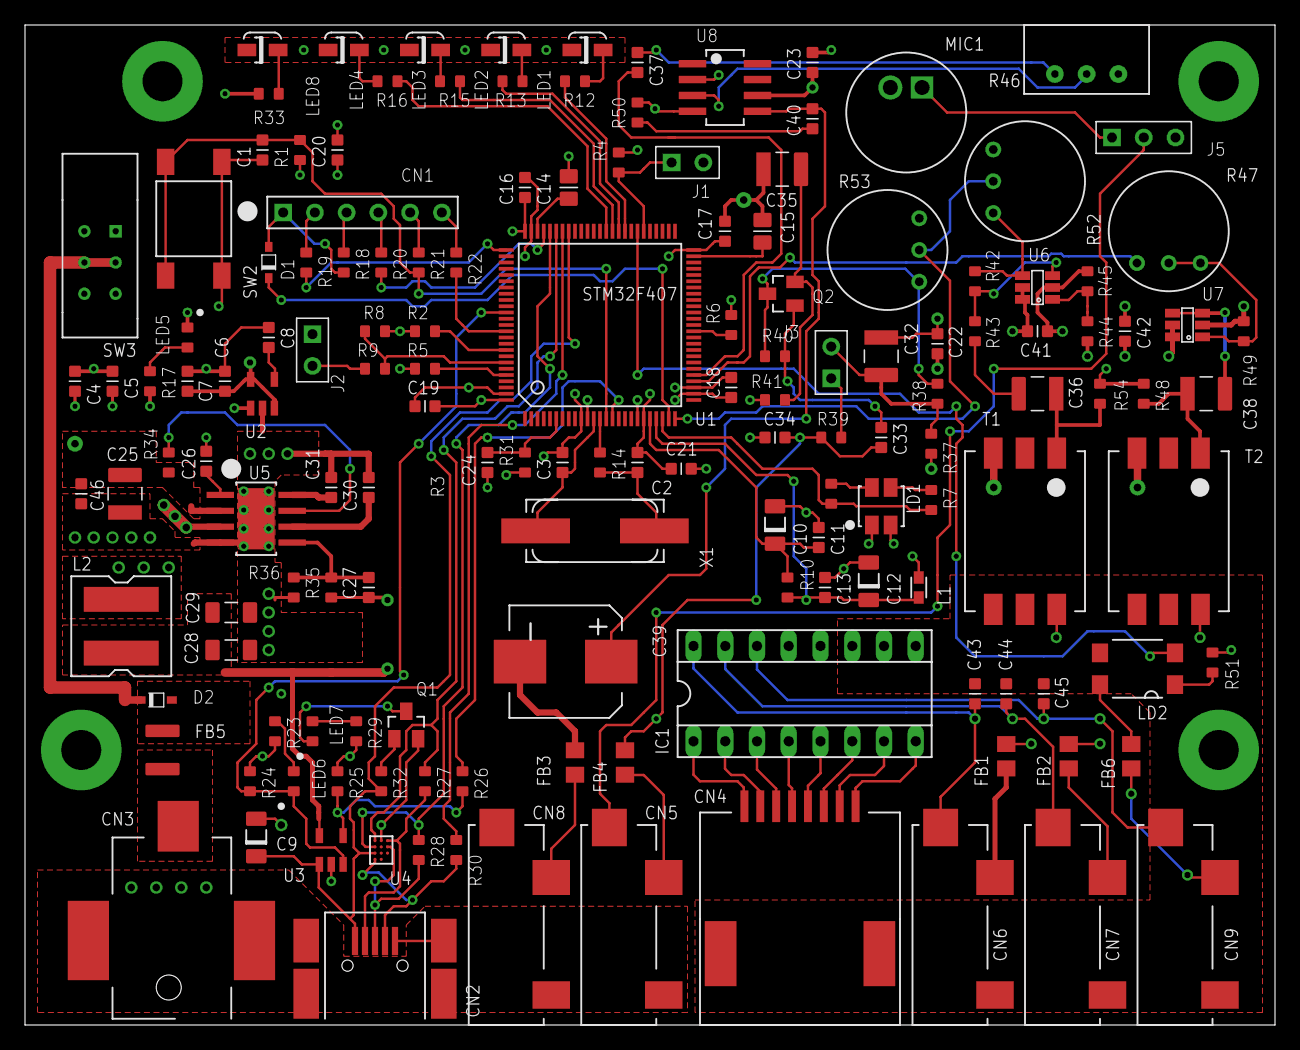
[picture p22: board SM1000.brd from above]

Board: 4 copper layers, 100.0 x 80.0 mm, 155 parts (0 on the bottom side), 111 nets.

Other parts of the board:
DRILEGEND: DRILEGEND

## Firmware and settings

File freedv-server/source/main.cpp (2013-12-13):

/*
 * For the sake of correctness and optimization, I have written whatever I can to be without
 * side-effects, a style inherited from functional programming. Thus, the excessive use of
 * "const". - Bruce
 */
#include <stdlib.h>
#include <string.h>
#include <iostream>
#include <getopt.h>
#include <codec2.h>
#include <codec2_fdmdv.h>

#include "drivers.h"

using namespace std;
namespace FreeDV {
  extern int run(struct Interfaces *);
}
using namespace FreeDV;


static void drivers()
{
  driver_manager.print(cout);
}

static void help(const char * name)
{
  static const char message[] = 
    " [options]\n"
    "\n\tWhere options are these flags:\n\n"
    "\t\t--drivers or -d\t\tPrint a list of the available device drivers.\n"
    "\t\t--help or -h\t\tPrint this message.\n"
    "\t\t--interface or -i\tSelect the user-interface (graphical or otherwise).\n"
    "\t\t--keying or -k\t\tSelect the transmitter keying interface.\n"
    "\t\t--loudspeaker or -l\tSelect the operator audio output interface.\n"
    "\t\t--microphone or -m\tSelect the operator audio input interface.\n"
    "\t\t--mode or -n\t\tSelect the codec mode and modulation.\n"
    "\t\t--ptt or -p\t\tSelect the push-to-talk input interface.\n"
    "\t\t--receiver or -r\tSelect the interface for audio input from the receiver.\n"
    "\t\t--text or -x\t\tSelect the interface for text to be transmitted.\n"
    "\t\t--transmitter or -t\tSelect the interface for audio output to the transmitter.\n"
    "\n\tLong flags with parameters are in the form of --<flag>=<parameter>\n"
    "\tShort flags with parameters are in the form of -<letter> <parameter>\n"
    "\n\tFor example, both of these flags have the same effect:\n"
    "\t\t-n 1600\n"
    "\t\t--mode=1600\n"
    "\n\tMode may be one of:\n"
    "\t\t1600\t\tNormal 1600 bit-per-second in 1.275 kHz RF bandwidth.\n"
    "\t\t1600-wide\t1600 bit-per-second in 2.125 kHz, wider guard-bands for improved\n"
    "\t\t\t\t\tDX performance.\n"
    "\n\tFlags used to select devices must have a \"<driver>:<parameter>\" argument\n"
    "\twhere <driver> is the name of a device driver for the selected input/output device,\n"
    "\tand <parameter> is the name or address of the selected device.\n"
    "\n\tExample:\n"
    "\t\t --loudspeaker=alsa:default\n"
  ;
  cerr << "\nUsage: " << name << message << endl;
}

static const struct option options[] = {
  { "drivers",		no_argument,	   0, 'd' },
  { "help",		no_argument,	   0, 'h' },
  { "interface",	required_argument, 0, 'i' },
  { "keying",		required_argument, 0, 'k' },
  { "loudspeaker",	required_argument, 0, 'l' },
  { "microphone",	required_argument, 0, 'm' },
  { "mode",		required_argument, 0, 'n' },
  { "ptt",		required_argument, 0, 'p' },
  { "receiver",		required_argument, 0, 'r' },
  { "text",		required_argument, 0, 'x' },
  { "transmitter",	required_argument, 0, 't' },
  { 0, 0, 0, 0 }
};

int
main(int argc, char * * argv)
{
  int		command;
  Interfaces	i;
  const char *	driver;
  const char *	parameter;

  if ( argc > 1 ) {
    while ((command = getopt_long(argc, argv, "dhi:k:l:m:n:p:r:t:x:", options, NULL)) != -1) {
      switch (command) {
      case 'i':
      case 'k':
      case 'l':
      case 'm':
      case 'p':
      case 'r':
      case 't':
      case 'x':
        char * const colon(index(optarg, ':'));

        if ( colon == 0 || colon[0] != ':' || colon[1] == 0 ) {
          cerr << argv[optind - 1] << ": Missing colon. Argument must be of the form \"<driver>:<parameter>\"" << endl;
          exit(1);
        }
	
        *colon = 0;
        driver = optarg;
        parameter = &colon[1];
      }

      switch (command) {
      case 'd':
        drivers();
        exit(0);
        break;
      default:
      case 'h':
        help(argv[0]);
        exit(1);
        break;
      case 'i':
        i.user_interface = driver_manager.user_interface(driver, parameter);
        break;
      case 'k':
        i.keying = driver_manager.keying(driver, parameter);
        break;
      case 'l':
        i.loudspeaker = driver_manager.audio_output(driver, parameter);
        break;
      case 'm':
        i.microphone = driver_manager.audio_input(driver, parameter);
        break;
      case 'n':
        i.mode = optarg;
        break;
      case 'p':
        i.ptt = driver_manager.ptt_input(driver, parameter);
        break;
      case 'r':
        i.receiver = driver_manager.audio_input(driver, parameter);
        break;
      case 't':
        i.transmitter = driver_manager.audio_output(driver, parameter);
        break;
      case 'x':
        i.text = driver_manager.text_input(driver, parameter);
        break;
      case 0:
        break;
      }
    }
  }
  else { // argc <= 1
    help(argv[0]);
    exit(1);
  }
  return run(&i);
}

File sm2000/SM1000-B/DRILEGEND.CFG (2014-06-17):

InputUserCfg = 1
SymbolLayer = 144
SymbolSize = 70
SymbolWidth = 4
TextSize = 70
TextRatio = 5
IdxFnt = 0
decMM = 2
decMIL = 0
SortHoles = 1
TolPlated = 0.02
TolNonPlated = 0.03
PlatedStatusNot = NOT
PlatedStatusBoth = BOTH
PlatedStatusYes = YES
VerticalChart = 1
HighCellFactor = 1.10
WideCellFactor = 1.10
CellOutline = 4
TitleOutline = 4
TableOutline = 8
SymbTitle = Sym
ToolTitle = N°
MMTitle = MM
MilTitle = Mils
MicTitle = Mic
QtyTitle = Qty
TypeTitle = Plated
ToleTitle = Tol
SymbRank = 1
ToolRank = 2
MMRank = 4
MilRank = 3
MicRank = 0
QtyRank = 5
TypeRank = 6
ToleRank = 0
OutputDrillRack = 0
DrillRackFile = DRILLRACK.DRL
Unit = 0
OutputUserCfg = 1
UserCfgFile = DRILEGEND.CFG

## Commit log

2014-06-18 Deleted REV-B to eliminate confusion. REV-B! are latest files - RGB (Just getting used to SVN)
    [BOM-SM1000-REV-B1.csv, BOM-SM1000-REV-B1.xls, DRILEGEND.CFG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]
2014-06-18 Update to correct for page missing on SCH-BM1000-EV-B1 schematic - RGB
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2014-06-30 UT to measure memory, and fixed to tfdmdv.c for new d/c + filter
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2014-07-18 Items 1-5,7-12,14-20 have been implemented in schematic . Items 6 & 13 need discussion to resolve. PCB has been updated to reflect changes, but routing of changes has not been completed. Layout will 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
    [SM1000-REV-B2.brd, SM1000-REV-B2.sch]
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2014-07-21 fdmdv stm32f4 UT working. mod fast enough but demod too slow, have traced to filtering.
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2014-08-03 optimised downconversion and filter, Octave and C working and also tweak to make fdmdv_demod_c plot correctly
2014-08-05 to freedv interface added the ability to determine demod sync and bit errors, better freedv_rx demo for txt and side info with log file, added switch driver and first pass at SM1000 main() program. C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
    [sm1000_main.c]
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2014-08-12 various tweaks and unit tests as SM1000 is brought up. ADC and DAC noise not too bad on loopbakc tests. Currently bombs when freedv_api called
    [sm1000_main.c]
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2014-08-14 Implemented Davids changes(21, 22 & 23) to schematic. Parts are in PCB, but not placed. RGB Updated Change Log RGB
    [SM1000-REV-B2.brd, SM1000-REV-B2.sch]
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2014-08-19 added -8-16 kHz sample rate conversion with shorts used for 16 kHz side
2014-08-19 made both args shorts for 8-16 kHz sample rate conversion
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2014-08-31 UT to measure rms noise on ADC ports
2014-09-04 Updated Folder name, Subfolder names and filenames to reflect Rev C status. RGB
    [SM1000-C.brd, SM1000-C.sch]
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2014-09-15 Changes to PCB & Schematic. Added ststus line to each Change-Log-C item to reflect current status. RGB 09/15/14
    [SM1000-C.brd, SM1000-C.sch]
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2014-09-16 fixed low level 256Hz tone bug, was init issue in DAC, thanks Rick and Michael and Matt for support and suggestions
    [sm1000_main.c]
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2014-10-04 Updateds per DRowe & Rbarnich RGB 10/04/14 Schematic & PCB 10/04/14 10:56AM
    [SM1000-C.brd, SM1000-C.sch]
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2014-10-07 Update 490 OHM -> 470 OHM Print both pages of schematics to PDF. RGB 10/07/14
    [SM1000-C.sch]
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2014-10-14 Recovery from Eagle ERC problem RGB
    [BOM-SM1000-C.xls, SM1000-C.brd, SM1000-C.sch]
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2014-10-15 insert errors handles codec frame sizes that are not multiples of 8 bits
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2014-10-20 Correct Schematic Part Values RGB
    [BOM-SM1000-C.xls, SM1000-C.brd, SM1000-C.sch]
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2014-10-21 Update Schemaatic, PCB & BOM to reflect change to 0402 package, Change 3.5mm conns to ST-3509 type RGB
    [BOM-SM1000-C.csv, BOM-SM1000-C.xls, SM1000-C.brd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]
2014-10-22 Update schematics, PCB & BOM for addition of 0402 part footprints - RGB
    [SM1000-C.brd, SM1000-C.sch]
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2014-10-24 10/24/2014 Update to Schematic, BOM & PCB - 10/24/2014 RGB Add Panasonic POTs Add Hirose A3C-16DA 2 x 8 female box header. Note: ST-3509 3.5mm connector cost unknown. Parts yet to be selected show $0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
    [BOM-SM1000-C.csv, BOM-SM1000-C.xls, SM1000-C.brd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]
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2014-10-28 Correct errors in last upload - RGB
    [SM1000-C.brd, SM1000-C.sch]
2014-10-30 Update Schematic & BOM for new Power Connector and Speaker - RGB
    [BOM-SM1000-C.csv, BOM-SM1000-C.xls, SM1000-C.brd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]
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2014-10-31 Update to ad images of each layer: L1 = TOP L2 = GND L3 = VDD + AVDD L4 = Bottom
    [EDWIN-BOM-SM1000-C - Questions.xls]
2014-10-31 Resolve conflicts
    [SM1000-C.brd, SM1000-C.sch]
2014-11-04 REPLACE 0603 WITH 0402 PACKGES. UPDATES TO SCH * BRD FILES RGB
    [BOM-SM1000-C.csv, BOM-SM1000-C.xls, SM1000-C.brd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]
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2014-11-18 Production Files for SM1000-C GERBER\GBR-SM!)))_C.zip is all gerber related file needed to manufacture PCB MFG\MFG-SM1000-C.zip contains all files needed to manufacture SM1000-C assembly. RGB - 11/18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
    [BOM-SM1000-C.csv, BOM-SM1000-C.xls, DRILEGEND.CFG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]
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2015-01-01 Renamed folder to reflect A Revision Should have originated in separate folder, not in SM1000-X. - RGB
    [LOC-SM1000-C.csv]
2015-01-01 few BOM issues to changelog
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2015-01-16 All files for SM1000-D PCB Gerber Folder Files for PCB fabrication MFG Folder Files for assembling PCB Documentation Check List.pdf
    [BOM-SM1000-D.csv, BOM-SM1000-D.xls, LOC-SM1000-D.csv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]
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2015-02-03 plotting FM signal noise power, fixed noise BW issue, ouputting error pattern file
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2015-03-03 Changed text legends to fit, SPKR VOLUME, rear panel logo. Ready for final review & release to manufacturing - RGB
    [ENCL-SM1000-C-BOTTOM.DWG, ENCL-SM1000-C-SIDE-PLATE.DWG, ENCL-SM1000-C-SILKSCREEN.DWG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]
2015-03-05 Change silkscree to fit Rwoetel logo on front & rear panel. Increased size of logos.
    [ENCL-SM1000-C-SILKSCREEN.DWG]
2015-03-07 Brady's first commit -IIR tner is fixed point -IIR tuner center changed to 700Khz -IIR Upconverter simulated in octave -STM32F4 DAC code copied and modified to support high sample rate on DAC1 (2Mhz)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
2015-03-26 double row of pilots helping with coarse/fine freq est, however sync time too long due to frame length.
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2015-04-08 noise samples unit var to support different Eb/No
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2015-05-09 cohpsk freq tracking unit test, integrated into tcohpsk and doing sensible things with +/- 0.5Hz/s freq drift
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2015-05-18 have resolved a few differences between C and Octave, bugs in logging code, Nsym filter length
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2015-05-26 cohpsk sample slip code interated into C and initial tests passing, need some better tests with C version of Fs offset simulation
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2015-05-28 21 [X] From Mel: DNL LED5 and LED8 to save a little power. DNL LED8 RGB DNL R33 DNL LED5 DNL R17
    [SM1000-E.brd, SM1000-E.sch]
2015-05-28 4. [X] Add part outlines to layer tdoc for documentation. Complete RGB
    [SM1000-E.brd, SM1000-E.sch]
2015-05-29 Added schematic power switch SW3 wiring change(.pngs) to accomodate PCB routing. Updated SM1000-E-change-log.txt file to reflect update and comments on #27 RGB
    [SM1000-E.brd, SM1000-E.sch]
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2015-06-05 PRODUCTION RELEASE FILES FOR SM1000-E FOLDER MFG-SM1000-E FOR BOARD ASSEMBLER FOLDER GERBER-SM1000-E FOR PCB MANUFACTURER FOLDER RELEASE-SM1000-E FOR BACKUP RGB 06/05/2015
    [BOM-SM1000-E.csv, BOM-SM1000-E.xls, DRILEGEND.CFG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]
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2015-06-26 UPDATE DESIGN TO FIX PROBLEM WITH SPKR CONN SHORTING AMPLIFIER TO GND WHEN MONO PLUG INSERTED.iNVOLVED CHANGES TO J2 & J4 CONNECTIONS TO CN8. RGB 6/26/15
    [BOM-SM1000-E.csv, BOM-SM1000-E.xls, DRILEGEND.CFG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]
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2015-06-27 Update pad & drill size on pin 7 of SW1 & SW3. RGB
    [DRILEGEND.CFG, LOC-SM1000-E.csv, LOC-SM1000-E.xls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]
2015-07-26 checkin after sourceforge outage, improved scatter diagram, remembers mode, blinking on from radio file playback and warning of sample rate with raw files and handling Fs=8000Hz sample rate wave file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
2015-07-26 fixed bug in 7500-8000Hz resampler
2015-07-27 fixed occasional wild bit error counts for cohpsk test frames
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2015-08-05 anti Git rant and some mods to c2sim to support playing with mel-lsps for a new improved rate 700 codec
    [cohpsk_frame_design.ods]
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2015-08-09 moved noise samples into src so we can consider rm-ing unittest for release code
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2015-08-21 wider bands in F1, improved handling of noise and hts2a, refactored into library plus frame by frame and batch scripts
2015-08-24 reworked linear fit of amplitude, and documented code a little. hts1a sounds OK with just 4 samples, with amplitudes fit to a linear line, ve9qrp_10s and vk5qi need some work
2015-08-25 trying out a new analysisi by synthesis method for choosing the location of samples. Works OK compared to local minima, still some background noise problems
2015-08-26 Missed codec2 on last branch/tag.
    [cohpsk_frame_design.ods]
2015-08-26 working on getting stm32 dir building again, put conditional defines in src to prevent 700 mode code being linked, and modified stm32/src for freedv api changes. stm32 Makefile runs OK but haven't te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
    [sm1000_main.c]
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2015-09-11 Update codec2 0.4 branch to include txt bit fix and tag 0.4.1.
    [cohpsk_frame_design.ods]
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2015-09-16 Show Schematic changes for CN12 pin swaps. RGB 09/16/15
    [SM1000-F.brd, SM1000-F.sch]
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2015-09-23 Accepted Stuart's patch to correct SM1000 build issue after freedv api change
    [sm1000_main.c]
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2015-09-24 sm1000_main: Use tone generator module for TONE mode.
    This replaces the old aSine array (now part of the tone module) with
    calls to make a continuous tone.
    [sm1000_main.c]
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2015-09-25 tone: Exploit sine-wave symmetry to save space.
    The sine wave basically can be divided into four quadrants, 0→0.5pi,
    0.5pi→pi, pi→1.5pi and 1.5pi→2pi. If we call these Q1, Q2, Q3 and Q4,
    we can see:
    - Q2 is basically Q1 in reverse
    - Q3 is Q1 negated
    - Q4 is Q2 negated
    We can therefore exploit this to store ¼ of the waveform. We do some if
    statement trickery to stitch the partial waveforms together. End result
    is we've now quadrupled the definition of our sine wave at minimal
    code-size cost.
    CPU wise is a wee bit more expensive, but still a lot better than
    actually calculating sine with a math library!
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2015-09-26 sm1000_main: Fix announcement of volume level
    [sm1000_main.c]
2015-09-26 sm1000_main: Fix logic error exiting 'VOL'
    Seems we were setting the dit time on the morse player instead of
    restoring the old volume setting.
    [sm1000_main.c]
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2015-09-26 sm1000_main: Add some logic involving the virtual EEPROM.
    Not working yet.
    [sm1000_main.c]
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2015-09-26 stm32f4_vrom: Fixes to writing out data.
    Numerous logic errors fixed. This time we succesfully write out blocks
    and mark them as being used.
2015-09-26 sm1000_main: Clear DAC buffer after playback.
    This seems to cure a "hanging note" issue when navigating menus.
    [sm1000_main.c]
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2015-09-27 stm32f4_vrom: Correct sector size.
    The sectors are 16kB, not 64kB. (Yes, brain fart moment yesterday.)
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2015-09-28 Update Schematic & board files. Add PDF of schematic for review. RGB
    [SM1000-F.brd, SM1000-F.sch]
2015-10-04 ADD PDFs of Schematics and board layers L1, L2, L3 & L4 for reference only. RGB 10/03/15
    [SM1000-F.brd, SM1000-F.sch]
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2015-10-04 FIX COMMIT PROBLEM RGB 10-04-5
    [SM1000-F.brd]
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2015-10-06 sm1000_main: First stab at a time-out timer.
    This needs calibration, but basically it cuts transmission after a fixed
    period, giving warning beeps in the time just prior to timeout.
    For now it is disabled by default, and the timing for now is way off.
    [sm1000_main.c]
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2015-11-07 user-defined Fs and broke out functions for BER counting, and file demod can now work with test frames and count BER
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2015-12-14 update after windows explorer problem RGB
    [BOM-SM1000-D.csv, BOM-SM1000-D.xls]
2015-12-14 Update from windows explorer problem RGB
    [BOM-ASSY-SM1000-D.xls]
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2015-12-15 ADD TIA SCHEMATIC AND UPDATE ROWETEL.LBR(FIX TXT SIZE). rgb
    [TIA.sch]
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2015-12-20 rename test to driver_pa, updated PA with RSD01MUS2 and 5th order cheby filter
    [driver_pa.sch]
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2015-12-22 added 1st mixer and RF switch sheet, some more notes to task list
    [1st_mixer_bpf_switch.sch]
2015-12-22 INTEGRATED 1ST MIXER BPF SWITCH INTO SM2000.SCH. CORRECTED CENTERING ON SOME COMPONENTS IN ROWETEL.LBR SHORTENED LEADS ON FB0805 SYMBOL. RGB
    [SM2000.brd, SM2000.sch]
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2015-12-23 aDDED lOCAL oSCILLATOR CIRCUITRY TO sm2000 sch. MOVED 3.3V PS TO SHT 4. CONTINUED SCHEMATIC CLEANUP RGB
    [SM2000.brd, SM2000.sch, local_osc.sch]
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2015-12-30 found 100Hz offset introduced while using for sm2000, that had broken Horus rtty
2015-12-30 Added Circuitry for +12_TX and +12V_RX. Need to add +12V_TX_ENB and +12V_RX_ENB to CPU. Used P-Channel mosfet for voltage SW and MMBT3904 to control sw(price). See Pg 3.
    [SM2000.brd, SM2000.sch]
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2016-01-04 Intermediate update: Fix resistor tolerances fix cap working voltages Fix some library items for no name & no value email Schematic Updates 01/01/2016 item 1. email Commits to SVN 01/02/2016 items 1,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
    [SM2000.brd, SM2000.sch]
2016-01-07 Update schematic. Moved new component footprints onto PCB Matched schematic to emailchange lists. reorganized circuitry blocks on pages. RGB
    [SM2000.brd, SM2000.sch]
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2016-01-15 Changes to schematics per emails of 1/12/2016 - 1/14/2016 per David Rowe.
    [SM2000.brd, SM2000.sch]
2016-01-18 Cleaned up schematic. Ran ERC with no errors. Started arranging parts on board. Have to add scope test points. A lot of parts to fit on PCB! RGB
    [SM2000.brd, SM2000.sch]
2016-01-19 RESTORE .SCH, .BRD, .EPF & .LBR FILES, DUE TO SNAFU ON THIS END.(THANKS DAVID) RGB
    [SM2000.brd, SM2000.sch]
2016-01-20 Added scope test points per signal list, Made edits per latest email(Jan 19,2016 03:31pm. Created scope test point symbol footprint and component. Edited rowetel.lbr to make resistor & capacitor comp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
    [SM2000.brd, SM2000.sch]
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2016-01-29 Made get_test_bits frame larger, corrected include in fsk.c
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2016-02-09 fmfsk.c now producing correct bits. found and fixed stupid error. octave unit test driver started.
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2016-03-13 Applied Jeroen's patch to fix issue with mode 1600 clicking and even frame decoding
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2016-04-13 Fixed crazy debug printf in freedv_tx
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2016-04-14 Fixed ADC sample rate issue in SM1000 main
    [sm1000_main.c]
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2016-06-18 correct -1 offset in timer divisor
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2016-10-10 Large patch from Danilo to (i) change some #define names to make them codec2-specific (ii) add an abstraction layer for ffts (iii) add ARM-specific FFTs for stm32 that doesn't help CPU laod but helps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
2016-11-05 Fixed issue with JSON printout
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2017-01-13 Fixed 800XA and switched over to the new 700C mode
2017-01-13 700B working again, still need to fix test frame mode
2017-01-14 correct sample rate fpor 700 B&C
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2017-01-19 current state, but having some problems with timing and phase offset interactions
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2017-02-03 fixed calculation of RF bandwidth thanks Steve
    [cohpsk_frame_design.ods]
2017-02-07 fixed occasional seg fault bug when 800XA starts due to test frames not being supported/inited
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2017-02-21 starting to instrument to further develop 700C. Added SNR field to channel settings, bar graphs for bit error counting on test frames, option to view 700C scatter before diversity combination, immedi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
2017-04-20 fine timing getting gd results (almost no IL) with no sample clock errors, and acceptable results at +/-500 and +/-1000ppm
2017-04-28 code for handling sample slips, tested with +/-500ppm clock offsets
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

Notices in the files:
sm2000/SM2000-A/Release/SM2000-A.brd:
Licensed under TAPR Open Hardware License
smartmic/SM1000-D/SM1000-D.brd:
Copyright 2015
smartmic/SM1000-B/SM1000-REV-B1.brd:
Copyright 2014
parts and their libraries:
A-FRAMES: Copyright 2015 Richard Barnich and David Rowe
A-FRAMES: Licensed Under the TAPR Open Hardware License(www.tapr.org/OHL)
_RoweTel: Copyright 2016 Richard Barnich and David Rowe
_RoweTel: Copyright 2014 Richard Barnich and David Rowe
